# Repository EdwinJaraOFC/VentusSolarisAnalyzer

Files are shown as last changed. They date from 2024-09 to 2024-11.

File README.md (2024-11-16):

<p align="left">
  
  <h1 align="center">VentusSolaris Analyzer: A Low-Cost Portable Kit for Renewable Energy Evaluation</h1>
</p>

## Descripción General

<p align="justify"><strong>VentusSolaris Analyzer</strong> es una solución portátil de bajo costo diseñada para evaluar el potencial de energías renovables en diversas ubicaciones. Este kit combina la medición de energía solar y eólica, ofreciendo a estudiantes, investigadores y profesionales una herramienta accesible para obtener datos precisos y en tiempo real.</p>

<p align="justify">Concebido dentro de un entorno académico, este proyecto tiene como objetivo acercar la tecnología de análisis de energías renovables a aquellos interesados en el impacto y la viabilidad de estas soluciones en diferentes regiones.</p>

### ODS 7: Energía Asequible y no Contaminante

<p align="justify">Tiene como objetivo garantizar el acceso a una energía asequible, fiable, sostenible y moderna para todos. Este objetivo busca aumentar la proporción de energía renovable en el consumo global, mejorar la eficiencia energética y proporcionar acceso a servicios energéticos básicos, especialmente en regiones rurales y en desarrollo. Además, fomenta la inversión en infraestructura y tecnologías de energía sostenible, contribuyendo así a la lucha contra el cambio climático y a la promoción de un desarrollo económico inclusivo.</p>

## Características Principales

- 🌞 **Energía Solar**: Medición eficiente de la radiación solar.
- 🌬️ **Energía Eólica**: Monitorización de la velocidad del viento para evaluar el potencial eólico.
- 📊 **Interfaz Intuitiva**: Presentación clara y visualización de los datos recopilados.
- 💼 **Portabilidad**: Diseño compacto y ligero, ideal para trabajos de campo.
- 💡 **Accesibilidad**: Tecnología asequible sin comprometer la precisión ni la funcionalidad.

## Estructura del Proyecto

```bash
VentusSolarisAnalyzer/
├── AcercaDeNosotros/       # Información sobre el equipo o el propósito del proyecto
├── Documentacion/          # Documentación técnica y material explicativo del proyecto
│   ├── Investigacion/      # Estudios y análisis preliminares
│   ├── Presentaciones/     # Material gráfico y de presentación
│   ├── Talleres/           # Documentación y recursos de talleres
│
├── Prototipo/              # Detalles del prototipo del proyecto
│   ├── Diseño/             # Planos, esquemas y documentación de diseño
│   ├── Hardware/           # Especificaciones y esquemas del hardware
│   ├── Software/           # Código fuente y documentación del software
│   ├── Tests/              # Resultados y documentación de pruebas del prototipo
│
├── .gitignore              # Archivos y carpetas ignorados por Git
├── LICENSE                 # Licencia del proyecto
└── README.md               # Este archivo principal con información general del proyecto
```

## Motivación y Contexto
<p align="justify">El acceso a herramientas confiables para la evaluación de energías renovables suele estar limitado por altos costos y falta de accesibilidad. VentusSolaris Analyzer nace con la intención de democratizar la evaluación energética, proporcionando una alternativa portátil y económica que puede ser implementada en áreas urbanas o rurales.</p>

<p align="justify">Este proyecto también responde a la necesidad académica de ofrecer a los estudiantes experiencias prácticas en el uso de tecnologías renovables, facilitando la comprensión de conceptos como energía solar fotovoltaica y energía eólica en escenarios reales.</p>

## Resultados Esperados
Con VentusSolaris Analyzer, se espera lograr:

- Datos precisos en la medición de energías renovables en diferentes entornos.
- Facilidad de uso en investigaciones de campo, donde la portabilidad es clave.
- Prototipos escalables, que puedan mejorarse y adaptarse a necesidades más complejas en futuras iteraciones.

<p align="justify">Estos logros contribuirán no solo al campo académico, sino también a la posibilidad de implementación en proyectos de desarrollo sostenible en comunidades con acceso limitado a recursos energéticos.</p>

## Nuestro Equipo

| Miembro | Rol | Función Principal | Correo |
| :---: | :---: | :---: | :---: |
| **Florian Párraga, Josué Abel** | Desarrollo Técnico | Prototipado y desarrollo técnico | josue.florian@upch.pe |
| **Jara Bocanegra, Edwin Junior** | Desarrollo Técnico | Prototipado y desarrollo técnico | edwin.jara@upch.pe |
| **Pérez Amado, Romina Alisson** | Investigación | Investigación sobre energías renovables | romina.perez@upch.pe |
| **Pérez Damián, Cindy Mayomi** | Investigación | Investigación sobre energías renovables | cindy.perez@upch.pe |
| **Vásquez Nuñez, America Mailyn** | Investigación | Investigación sobre energías renovables | america.vasquez@upch.pe |

## Documentación y Recursos
<p align="justify">Toda la documentación técnica y manuales de usuario pueden encontrarse en la carpeta docs/, donde se detalla el funcionamiento interno del sistema, guías de uso y especificaciones de hardware. Además, en la carpeta examples/ se incluyen ejemplos para facilitar la configuración del kit en diferentes entornos.</p>

## Identificación del TRL del Proyecto
### Motor DC para el anemómetro

<p align="justify">En este proyecto, se va a medir la velocidad del viento en (m/s) mediante un sistema basado en un anemómetro conectado a un motor. El funcionamiento del sistema se activa cuando el viento hace girar las hélices del anemómetro. Estas hélices, al girar, no solo registran el movimiento del viento, sino que también generan electricidad al cortar las líneas del campo magnético en el motor. Este proceso, a través del motor DC nos permite generar una corriente eléctrica que se relaciona directamente con la velocidad del viento, facilitando así una medición precisa a partir del voltaje generado.</p>
  
<p align="center">
  
</p>

### Sensor de radiación

<p align="justify">En este proyecto, vamos a medir uno de los parámetros qué es  la irradiancia solar, a través del sensor de 527-SUF268J00, el cual mide la irradiación en watts por metro cuadrado (W/m²). Este sensor funciona mediante la captura de luz solar que incide sobre un material semiconductor, comúnmente silicio. La energía de los fotones de la luz excita los electrones en el semiconductor, creando pares de electrones y huecos. Al separarse, estos generan una corriente eléctrica; cuanto mayor es la luz recibida, mayor es la corriente producida. Esta corriente se convierte en un voltaje que representa la cantidad de luz que está recibiendo el sensor. Para garantizar que las lecturas sean precisas. Además, cuenta con recubrimientos protectores que resguardan su funcionamiento frente a la humedad y la radiación UV, asegurando así su durabilidad y eficacia en diversas condiciones ambientales.</p>

Especificaciones técnicas: 

- Fuente de luz: Luz del sol
- Método de conexión: 2-Pin
- Configuración de salida: Fotodiodo
- Temperatura de trabajo mínima: -30 C
- Temperatura de trabajo máxima: +80 C
- Características: Tiempo de respuesta rápido

<p align="center">
  
</p>

### Sensor de Ondas de Radio

<p align="justify">El funcionamiento del sensor de ondas de radio, es fundamental para la recepción de señales que viajan a través del aire. Este sensor utiliza una antena para captar las ondas de radio, que son oscilaciones electromagnéticas. Cuando estas ondas llegan a la antena, inducen el movimiento de electrones en el material conductor de la antena, lo que genera pequeñas corrientes eléctricas. Estas corrientes son directamente proporcionales a la energía de las ondas de radio que están siendo recibidas. La corriente generada se convierte en una señal eléctrica que representa la información contenida en las ondas, como voz, música o datos digitales. Esta señal eléctrica se amplifica para mejorar su calidad y se procesa mediante circuitos electrónicos que extraen la información deseada.</p>

Especificaciones técnicas:

- Voltaje de alimentación: 1.9 ~ 3.6V DC
- Voltaje lógico SPI: 0 ~ 3.3V / 5V (Tolerante a 5V)
- Consumo corriente: 115 mA (max.)
- Chip RF: NRF24L01+
- Chip PA+LNA: RFX2401C
- Interfaz digital: SPI
- Potencia de transmisión: +20 dBm
  
<p align="center">
  
</p>

## Licencia
<p align="justify">Este proyecto está licenciado bajo la Licencia Apache-2.0, lo que permite su uso, modificación y distribución para fines académicos y comerciales, siempre y cuando se otorgue el crédito adecuado.</p>

## Contacto
<p align="justify">Si tienes alguna duda, sugerencia o interés en colaborar con el proyecto, no dudes en ponerte en contacto con nosotros a través de nuestros correos electrónicos.</p>

<a href="https://github.com/EdwinJaraOFC/VentusSolarisAnalyzer/blob/main/AcercaDeNosotros/README.md">Haz click aquí</a>
</p>

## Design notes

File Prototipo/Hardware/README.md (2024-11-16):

<p align="left">
  
  <h1 align="center">Hardware</h1>
</p>

<p align="justify">Esta carpeta incluye toda la documentación y recursos técnicos relacionados con los componentes físicos y electrónicos del proyecto VentusSolaris Analyzer. Aquí se detalla desde el diseño esquemático hasta los planos finales necesarios para la construcción del prototipo.</p>

## Contenido

- <strong>H01EsquematicoElectronico:</strong> Diagramas de circuitos electrónicos que representan las conexiones y componentes principales.

- <strong>H02ModeladoPCB:</strong> Diseño de las placas de circuito impreso (PCB) utilizadas en el prototipo.

- <strong>H03Modelado3D:</strong> Modelos tridimensionales de los componentes y estructuras físicas.

- <strong>H04Planos:</strong> Planos detallados con especificaciones técnicas para la fabricación del hardware.

## Uso

- Revisa los esquemáticos electrónicos para entender las conexiones del circuito.
- Consulta el modelado PCB para la fabricación y ensamblaje de las placas.
- Explora los modelos 3D para visualizar y evaluar la estructura física del hardware.
- Utiliza los planos como guía técnica para la construcción del prototipo.

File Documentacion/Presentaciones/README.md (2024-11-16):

<p align="left">
  
  <h1 align="center">Presentaciones</h1>
</p>

<p align="justify">Esta carpeta incluye materiales visuales diseñados para comunicar el alcance, los fundamentos y los resultados del proyecto VentusSolaris Analyzer. Estos recursos son ideales para exposiciones académicas, reuniones técnicas y presentaciones públicas.</p>

## Contenido

- <strong>Fundamentos de Diseño:</strong> Diapositivas explicativas sobre los principios y conceptos clave del diseño del proyecto.

- <strong>Proyectos de Ingeniería:</strong> Presentaciones que destacan el impacto técnico y la implementación del prototipo.

## Uso

<p align="justify">Selecciona la carpeta correspondiente según el contexto de tu presentación para acceder a los materiales preparados. Estos recursos están organizados para facilitar la adaptación a diferentes audiencias y escenarios.</p>

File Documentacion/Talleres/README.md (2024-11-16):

<p align="left">
  
  <h1 align="center">Talleres</h1>
</p>

<p align="justify">Esta carpeta contiene materiales y recursos relacionados con los talleres impartidos en los cursos Fundamentos de Diseño y Proyectos de Ingeniería 1. Estos talleres están enfocados en brindar a los estudiantes conocimientos prácticos sobre el desarrollo de proyectos tecnológicos, desde la conceptualización hasta la implementación.</p>

## Contenido

### Taller 01 al Taller 09

<p align="justify">Cada taller está diseñado para profundizar en conceptos clave relacionados con el desarrollo de proyectos tecnológicos, incluyendo:</p>

- Metodologías de diseño.
- Selección y uso de tecnologías apropiadas.
- Gestión y planificación de proyectos.
- Resolución de problemas técnicos.

## Uso

1. <strong>Selecciona el taller correspondiente al curso y tema de interés:</strong> Los talleres están organizados en secuencia para facilitar el aprendizaje progresivo.

2. <strong>Explora los materiales dentro de cada taller:</strong> Incluyen guías, ejercicios prácticos y ejemplos relevantes.

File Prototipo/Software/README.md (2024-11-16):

<p align="left">
  
  <h1 align="center">Código Fuente</h1>
</p>

Esta carpeta contiene el código fuente del proyecto **VentusSolaris Analyzer**.

## Estructura

- **`main.py`**: Archivo principal para ejecutar el sistema.
- **Módulos**:
  - `sensor_solar.py`: Control y procesamiento de datos del sensor solar.
  - `sensor_eolico.py`: Control y procesamiento de datos del sensor eólico.
  - `interface.py`: Interfaz para mostrar los datos recopilados.

## Cómo Ejecutar

1. Asegúrate de tener instaladas las dependencias necesarias:
   ```bash
   pip install -r requirements.txt

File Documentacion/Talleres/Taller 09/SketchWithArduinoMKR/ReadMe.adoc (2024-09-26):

:Author: alumno_upch
:Email:
:Date: 19/09/2024
:Revision: version#
:License: Public Domain

= Project: {Project}

Describe your project

== Step 1: Installation
Please describe the steps to install this project.

For example:

1. Open this file
2. Edit as you like
3. Release to the World!

== Step 2: Assemble the circuit

Assemble the circuit following the diagram layout.png attached to the sketch

== Step 3: Load the code

Upload the code contained in this sketch on to your board

=== Folder structure

....
 sketch123                => Arduino sketch folder
  ├── sketch123.ino       => main Arduino file
  ├── schematics.png      => (optional) an image of the required schematics
  ├── layout.png          => (optional) an image of the layout
  └── ReadMe.adoc         => this file
....

=== License
This project is released under a {License} License.

=== Contributing
To contribute to this project please contact: 

=== BOM
Add the bill of the materials you need for this project.

|===
| ID | Part name      | Part number | Quantity
| R1 | 10k Resistor   | 1234-abcd   | 10       
| L1 | Red LED        | 2345-asdf   | 5        
| A1 | Arduino Zero   | ABX00066    | 1        
|===

=== Help
This document is written in the _AsciiDoc_ format, a markup language to describe documents. 
If you need help you can search the http://www.methods.co.nz/asciidoc[AsciiDoc homepage]
or consult the http://powerman.name/doc/asciidoc[AsciiDoc cheatsheet]

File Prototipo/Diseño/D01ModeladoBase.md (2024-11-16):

<p align="left">
  
  <h1 align="center">Modelado Base</h1>
</p>

## Proyecto Ganador y Pretotipo
<p align="center">
  
  
</p>

## Dimensiones Preliminares
<p align="center">
  
  
</p>
<p align="center">
  
</p>

## Modelado 3D

- **Link de Modelado 3D en Onshape:**<br>https://cad.onshape.com/documents/6067460ba82017ad390b8bbe/w/b210f3430e2e64227f715d53/e/26216eeab57c46d8af5b41a8
- **Link de Modelado 3D en SketchFab:**<br>https://skfb.ly/oQHG9
<p align="center">
  
  
</p>

## Tabla de Componentes
<p align="center">
  
</p>

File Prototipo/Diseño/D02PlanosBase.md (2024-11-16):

<p align="left">
  
  <h1 align="center">Planos del Modelado 3D</h1>
</p>

<a href="https://github.com/Paradoxeado/prototypeProject/tree/main/Prototipado/Hardware">Carpeta de Componentes 3D y Planos</a>
</p>

## Plano: Maleta

<p align="center">
  
</p>

## Plano: Tapa para la Batería Portátil

<p align="center">
  
</p>

## Plano: Tapa de la Caja del Anemómetro

<p align="center">
  
</p>

## Plano: Anemómetro

<p align="center">
  
</p>

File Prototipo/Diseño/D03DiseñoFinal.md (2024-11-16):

<p align="left">
  
  <h1 align="center">Diseño Final del Proyecto</h1>
</p>

## Acerca de nuestro Modelado 3D

<p align="center">
  
  
</p>

## Esquemático Electrónico

<p align="center">
  
</p>
<p align="center">
  
</p>
<a href="https://github.com/Paradoxeado/prototypeProject/blob/main/Prototipado/Hardware/EsquematicoElectronico.pdf">Enlace al Esquemático Electrónico en formato PDF</a>
</p>
<p align="center">
  
</p>

## Diagrama de Flujo

<a href="https://github.com/Paradoxeado/prototypeProject/blob/main/Prototipado/Software/DiagramaDeFlujo.pdf">Enlace al Diagrama de Flujo en formato PDF</a>
</p>

<p align="center">
  
</p>

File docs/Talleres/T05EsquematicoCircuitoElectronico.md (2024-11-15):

<p align="center" style="margin-top: 50px; margin-bottom: 50px; font-family: Arial, sans-serif;">
  <p align="center">
    Facultad de Ciencias e ingeniería logo
  </p>  
  <h1 align="center" style="margin-top: 30px; margin-bottom: 0px;">Facultad de Ciencias e ingeniería “Alberto Cazorla Talleri”</h1>
</p>

<h2 align="center" style="font-family: Arial, sans-serif;">Taller 05: Esquemático del Circuito Electrónico</h2>

<strong> Docentes:</strong>
- Mg Umbert Lewis De La Cruz
- Mg. Paulo Camilo Vela Antón 
- Mg. Moises Stevend Meza Rodriguez 
- Dr. Harry Anderson Rivera Tito 
- Ing. Juan Manuel Zuñiga Mamani  
- Ing. Renzo José Chan Ríos

<strong>Elaborado por:</strong>
- Amparo Marleny Vidaurre Juárez
- Edwin Junior Jara Bocanegra
- Antony Iván Mendoza Villar
- Josue Jhordan Poma Arrieta
- Aracely Nicoll Dueñas Condori
</p>

<hr style="border: 1px solid #ccc; margin-top: 50px; margin-bottom: 50px;">

## 1. Introducción
<p align="justify">
Un esquemático de un circuito electrónico es un dibujo que representa los componentes del circuito y cómo están conectados entre sí. Es una herramienta visual que facilita la comprensión y el diseño de circuitos electrónicos. En un esquemático, los componentes como resistencias, capacitores, transistores, etc., se representan con símbolos estandarizados.
</p>

## 2. Descripción del sistema de circuito electrónico
### Características y componentes del el sistema de circuito electrónico
<p align="justify">
  
- **Componentes electrónicos:** Incluyen resistencias, capacitores, inductores, diodos, transistores, circuitos integrados, entre otros.
- **Fuente de alimentación:** Proporciona la energía necesaria para que el circuito funcione correctamente.
- **Conectores y terminales:** Permiten la conexión física del circuito con otros dispositivos o sistemas.
- **Circuitos integrados:** Chips que contienen múltiples componentes electrónicos en un solo paquete.
- **Placas de circuito impreso (PCB):** Proporcionan la estructura física para montar y conectar los componentes electrónicos de forma ordenada.
- **Conexiones eléctricas:** Representan cómo se conectan los componentes entre sí para que el circuito funcione según el diseño.
</p>

### Importancia del sistema de circuito electrónico

<p align="justify">
Los sistemas de circuitos electrónicos son fundamentales para el desarrollo y funcionamiento de la tecnología moderna, desempeñando un papel crucial en nuestra vida cotidiana y en el progreso de la sociedad en su conjunto.
</p>

## 3. Ejercicios
### Ejercicio 1: Crear un sistema que pueda encender un LED
<p align="justify">
Con la ayuda del docente, pudimos crear un sistema el cual puede encender un led con los siguientes  implementos, resistencia genérica, led y un terminal de tornillo de 2 posiciones.
</p>

<div align="center"; style="display: flex; justify-content: space-between;">
  
  
  
</div>

<p align="justify">
Posteriormente, modificamos el valor de la resistencia a 330 ohmios para optimizar el circuito.
</p>

<div align="center"; style="display: flex; justify-content: space-between;">
  
</div>

<p align="justify">

A continuación, procedimos a unir los componentes siguiendo los siguientes pasos:
- Conectar una de las cables del LED al terminal de tornillo.
- Conectar la resistencia de 330 ohmios a la otra pata del LED.
- Conectar el extremo libre de la resistencia al otro terminal del tornillo.
- Finalmente, asegurar que todas las conexiones estén firmes y seguras.
</p>

<div align="center"; style="display: flex; justify-content: space-between;">
  
</div>

<p align="justify">
  
**Vista Previa en 2D**
</p>

<div align="center"; style="display: flex; justify-content: space-between;">
  
</div>

<p align="justify">

**Vista Previa en 3D**
</p>

<div align="center"; style="display: flex; justify-content: space-between;">
  
  
  
</div>

### Ejercicio 2: Crear un circuito que guarde relación con nuestro proyecto
<p align="justify">
El circuito desarrollado para este ejercicio ha sido diseñado para complementar y potenciar los objetivos de nuestro proyecto principal. Su función principal es activar un LED mediante un botón o pulsador, desempeñando un papel esencial en el logro de nuestros objetivos. Se ha asegurado una integración perfecta con la arquitectura general del proyecto, garantizando una sinergia fluida entre todos los componentes. Además, se ha prestado especial atención a la modularidad, lo que facilita su expansión o adaptación futura según sea necesario.
</p>

<p align="justify">
Para la construcción de este circuito, hemos seleccionado cuidadosamente los siguientes componentes, cada uno desempeñando un papel crucial en el funcionamiento del sistema:

- 3 Resistencias de 330 ohmios
- 2 Botones/pulsadores
- 1 ESP32
- 1 LED

Al ensamblar estos componentes en el circuito, hemos prestado especial atención a la calidad de las conexiones eléctricas, evitando cualquier posibilidad de falsos contactos que puedan afectar el rendimiento del sistema. Quedando el circuito de la siguiente manera:
</p>

**Vista Previa en 2D**
<div align="center"; style="display: flex; justify-content: space-between;">
  
  
</div>

**Vista Previa en 3D**
<div align="center"; style="display: flex; justify-content: space-between;">
  
  
</div>
<div align="center"; style="display: flex; justify-content: space-between;">
  
  
</div>

## 4. Evidencias del desarrollo de ejercicios

<div align="center"; style="display: flex; justify-content: space-between;">
  
</div>

## 5. Conclusión
<p align="justify">
Finalmente ,en nuestro taller, aprendimos a utilizar las funciones de Flux.ai para diseñar un sistema que encienda un LED y conectar un ESP32 a una pantalla LCD con las resistencias necesarias. Además, exploramos cómo añadir funcionalidades adicionales mediante la programación de circuitos. Con estos conocimientos, podemos crear proyectos electrónicos de manera más eficiente y estética.
</p>

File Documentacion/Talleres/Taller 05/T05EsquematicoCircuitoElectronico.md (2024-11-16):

<p align="left">
  
  <h1 align="center">Taller 05: Esquemático del Circuito Electrónico</h1>
</p>

## 1. Introducción
<p align="justify">
Un esquemático de un circuito electrónico es un dibujo que representa los componentes del circuito y cómo están conectados entre sí. Es una herramienta visual que facilita la comprensión y el diseño de circuitos electrónicos. En un esquemático, los componentes como resistencias, capacitores, transistores, etc., se representan con símbolos estandarizados.
</p>

## 2. Descripción del sistema de circuito electrónico
### Características y componentes del el sistema de circuito electrónico
<p align="justify">
  
- **Componentes electrónicos:** Incluyen resistencias, capacitores, inductores, diodos, transistores, circuitos integrados, entre otros.
- **Fuente de alimentación:** Proporciona la energía necesaria para que el circuito funcione correctamente.
- **Conectores y terminales:** Permiten la conexión física del circuito con otros dispositivos o sistemas.
- **Circuitos integrados:** Chips que contienen múltiples componentes electrónicos en un solo paquete.
- **Placas de circuito impreso (PCB):** Proporcionan la estructura física para montar y conectar los componentes electrónicos de forma ordenada.
- **Conexiones eléctricas:** Representan cómo se conectan los componentes entre sí para que el circuito funcione según el diseño.
</p>

### Importancia del sistema de circuito electrónico

<p align="justify">
Los sistemas de circuitos electrónicos son fundamentales para el desarrollo y funcionamiento de la tecnología moderna, desempeñando un papel crucial en nuestra vida cotidiana y en el progreso de la sociedad en su conjunto.
</p>

## 3. Ejercicios
### Ejercicio 1: Crear un sistema que pueda encender un LED
<p align="justify">
Con la ayuda del docente, pudimos crear un sistema el cual puede encender un led con los siguientes  implementos, resistencia genérica, led y un terminal de tornillo de 2 posiciones.
</p>

<div align="center"; style="display: flex; justify-content: space-between;">
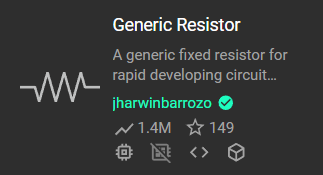
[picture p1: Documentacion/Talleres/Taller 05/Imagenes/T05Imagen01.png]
  
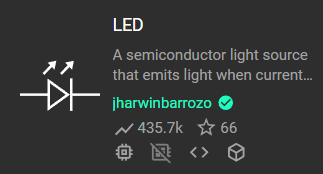
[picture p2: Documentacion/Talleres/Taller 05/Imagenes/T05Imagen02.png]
  
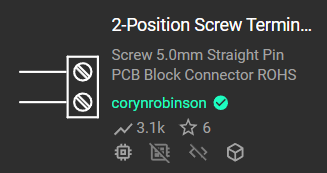
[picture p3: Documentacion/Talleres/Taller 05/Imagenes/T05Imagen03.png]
  
</div>

<p align="justify">
Posteriormente, modificamos el valor de la resistencia a 330 ohmios para optimizar el circuito.
</p>

<div align="center"; style="display: flex; justify-content: space-between;">
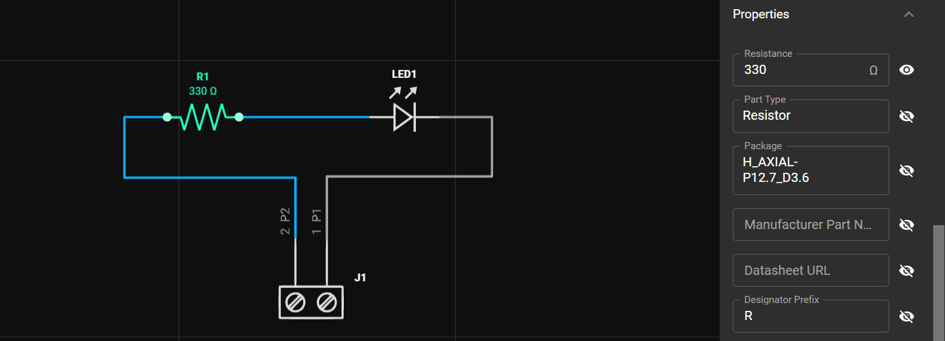
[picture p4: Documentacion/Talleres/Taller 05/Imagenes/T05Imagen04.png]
  
</div>

<p align="justify">

A continuación, procedimos a unir los componentes siguiendo los siguientes pasos:
- Conectar una de las cables del LED al terminal de tornillo.
- Conectar la resistencia de 330 ohmios a la otra pata del LED.
- Conectar el extremo libre de la resistencia al otro terminal del tornillo.
- Finalmente, asegurar que todas las conexiones estén firmes y seguras.
</p>

<div align="center"; style="display: flex; justify-content: space-between;">
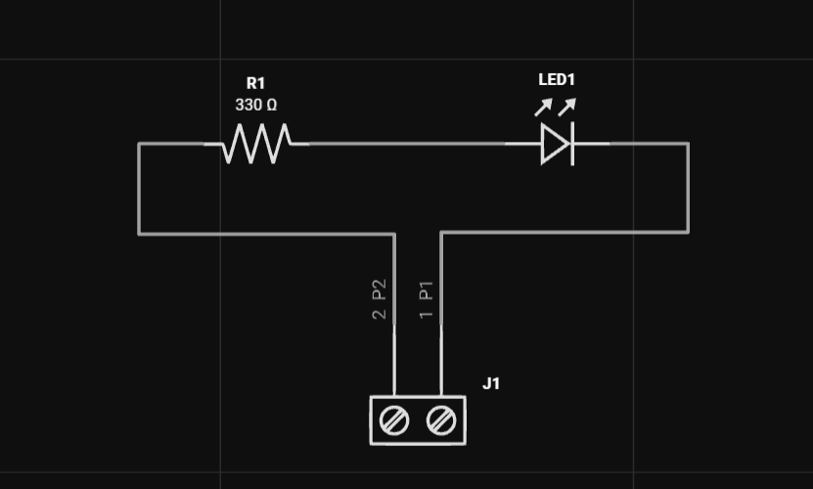
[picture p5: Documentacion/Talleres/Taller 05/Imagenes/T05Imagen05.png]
  
</div>

<p align="justify">
  
**Vista Previa en 2D**
</p>

<div align="center"; style="display: flex; justify-content: space-between;">
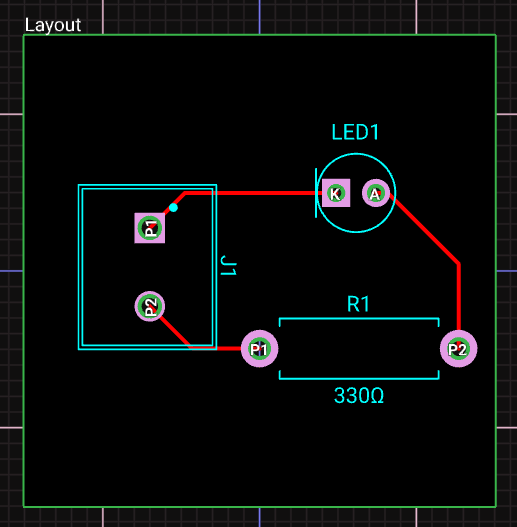
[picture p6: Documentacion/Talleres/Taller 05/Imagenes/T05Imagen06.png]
  
</div>

<p align="justify">

**Vista Previa en 3D**
</p>

<div align="center"; style="display: flex; justify-content: space-between;">
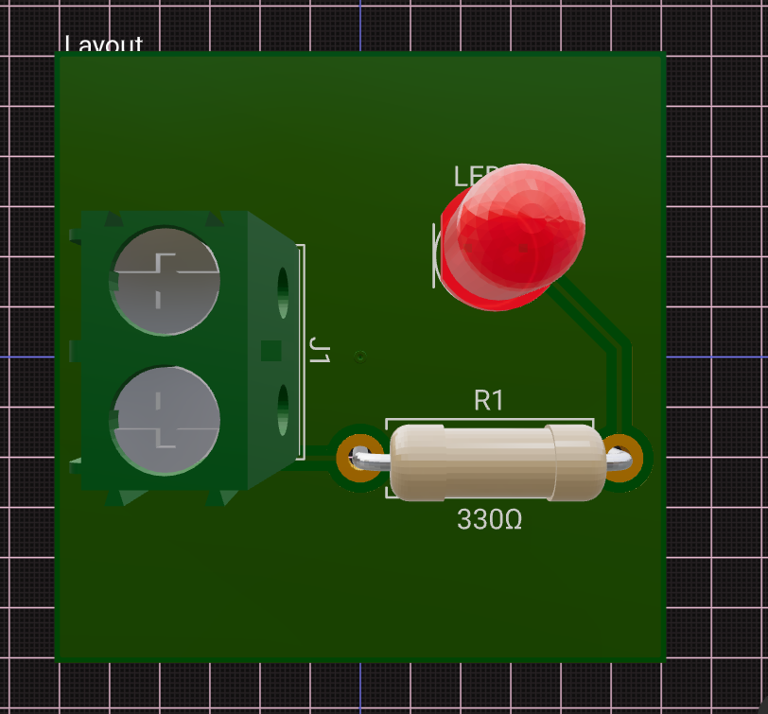
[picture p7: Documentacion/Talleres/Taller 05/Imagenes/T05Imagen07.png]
  
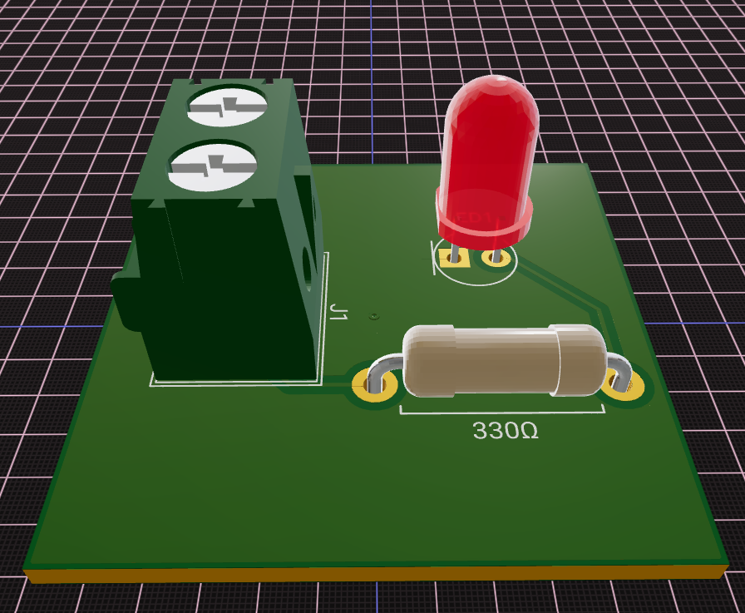
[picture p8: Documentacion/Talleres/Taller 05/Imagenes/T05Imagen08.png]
  
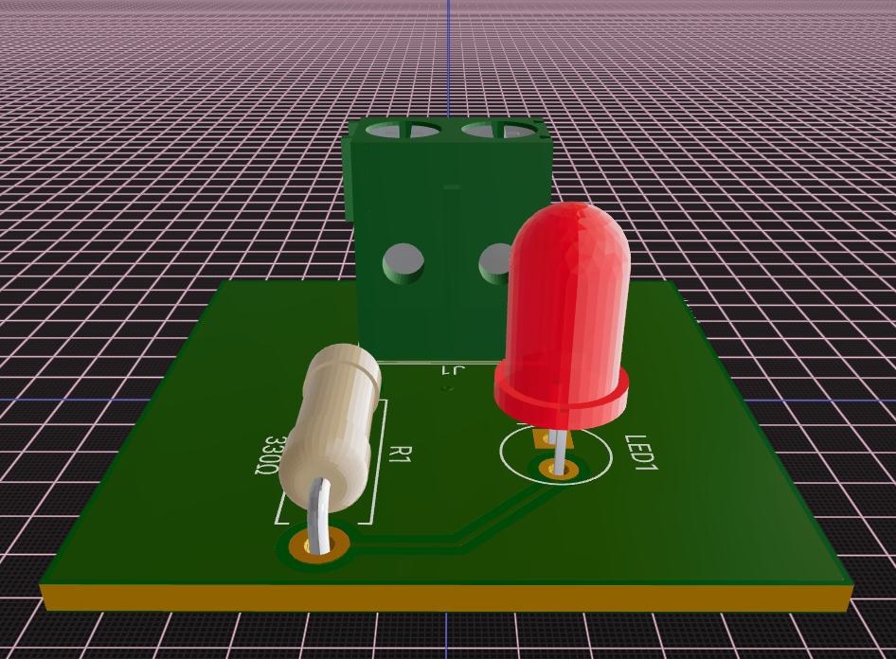
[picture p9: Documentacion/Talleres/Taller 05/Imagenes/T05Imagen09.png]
  
</div>

### Ejercicio 2: Crear un circuito que guarde relación con nuestro proyecto
<p align="justify">
El circuito desarrollado para este ejercicio ha sido diseñado para complementar y potenciar los objetivos de nuestro proyecto principal. Su función principal es activar un LED mediante un botón o pulsador, desempeñando un papel esencial en el logro de nuestros objetivos. Se ha asegurado una integración perfecta con la arquitectura general del proyecto, garantizando una sinergia fluida entre todos los componentes. Además, se ha prestado especial atención a la modularidad, lo que facilita su expansión o adaptación futura según sea necesario.
</p>

<p align="justify">
Para la construcción de este circuito, hemos seleccionado cuidadosamente los siguientes componentes, cada uno desempeñando un papel crucial en el funcionamiento del sistema:

- 3 Resistencias de 330 ohmios
- 2 Botones/pulsadores
- 1 ESP32
- 1 LED

Al ensamblar estos componentes en el circuito, hemos prestado especial atención a la calidad de las conexiones eléctricas, evitando cualquier posibilidad de falsos contactos que puedan afectar el rendimiento del sistema. Quedando el circuito de la siguiente manera:
</p>

**Vista Previa en 2D**
<div align="center"; style="display: flex; justify-content: space-between;">
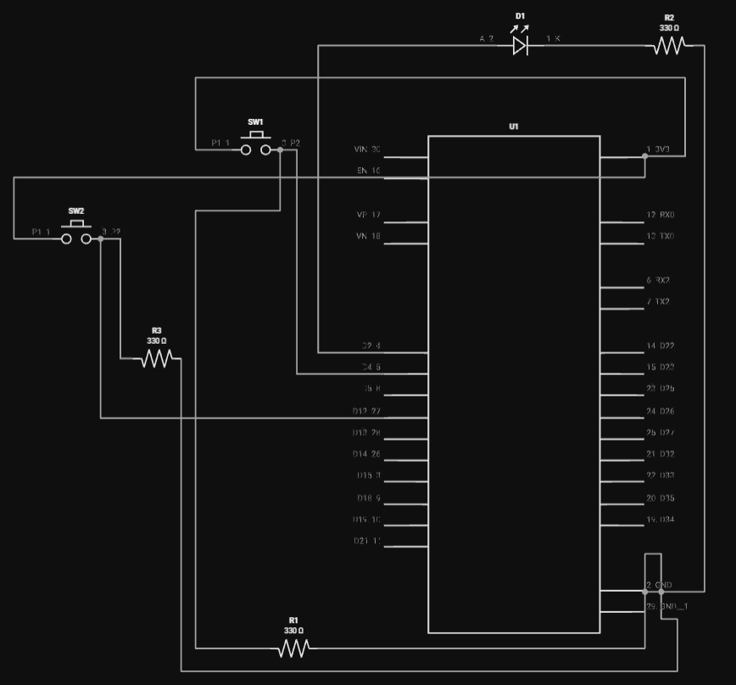
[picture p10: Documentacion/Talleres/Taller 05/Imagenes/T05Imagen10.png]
  
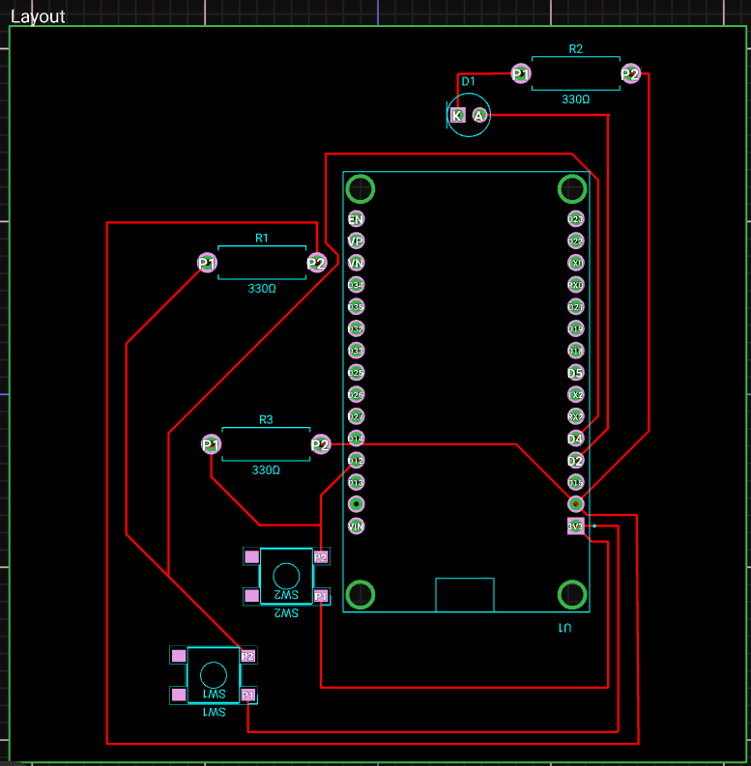
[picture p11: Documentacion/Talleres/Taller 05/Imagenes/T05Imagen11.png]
  
</div>

**Vista Previa en 3D**
<div align="center"; style="display: flex; justify-content: space-between;">
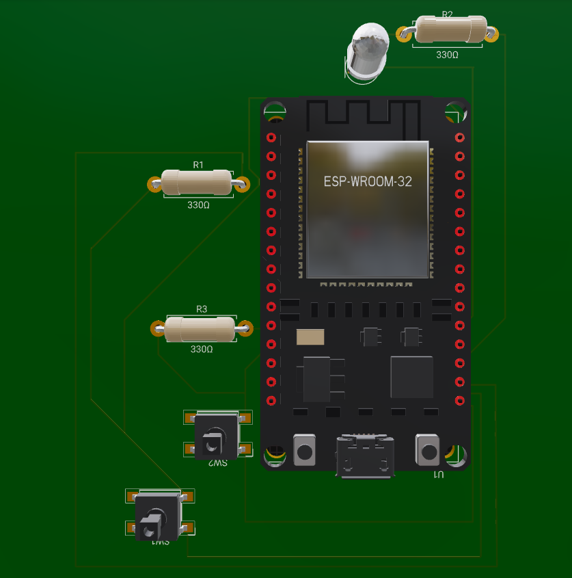
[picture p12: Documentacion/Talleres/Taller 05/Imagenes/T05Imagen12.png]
  
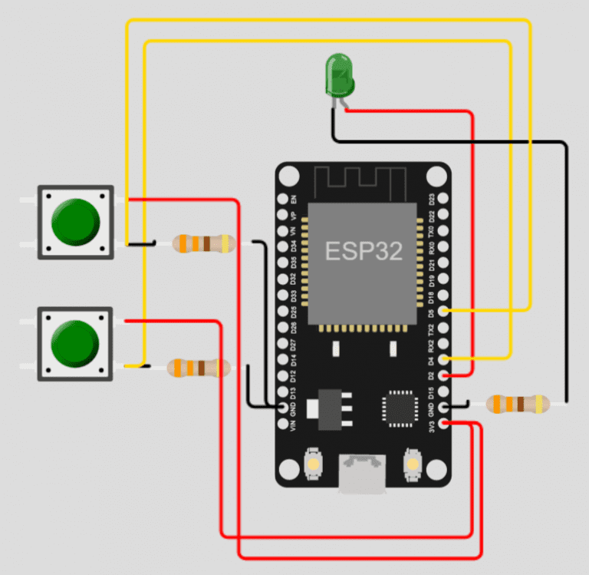
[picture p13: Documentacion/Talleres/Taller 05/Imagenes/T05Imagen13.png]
  
</div>
<div align="center"; style="display: flex; justify-content: space-between;">
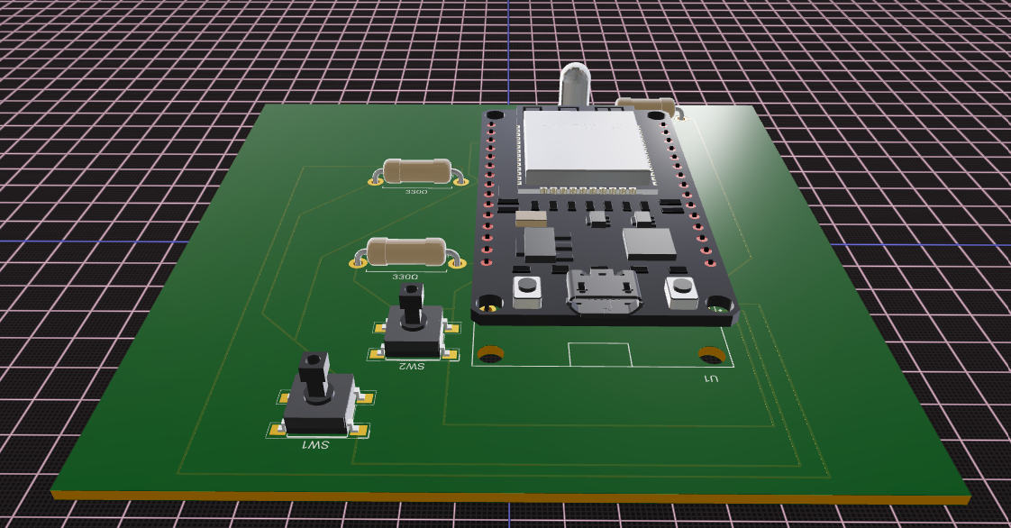
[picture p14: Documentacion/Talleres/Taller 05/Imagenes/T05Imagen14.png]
  
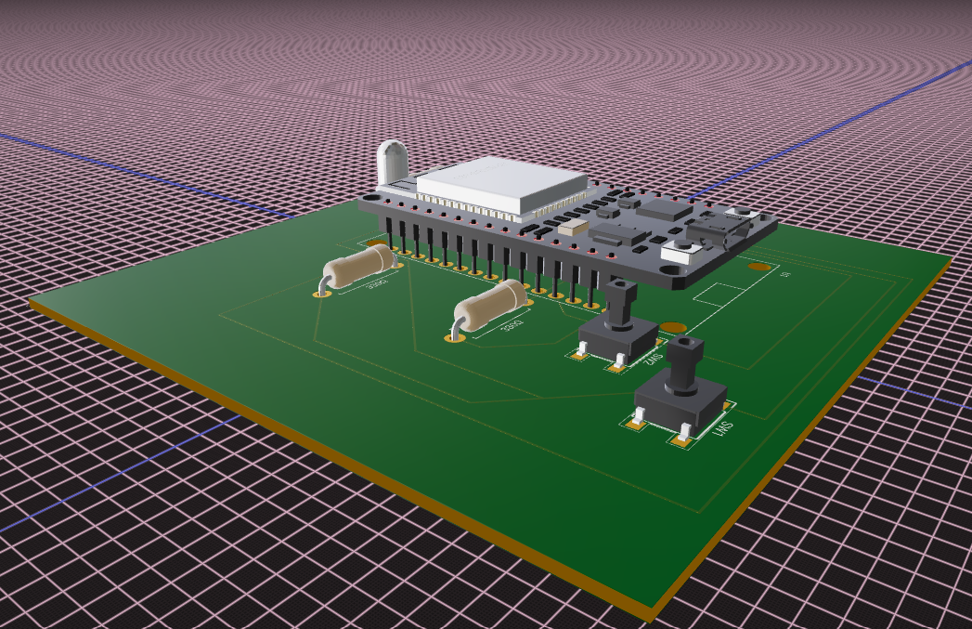
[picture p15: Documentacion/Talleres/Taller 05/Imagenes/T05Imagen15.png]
  
</div>

## 4. Evidencias del desarrollo de ejercicios

<div align="center"; style="display: flex; justify-content: space-between;">
  
</div>

## 5. Conclusión
<p align="justify">
Finalmente ,en nuestro taller, aprendimos a utilizar las funciones de Flux.ai para diseñar un sistema que encienda un LED y conectar un ESP32 a una pantalla LCD con las resistencias necesarias. Además, exploramos cómo añadir funcionalidades adicionales mediante la programación de circuitos. Con estos conocimientos, podemos crear proyectos electrónicos de manera más eficiente y estética.
</p>

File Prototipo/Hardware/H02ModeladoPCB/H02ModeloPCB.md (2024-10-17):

<p align="left">
  
  <h1 align="center">Entregable 07: Modelo PCB</h1>
</p>

## Introducción

<p align="justify">Este informe presenta el diseño y los componentes clave de un sistema portátil diseñado para medir la velocidad del viento y la radiación solar. El objetivo de este proyecto es evaluar la viabilidad de instalar aerogeneradores y paneles solares en áreas específicas, proporcionando datos precisos y en tiempo real. El sistema está basado en un microcontrolador Arduino Nano, que se conecta a un sensor SUF268J001 para medir la radiación solar y a un anemómetro casero, construido a partir de un motor RF-500TB-14415, para medir la velocidad del viento. Los datos se visualizan en una pantalla I2C, y todo el sistema es alimentado por una batería portátil, lo que lo hace ideal para ser utilizado en campo. Además, el uso de conectores Molex facilita la conexión modular de los componentes, permitiendo un mantenimiento y ajustes sencillos.</p>

## Esquemático Electrónico

<p align="center">
  
</p>
<p align="center">
  
</p>

## Modelo PCB

<p align="center">
  
  
</p>

## Componentes Utilizados

### 1. Arduino Nano (Microcontrolador Principal)
#### Pines importantes
- **5V**: Proporciona alimentación a los sensores y la pantalla I2C.
- **GND**: Conecta a tierra todos los componentes.
- **A0**: Entrada analógica conectada a la salida del **sensor de radiación solar SUF268J001**.
- **A1**: Entrada analógica conectada al **anemómetro casero (Motor RF-500TB-14415)** para medir la velocidad del viento.
- **A4**: Conecta al pin **SDA** de la **pantalla I2C** para la comunicación serial.
- **A5**: Conecta al pin **SCL** de la **pantalla I2C** para la comunicación serial.

### 2. Sensor de Radiación Solar SUF268J001
- **Función**: Medir la intensidad de la radiación solar.

#### Conexiones
- **Pin 1 (VCC)**: Conecta al **pin 5V** del Arduino Nano.
- **Pin 2 (Señal)**: Conectado a una resistencia de 1 kΩ (R1), y de ahí a la **entrada analógica A0** del Arduino Nano.
- **Resistencia R2 (100 Ω)**: Conectada en paralelo entre el nodo A0 y un capacitor de 100 nF (C1) que va a GND.
- **GND**: Conecta directamente a tierra (GND) del Arduino Nano.

### 3. Anemómetro Casero (Motor RF-500TB-14415)
- **Función**: Mide la velocidad del viento en función de las revoluciones del motor.

#### Conexiones
- **VCC**: Conecta al pin **5V** del Arduino Nano.
- **GND**: Conecta al pin **GND** del Arduino Nano.
- **Señal**: Conectado a la **entrada A1** del Arduino Nano.

### 4. Pantalla I2C
- **Función**: Muestra los valores de radiación solar y velocidad del viento en tiempo real.

#### Conexiones
- **VCC**: Conecta al pin **5V** del Arduino Nano.
- **GND**: Conecta al pin **GND** del Arduino Nano.
- **SDA**: Conectado al pin **A4** del Arduino Nano.
- **SCL**: Conectado al pin **A5** del Arduino Nano.

### 5. Conectores Molex
- **Función**: Facilitan la conexión modular de los sensores y la pantalla.

#### Conexiones
- Cada conector Molex tiene tres pines: alimentación (**VCC**), tierra (**GND**), y señal de salida. Estos se conectan entre los sensores/pantalla y los pines correspondientes del Arduino Nano:
  - **Sensor SUF268J001**: Conector Molex de 2 pines (VCC y Señal).
  - **Anemómetro (Motor)**: Conector Molex de 3 pines (VCC, GND y Señal).
  - **Pantalla I2C**: Conector Molex de 4 pines (VCC, GND, SDA, SCL).

### 6. Batería Portátil
- **Función**: Proporciona alimentación al sistema a través del pin **Vin** del Arduino Nano, regulando el voltaje a **5V** para todos los componentes.

## Proceso de Diseño del PCB

### 1. Esquemático
<p align="justify">Se diseñó el esquema eléctrico utilizando EasyEDA, asegurando que todos los componentes estuvieran conectados de manera eficiente y modular mediante conectores Molex. La disposición de los componentes en la PCB fue optimizada para reducir la longitud de las pistas y maximizar el espacio, manteniendo las conexiones limpias y bien organizadas. Durante el ruteo automático, se prestó especial atención a evitar cruces entre las pistas y asegurar que la señal de los sensores no sufriera interferencias, lo cual se logró dividiendo las conexiones entre la capa superior (rojo) y la capa inferior (azul).</p>

### 2. Conversión a PCB
<p align="justify">Se convirtió el esquema en un diseño de PCB, optimizando la disposición de los componentes y conectores para reducir la longitud de las pistas y maximizar el espacio disponible.</p>

### 3. Ruteo Automático
Se utilizó el ruteo automático en EasyEDA, con dos capas:
- **Capa superior (Rojo)**: Para las conexiones principales de datos y alimentación.
- **Capa inferior (Azul)**: Para evitar cruces de pistas y mantener el diseño compacto.

## Flujo de Comunicación entre los Componentes

### 1. Alimentación del Sistema
<p align="justify">La batería portátil suministra energía al sistema a través del pin Vin del Arduino Nano, el cual regula el voltaje a 5V. Esta alimentación es compartida con los sensores y la pantalla I2C mediante los conectores Molex.</p>

### 2. Lectura del Sensor de Radiación Solar (SUF268J001)
<p align="justify">El sensor de radiación solar se alimenta a través del pin 5V del Arduino Nano. La señal de radiación solar se transmite desde el sensor hacia el pin A0 del Arduino Nano. Esta señal analógica es convertida en un valor digital por el microcontrolador para su procesamiento.</p>

### 3. Medición de Velocidad del Viento (Anemómetro Casero)
<p align="justify">El anemómetro casero, basado en el motor RF-500TB-14415, envía pulsos analógicos al pin A1 del Arduino Nano. Estos pulsos, generados por las revoluciones del motor, son interpretados por el Arduino Nano y convertidos en datos de velocidad de viento a través de cálculos predefinidos.</p>

### 4. Visualización en Pantalla I2C
<p align="justify">La pantalla I2C recibe los valores procesados de la radiación solar y la velocidad del viento mediante la comunicación I2C, utilizando los pines A4 (SDA) y A5 (SCL) del Arduino Nano. Los datos se muestran en tiempo real en la pantalla, permitiendo una lectura continua de los parámetros monitoreados.</p>

### 5. Conexión Modular a través de Molex
<p align="justify">Todos los sensores y la pantalla están conectados mediante conectores Molex. Esto permite una desconexión rápida y sencilla de los componentes, facilitando el mantenimiento y el reemplazo sin afectar el funcionamiento del sistema.</p>

## Consideraciones de Diseño

### 1. Modularidad
<p align="justify">Se utilizaron conectores Molex para permitir una fácil conexión y desconexión de los sensores y la pantalla.</p>

### 2. Eficiencia Energética
<p align="justify">Se seleccionaron componentes de bajo consumo para maximizar la duración de la batería portátil.</p>

### 3. Diseño Compacto
<p align="justify">El diseño del PCB fue optimizado para ser compacto y portátil, asegurando que sea fácil de transportar y utilizar en campo.</p>

## Conclusión

<p align="justify">Este sistema portátil no solo es una solución práctica para la medición precisa de la velocidad del viento y la radiación solar, sino que también ofrece un enfoque eficiente y modular para evaluar la viabilidad de proyectos de energía renovable. Al ser fácil de transportar y configurar, es ideal para estudios en campo que requieran una rápida instalación y operación. Esto lo convierte en una herramienta esencial para ingenieros y profesionales que buscan optimizar la toma de decisiones sobre la instalación de aerogeneradores y paneles solares en distintas zonas

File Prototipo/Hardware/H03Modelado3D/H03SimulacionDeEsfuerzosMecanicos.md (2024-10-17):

<p align="left">
  
  <h1 align="center">Entregable 06: Simulación de Esfuerzos Mecánicos (Estáticos)</h1>
</p>

## Introducción

<p align="justify">El diseño de piezas en 3D es un área muy importante dentro de los proyectos de ingeniería, especialmente cuando se trata de la protección de componentes electrónicos, el proceso de diseño implica la incorporación de elementos claves como las nervaduras, chaflanes y redondeos, que mejoran la resistencia y reducen las tensiones concentradas en puntos críticos de las piezas. Las nervaduras son elementos extrusionados que agregan material de refuerzo en zonas específicas, aumentando la rigidez estructural sin incrementar el peso de la pieza. Por otro lado, el uso de chaflanes y redondeos ayuda a reducir el esfuerzo en las uniones y mejorar la durabilidad de las piezas impresas en 3D [1].</p>

<p align="justify">La simulación por elementos finitos mediante el software SIMSCALE es una herramienta esencial en el proceso de diseño, ya que permite predecir y analizar efectos de diversos tipos de esfuerzos, como atracción, compresión, flexión, torsión y cortante, sobre las piezas diseñadas. Esta técnica es especialmente útil para identificar posibles fallas en materiales frágiles, como fracturas por esfuerzos superiores a su resistencia máxima o fallas por fatiga debido a cargas fluctuantes [2].</p>

<p align="justify">Además, debemos considerar los factores externos, como la temperatura, estas pueden influir en la deformación y el desempeño estructural de las carcasas, existen algunas aplicaciones donde las carcasas protegen placas electrónicas cercanas a motores, es por eso qué es fundamental evaluar su resistencia térmica mediante simulaciones que modelen la deformación bajo diferentes condiciones de operación [3].</p>

<p align="justify">En el presente informe se diseñó una simulación de esfuerzos mecánicos de uno de los componentes de nuestro proyecto, se ha tenido en cuenta la correcta selección del material y la orientación de la impresión, ya que juegan un papel importante en la optimización del rendimiento de las piezas impresas en 3D.</p>

## Metodología

<p align="justify">El análisis de esfuerzos estáticos permite estudiar cómo los materiales responden a cargas que se aplican de manera lenta y continua hasta alcanzar un equilibrio. Este enfoque asume que no hay aceleraciones ni efectos dinámicos, lo que facilita el estudio de la distribución de fuerzas y deformaciones en un entorno estable y predecible. Este análisis se basa en la mecánica de sólidos, evaluando cómo las fuerzas externas generan esfuerzos internos y deformaciones. </p>

<p align="justify">El material principal utilizado es el PLA (ácido poliláctico), un polímero biodegradable obtenido a partir de recursos renovables como el almidón de maíz, la caña de azúcar o la tapioca. Este material se presenta como una alternativa sostenible a los plásticos convencionales derivados del petróleo. Gracias a su rigidez, facilidad de manejo y sostenibilidad, el PLA es adecuado para la simulación de esfuerzos estáticos. No obstante, su fragilidad lo limita en aplicaciones que requieren alta resistencia mecánica o a impactos. A pesar de ello, resulta útil para evaluar el comportamiento de los componentes bajo cargas estáticas, permitiendo comprender mejor sus límites y capacidades [4].</p>

<p align="justify">La simulación mediante la técnica FEM descompone modelos complejos en pequeñas secciones, lo cual calcula los esfuerzos y deformaciones. SimScale permite realizar estos cálculos de manera eficiente, proporcionando representaciones visuales que muestran las concentraciones de esfuerzos y deformaciones en la estructura analizada. Esto ayuda a identificar las zonas donde la estructura puede experimentar mayores tensiones bajo la carga aplicada [2].</p>

### Paso 1: Creación del proyecto en Onshape

<p align="justify">Iniciamos el proceso creando un nuevo proyecto en Onshape, una plataforma de modelado 3D basada en la nube. El objetivo del proyecto era diseñar los cases para el Arduino Nano y el sensor SUF268J001, asegurándonos de que encajaran perfectamente y cumplieran con las especificaciones físicas de los componentes.</p>

<p align="center">
  
  
</p>

### Paso 2: Importación de modelos 3D

<p align="justify">Para garantizar que los cases se ajustaran adecuadamente, comenzamos importando los modelos 3D del Arduino Nano y del sensor SUF268J001, disponibles en línea. Esto nos proporcionó las dimensiones exactas de los dispositivos, lo que nos permitió diseñar los cases con un nivel de precisión óptimo.</p>

<p align="center">
  
  
</p>

### Paso 3: Modelado de los cases

<p align="justify">Comenzamos el modelado creando perfiles en 2D usando la herramienta **Sketch**. Estos perfiles representaban la forma básica de los cases para el Arduino Nano y el sensor, basándonos en las dimensiones importadas previamente.</p>

<p align="justify">Posteriormente, utilizamos la herramienta **Extrude** para transformar estos perfiles en sólidos 3D, especificando el grosor de las paredes y el tamaño de cada elemento. En este paso, agregamos detalles como los agujeros para tornillos, ranuras para conectores y soportes internos que aseguran un ajuste preciso.</p>

<p align="justify">Para reducir el peso y la cantidad de material utilizado en la impresión 3D, aplicamos la herramienta **Shell** a los modelos, vaciando su interior y manteniendo solo las paredes con el grosor necesario para garantizar su resistencia estructural. Este paso fue fundamental para optimizar el diseño sin comprometer la funcionalidad de los cases.</p>

<p align="justify">Una vez modeladas las piezas, realizamos pruebas de ensamblaje virtual en Onshape para asegurarnos de que cada componente encajara correctamente con el Arduino Nano y el sensor. De esta forma, garantizamos que los cases pudieran alojar los dispositivos de manera precisa y segura.</p>

### Case para Arduino Nano
<p align="center">
  
  
  
  
</p>

### Case para sensor SUF268J001
<p align="center">
  
  
  
</p>

### Paso 4: Exportación del modelo

<p align="justify">Con el modelado completo, el siguiente paso fue exportar los diseños en formato **STL** desde Onshape, lo que nos permitió utilizarlos en la plataforma SimScale para llevar a cabo simulaciones de esfuerzo y deformación. Esta exportación se realizó asegurando que todos los detalles del diseño estuvieran correctamente definidos, lo cual es esencial para obtener resultados precisos en las simulaciones.</p>

<p align="center">
  
  
</p>

### Paso 5: Importación del modelo en SimScale

<p align="justify">Ingresamos a SimScale, una plataforma de simulación en línea, y creamos un nuevo proyecto. Una vez en la plataforma, importamos los modelos 3D en formato **STL** que previamente habíamos exportado desde Onshape. Este proceso nos permitió cargar los diseños y preparar las condiciones necesarias para las simulaciones de esfuerzo.</p>

<p align="center">
  
  
</p>

### Paso 6: Configuración de soportes fijos

<p align="justify">Para asegurar que algunas partes del case permanecieran inmóviles durante la simulación, añadimos restricciones usando la opción **Fixed Support**. Seleccionamos las caras donde los cases estarían anclados en su uso práctico, fijándolas para simular un entorno realista y evaluar cómo reaccionarían otras áreas del diseño ante las fuerzas aplicadas.</p>

<p align="center">
  
  
</p>

### Paso 7: Configuración de las condiciones de contorno

<p align="justify">El siguiente paso fue configurar las condiciones de contorno para las simulaciones. Definimos los parámetros de las fuerzas aplicadas sobre los modelos, asignando fuerzas en las direcciones X, Y e Z sobre las caras seleccionadas, simulando las condiciones de carga que los cases enfrentarían en el uso real.</p>

<p align="justify">Para esto, utilizamos la opción **Force** dentro de SimScale y seleccionamos las superficies correspondientes de los modelos donde se aplicarían las fuerzas. Establecimos los valores de las fuerzas para evaluar cómo se comportarían los cases bajo presión en situaciones reales.</p>

<p align="center">
  
  
</p>

### Paso 8: Lanzamiento de las simulaciones

<p align="justify">Con las fuerzas y las restricciones aplicadas, procedimos a lanzar las simulaciones. Este proceso nos permitió calcular cómo las fuerzas aplicadas afectarían las distintas áreas del case, generando mapas de tensiones y deformaciones.</p>

<p align="center">
  
  
  
</p>

## Resultados

<p align="justify">Luego del realizado del modelado en 3D de los cases para alojar el arduino nano y el sensor fotoeléctrico, asegurándonos que las dimensiones y la estructura del diseño permiten la correcta fijación gracias a los agujeros de soporte para tornillos, exportamos e integramos a SimScale los modelos gracias a la plataforma Onshape, preparados para llevar a cabo las simulaciones de esfuerzos estáticos, usando como material principal PLA, según fue establecido en este documento.</p>

<p align="center">
  
  
  
  
</p>

<p align="justify">Analizamos los mapas de tensiones y deformaciones generadas por la fuerza aplicada en una de las caras del sistema, con esto logramos identificar las zonas críticas del diseño. Los mapas de color obtenidos destacan las concentraciones de fuerzas, que evaluamos para determinar si el case era capaz de soportar las condiciones que se presenten en la ubicación que elegimos para instalar el maletín. Simulamos una carga de viento representativa con velocidades de hasta 90 km/h.</p>

<p align="center">
  
  
  
  
</p>

<p align="justify">Las deformaciones fueron menores a 0.5 mm, confirmando que el modelo actual del caso no requiere modificaciones adicionales en términos de resistencia mecánica, listo para su implementación en el proyecto, siempre que las condiciones de operación no superen las especificadas en esta simulación.</p>

## Referencias Bibliograficas

1.- Tipán-Suárez, A. M., Beltran-Chamba, C. M., Jima-Matailo, J. C., & Vinueza-Sánchez, R. D. (2020). Diseño Mecatrónico para la fabricación de una impresora 3D. Dominio de las Ciencias, 6(3), 694-714.

2.- Suárez, M. H., Coronel, C. E. I., Cueto, O. G., Bravo, E. L., & Iznaga, Á. S. (2008). Simulación mediante el Método de Elementos Finitos de la respuesta mecánica de un Oxisol. Revista Ciencias Técnicas Agropecuarias, 17(2), 55-61.

3.- Gutiérrez Quintero, W. (2014). Resistencia al desgaste abrasivo de recubrimientos producidos por proyección térmica para aplicaciones navales (Doctoral dissertation).

4.- Ferri Azor, J. M., Carbonell Verdú, A., Montañés Muñoz, N., Jorda-Vilaplana, A., & Fenollar Gimeno, O. Á. (2014). Optimización de las propiedades mecánicas del compuesto PLA/PCL para su aplicación como material biocompatible.

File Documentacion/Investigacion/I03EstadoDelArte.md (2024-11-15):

<p align="left">
  
  <h1 align="center">Estado Del Arte</h1>
</p>

## Contexto científico
### Artículo 1
### Desarrollo de un sistema de adquisición de datos de campo para variables ambientales y de un sensor de viento, ambos de bajo costo y de arquitectura abierta

| <center>Descripción del artículo</center> | <center>Ilustración</center> |
| --- | --- |
| <p align="justify">Este proyecto se enfoca en el comienzo de la aplicación de una estructura abierta dirigida a la recopilación de datos ambientales. También establece las bases para investigar el uso potencial de sensores piezoeléctricos para medir la velocidad del viento en al menos una dirección. La investigación se divide en dos bloques principales, destacando la importancia de la interoperabilidad. Se evidencia que la implementación completa de este sistema puede lograrse a un costo considerablemente inferior en comparación con los sistemas convencionales empleados para medir la velocidad del viento, abriendo así nuevas perspectivas de investigación. El diseño propuesto es económico, presenta una capacidad de memoria destacada y capitaliza los avances en tecnología de memorias con conexión USB.<br><br>Se realizaron pruebas para evaluar la velocidad del viento mediante un mecanismo específico. Se ajustaron las velocidades del viento utilizando una secadora de pelo de 2 velocidades, ubicada a diversas distancias del sensor (50 cm, 75 cm, 110 cm y 150 cm). Se desactivó la función de calentamiento de la secadora para asegurar un flujo uniforme, a diferencia de los abanicos de computadora. Para obtener mediciones estándar de velocidad del viento, se empleó un anemómetro de cazoletas Thies Clima como punto de referencia. La digitalización de los datos se realizó mediante el datalogger CEC webDAQ/100. La información recopilada del medidor de velocidad del viento con cazoletas fue analizada mediante C#, el cual transformó la frecuencia a velocidades en m/s y km/h. (Quesada-Kimsey et al., 2009).</p>|  |

### Artículo 2
### Smart Grid y la energía solar fotovoltaica para la generación distribuida

| <center>Descripción del artículo</center> | <center>Ilustración</center> |
| --- | --- |
| <p align="justify">La Red Inteligente (Smart Grid) se perfila como la siguiente fase crucial en la evolución de la red eléctrica tradicional, focalizándose en la integración de fuentes de energía renovable, especialmente a través de tecnologías fotovoltaicas. Con la creciente demanda global de energía, se busca el desarrollo de técnicas para aprovechar energías renovables de manera accesible, condicionado por políticas estatales y reducciones en costos tecnológicos. Mejorar la eficiencia de la energía solar mediante estudios técnicos de conversores de paneles solares y sistemas automatizados para gestionar la carga y descarga de baterías se presenta como un enfoque clave.<br><br>En el panorama actual, donde más del 80 % de la energía proviene de combustibles fósiles, contribuyendo a la contaminación y al calentamiento global, las fuentes de energía renovable representan el 15-20 % de la demanda. Estas se posicionan como soluciones efectivas para abordar el cambio climático. Tecnologías fotovoltaicas a pequeña escala se consideran costo-efectivas, evidenciado en casos como Australia, donde ofrecen electricidad en áreas remotas. La transición hacia una red eléctrica moderna, impulsada por fuentes renovables, se vislumbra como esencial para afrontar la crisis energética y ambiental a nivel mundial (Berrío & Zuluaga, 2014).</p>|  |

### Artículo 3
### A Neural Network Based Intelligent Predictive Sensor for Cloudiness, Solar Radiation and Air Temperature (Un sensor predictivo inteligente basado en una red neuronal para la nubosidad, la radiación solar y la temperatura del aire)

| <center>Descripción del artículo</center> | <center>Ilustración</center> |
| --- | --- |
| <p align="justify">Este artículo presenta un sensor predictivo inteligente que utiliza redes neuronales avanzadas para medir y prever nubosidad, radiación solar y temperatura del aire, representando un hito en la monitorización climática. Empleando redes neuronales de última generación, el sensor analiza datos históricos y adapta su aprendizaje en tiempo real, permitiendo predicciones precisas en entornos dinámicos. Su capacidad para realizar predicciones multivariables, anticipando cambios simultáneos en varias variables climáticas, mejora significativamente la precisión global en comparación con sensores convencionales. La asombrosa optimización de la eficiencia operativa en entornos solares se logra anticipando cambios en la radiación solar, permitiendo ajustes precisos en la generación y almacenamiento de energía para maximizar el rendimiento.<br><br>La adaptabilidad a condiciones locales, respaldada por el entrenamiento con datos específicos de ubicación, garantiza pronósticos más precisos y relevantes para cada entorno. La interfaz de usuario intuitiva no solo simplifica la configuración y visualización de datos, sino que también democratiza el acceso al sensor, haciendo que profesionales de diversas disciplinas aprovechen sus beneficios, más allá de los expertos en inteligencia artificial. Además, la integración eficiente en sistemas de Internet de las Cosas (IoT) amplía su utilidad, facilitando la monitorización remota y la transmisión de datos en tiempo real, esencial para aplicaciones a gran escala y entornos distribuidos. La validación empírica respalda la eficacia del sensor, demostrando su precisión y fiabilidad mediante rigurosas pruebas en diversas condiciones climáticas (Ferreira et al., 2012).</p>|  |

## Contexto Comercial
## Productos

| <center>Producto 1: Medidor de radiación solar Fluke IRR1-SOL</center> |
| ------------ |
| <p align="justify">**Creador:** Fluke corporation</p><p align="justify">El Fluke IRR1-SOL es un medidor de radiación, ha sido desarrollado con el propósito de simplificar el proceso de instalación, puesta en marcha y mantenimiento de sistemas fotovoltaicos a través de un único dispositivo fácil de manejar. Este instrumento portátil posibilita la medición de radiación solar, temperatura, inclinación y dirección de los paneles, cumpliendo con los estándares de la normativa IEC 62446-1. Gracias a su diseño compacto y robusto, acompañado de una pantalla LCD de alto contraste, su utilización se facilita en diversos entornos. Equipado con funciones como brújula integrada y sensor de inclinación, el IRR1-SOL permite medir y documentar de manera eficiente la orientación del techo, la instalación, así como el ángulo e inclinación de los paneles. Asimismo, puede emplearse para el diseño, supervisión y comparación del rendimiento de sistemas fotovoltaicos, asegurando que estos generen la potencia eléctrica prevista en relación con la radiación solar recibida.<br><br>Extraído de:<br><br>https://www.fluke.com/es-pe/producto/comprobacion-electrica/herramientas-de-energia-solar/flk-irr1-sol#<br><br>https://dam-assets.fluke.com/s3fs-public/flk-220224-200400-es-naam-RR1-Soi-irradiance-meter-ds-w_0.pdf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</p>|

| <center>Producto 2: Anemómetro digital portátil con sensor de temperatura AN200 EXTECH</center> |
| ------------ |
| <p align="justify">**Creador:** EXCTECH instruments</p></p><p align="justify">El AN200 de EXTECH destaca como un minitermoanemómetro excepcional con un enfoque especial en la medición del viento. Este dispositivo versátil no solo cuenta con un termómetro infrarrojo para medir la temperatura de superficies remotas hasta 500 °F (260 °C) con puntero láser, sino que también tiene la capacidad de mostrar simultáneamente el flujo de aire o la velocidad del viento junto con la temperatura ambiente. Sus características avanzadas incluyen la memorización de dimensiones de área configurables (ft² o m²) para mayor comodidad. Con una rueda de paleta de baja fricción y una precisión de velocidad del 3%, el AN200 proporciona mediciones precisas y fiables del viento. Viene completo con una batería de 9 voltios, funda protectora de goma y estuche, siendo una herramienta integral y práctica para profesionales que buscan un medidor de viento de alto rendimiento.<br><br>Extraído de:<br><br>https://www.viaindustrial.com/manuales_pdf/anemometro-digital-portatil-con-sensor-de-temperatura-an200-extech-manual-espanol.pdf</p>|

| <center>Producto 3: Medidor de energía solar SP505</center> |
| ------------ |
| <p align="justify">**Creador:** EXCTECH instruments</p></p><p align="justify">El Extech SP505 se destaca como un dispositivo esencial para medir la potencia de la radiación solar y facilitar la determinación de la ubicación ideal para instalaciones solares. Su versatilidad abarca la evaluación de la eficacia de la película solar, la medición precisa de la radiación solar y la comprobación de ventanas con aislamiento solar. En la industria automotriz, este medidor de bolsillo también se emplea para verificar la intensidad de los faros. Su utilidad se extiende incluso a la industria de ventanas, donde los fabricantes y propietarios de viviendas en remodelación confían en él para evaluar la transmisión de radiación solar a través de diferentes espesores de vidrio y niveles de tinte. Además, el SP505 ayuda a encontrar el ángulo óptimo de incidencia para maximizar la eficiencia de paneles solares y calentadores de agua solares. El producto se entrega completamente probado y calibrado.<br><br>Extraído de:<br><br>https://www.finaltest.com.mx/v/vspfiles/assets/datasheet/SP505_UM.pdf<br><br>https://www.comerciogc.com/intranet/assets/images/archivos/43-ficha-tecnica.pdf</p>|

## Patentes de Invención
| <center>Patente 1</center> |
| ------------ |
| <p align="justify">**ES2473640T3** - Dispositivo y método de seguimiento solar para concentración fotovoltaica de alta eficacia<br>**Fecha de Publicación:** 07/07/2014<br>**Número de Publicación:** 2473640<br>**Inventor(es):** Hong Seokhoon, Kang Mun-Sig y Jang Byung-Seok<br></p></p><p align="justify">Este dispositivo innovador es esencialmente un panel solar inteligente que sigue la trayectoria del sol para maximizar la captación de energía solar. Imagina un panel solar especial con la capacidad de enfocar la luz solar en un punto específico utilizando una lente de Fresnel. Este panel cuenta con un "ojo" especial, un sensor de seguimiento solar, que detecta y sigue el punto focal de la luz concentrada. Además, para una eficiencia óptima, el sistema incorpora detectores de luz solar en diferentes lados del panel. Dos unidades de control ajustan la posición del panel: una basada en la luminosidad general medida por los detectores solares y la otra utilizando información detallada del punto focal de la luz concentrada. Para evitar pérdidas de luz solar valiosa, se emplean lentes estratégicamente colocadas. En resumen, este dispositivo asegura que los paneles solares estén constantemente orientados hacia el sol de la manera más eficiente posible, permitiendo una generación de energía solar óptima.<br><br>Extraído de:<br><br>https://patents.google.com/patent/ES2473640T3/es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</p>|

| <center>Patente 2</center> |
| ------------ |
| <p align="justify">**WO2008145796** - Sensor de Radiación Solar<br>**Fecha de Publicación:** 04/12/2008<br>**Número de Publicación:** WO/2008/145796<br>**Inventor(es):** Cruz Peragon Fernando, Casanova Pelaez Pedro, Diaz Garrido Francisco y Palomar Carnicero José</p></p><p align="justify">Esta patente posibilita la medición constante de la radiación incidente global en cada unidad diferencial de la superficie de una semiesfera. Emplea una estructura sencilla y compacta, prescindiendo de elementos electromecánicos para realizar estas mediciones. La superficie semiesférica aloja células o sensores de radiación solar, cada uno con ángulos acimutales terrestres e inclinaciones únicos. Cada célula está emparejada a un sensor de temperatura, cuya función es corregir las variaciones térmicas en las señales medidas. Las señales de ambas unidades se amplifican y se conectan a un sistema de adquisición, evaluación y gestión de datos, como un ordenador, posibilitando así el control del sistema solar vinculado al dispositivo.<br><br>Extraído de:<br><br>https://patentscope.wipo.int/search/en/detail.jsf?docId=WO2008145796&_cid=P11-LRK4L0-55712-1</p>|

| <center>Patente 3</center> |
| ------------ |
| <p align="justify">**ES2431829T3** - Sistema sensor eólico que utiliza señales de aspas<br>**Fecha de Publicación:** 28/11/2013<br>**Número de Publicación:** 2431829<br>**Inventor(es):** Fabio Bertolotti y Jens Carpintero</p></p><p align="justify">Sistema que utiliza al menos un sensor en una de las aspas de la turbina para medir una cantidad física que refleja una característica del campo de velocidad del viento. Esta información se procesa a través de una tabla que se ha construido previamente, asociando los valores de los componentes cíclicos y constantes de la señal del sensor con los valores correspondientes de la velocidad del viento bajo diversas condiciones. La tabla resultante se utiliza como referencia para determinar, mediante unos medios de búsqueda, el valor de la característica del campo de velocidad del viento en tiempo real, considerando la condición actual del viento. En resumen, el sistema aprovecha la información recopilada previamente para estimar la velocidad del viento actual y, por ende, optimizar el rendimiento de la turbina eólica.<br><br>Extraído de:<br><br>https://patents.google.com/patent/ES2431829T3/es?q=(sensor+eolico)&oq=sensor+eolico&page=4</p>|

| <center>Patente 4</center> |
| ------------ |
| <p align="justify">**ES2553980T3** - Un sensor óptico de viento de turbina eólica<br>**Fecha de Publicación:** 15/12/2015<br>**Número de Publicación:** 2553980<br>**Inventor:** Olessen y IB Svend</p></p><p align="justify">Se trata de un sensor óptico instalado en el rotor de una turbina eólica, compuesto por varias fuentes de luz colocadas angularmente en el rotor. Estas fuentes emiten haces de luz que atraviesan las palas del rotor con ángulos específicos. Dispositivos receptores de luz, también montados en el rotor, detectan destellos de luz provocados por partículas en el viento. Un controlador procesa estos destellos para calcular tiempos de tránsito de las partículas a través de los haces de luz, proporcionando así información sobre la velocidad y dirección del viento tanto en la dirección axial como en el plano de rotación del rotor. En resumen, el sensor utiliza la interacción de la luz con partículas en el viento para medir la velocidad y dirección del viento en diferentes direcciones.<br><br>Extraído de:<br><br>https://patents.google.com/patent/ES2553980T3/es?q=(sensor+eolico)&oq=sensor+eolico&page=6</p>|

## Lista de requerimientos
### Funcionales
<p align="center">
  
</p>

### No funcionales
<p align="center">
  
</p>

### Estrategia de solución
<p align="center">
  
</p>

### Información Adicional 
#### Velocidad del viento

<p align="justify">
La energía eólica aprovecha la fuerza del viento para producir electricidad, mientras que los paneles solares convierten la luz solar en electricidad. Por lo tanto, la velocidad del viento se mide en kilómetros por  hora (km/h), metros por segundo (m/s) o nudos, y se estudia con un anemómetro. Asimismo, para que un aerogenerador funcione, se necesita una velocidad mínima de viento de 3-4 m/s, pero para plantear un proyecto eólico, la velocidad media anual del viento debe ser al menos de 5 m/s, (ENERLIFE, 2020).
</p>

#### Radiación solar

<p align="justify">
En la presente era, la electricidad desempeña un papel esencial en el respaldo de los progresos alcanzados por nuestra sociedad. Por consiguiente, al integrar sistemas de energía fotovoltaica en las instituciones educativas, se obtienen múltiples beneficios derivados de la energía solar. Esta fuente renovable, al ser respetuosa con el medio ambiente, proporciona un suministro constante y adaptable a diversas demandas de energía eléctrica (Solpro, 2021).
</p>

<p align="justify">
Por lo general, la instalación de paneles solares en las escuelas requiere una instalación fotovoltaica de menos de 1000 W/m², según el Real Decreto RD 244/2019. Además,  la medición se realiza con ayuda de un sensor de radiación o piranómetro ubicado hacia el sur y en un área sin sombras. La unidad de medida es vatios por metro cuadrado (W/m²), (Real decreto, 2019).
</p>

### Tiempo de estudio
#### Análisis prolongado del tiempo de estudio para determinar la eficiencia de energía renovable con el dispositivo
<p align="justify">
La realización de un estudio relámpago sobre las características de la energía renovable en el Colegio San José se enfrenta a un desafío temporal crítico, con un margen de desarrollo del proyecto limitado a tres días. Con el objetivo de realizar una evaluación instantánea, proponemos la implementación de un dispositivo de monitoreo de vanguardia, como un sistema de sensores IoT con capacidad de recopilación de datos en tiempo real. Este enfoque permitirá adquirir información detallada sobre la radiación solar, la velocidad del viento y otros parámetros pertinentes en un lapso tan breve.
</p>

<p align="justify">
Dada la urgencia del estudio, la determinación de la fuente de energía renovable más eficiente se centrará en métricas clave de rendimiento, como la densidad de potencia y la capacidad de generación inmediata. Además, se sugiere incluir en el análisis el artículo "Sistema De Monitoreo de Variables Medioambientales Usando Una Red de Sensores Inalámbricos y Plataformas De Internet De Las Cosas", (Quiñones-Cuenca et al., 2017). Este artículo presenta una perspectiva sobre la aplicación de sistemas de monitoreo inalámbricos e IoT para evaluar variables medioambientales, lo cual podría complementar y enriquecer el análisis del estudio en el Colegio San José.
</p>

---
## Bibliografía
Berrío, L. H., & Zuluaga, C.  (2014). Smart Grid y la energía solar fotovoltaica para la generación distribuida: unarevisión en el contexto energético mundial. Ingeniería y Desarrollo, 32(2), 369-396.<br>https://www.redalyc.org/articulo.oa?id=85232596010

Bertolotti, F., et al (2013). ES2431829T3 - Sistema sensor eólico que utiliza señales de aspas - Google Patents.<br>https://patents.google.com/patent/ES2431829T3/es?q=(sensor+eolico)&oq=sensor+eolico&page=4

BOE-A-2019-5089 Real Decreto 244/2019, de 5 de abril, por el que se regulan las condiciones administrativas, técnicas y económicas del autoconsumo de energía eléctrica. (n.d.).<br>https://www.boe.es/buscar/doc.php?id=BOE-A-2019-5089

ENERLIFE, (2020). Velocidad del viento mínima para una instalación eólica en 3 pasos.<br>https://enerlife.cl/velocidad-del-viento-minima-para-una-instalacion-eolica-en-3-pasos/

Ferreira, P. M., Gomes, J. M., Martins, I. A. C., & Ruano, A. E. (2012). A neural network based intelligent predictive sensor for cloudiness, solar radiation and air temperature. Sensors (Switzerland), 12(11), 15750-15777. Scopus.<br>https://www.scopus.com/record/display.uri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

Hong, S. et al., (2014) . ES2473640T3 - Dispositivo y método de seguimiento solar para concentración fotovoltaica de alta eficacia - Google Patents.<br>https://patents.google.com/patent/ES2473640T3/es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

Olesen, I. S. (2015). ES2553980T3 - Un sensor óptico de viento de turbina eólica - Google Patents.<br>https://patents.google.com/patent/ES2553980T3/es?q=(sensor+eolico)&oq=sensor+eolico&page=6

Quesada-Kimsey, J. et al  (2009). Desarrollo de un sistema de adquisición de datos de campo para variables ambientales y de un sensor de viento, ambos de bajo costo y de arquitectura abierta.<br>https://repositoriotec.tec.ac.cr/handle/2238/5776

Solpro. (2021). ¿Qué ventajas tiene instalar placas solares en los colegios? SOLPRO ENERGIA SOLAR.<br>https://solproenergiasolar.com/ventajas-de-instalar-placas-solares-en-los-colegios/

Stavrou, P., et al (2012). ES2389794B2 - Sistema y método de seguimiento de la radiación solar. - Google Patents.<br>https://patents.google.com/patent/ES2389794B2/es?q=(sensor+de+radiacion+solar)&oq=sensor+de+radiacion+solar

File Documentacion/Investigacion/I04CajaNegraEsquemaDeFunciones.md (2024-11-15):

<p align="left">
  
  <h1 align="center">Caja Negra y Esquema de Funciones</h1>
</p>

## Caja Negra

<p align="center">
  
</p>

## Definición de Entradas y Salidas

<p align="center">
  
</p>

## Esquema de Funciones

<p align="center">
  
</p>

## Definición de Funciones

<p align="center">
  
</p>

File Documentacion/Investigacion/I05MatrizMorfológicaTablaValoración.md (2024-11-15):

<p align="left">
  
  <h1 align="center">Matriz Morfológica y Evaluación de Conceptos de Solución</h1>
</p>

## Matriz Morfológica

<p align="center">
  
</p>

## Evaluación de Conceptos de Solución
## Tabla de Valoración

<p align="center">
  
</p>

## Conclusión

<p align="justify">
La matriz morfológica y la tabla de valoración nos han permitido identificar tres conjuntos de soluciones potenciales para nuestro desafío. Tras un exhaustivo análisis, el CS1 se destacó como la opción más idónea debido a su alta accesibilidad, rentabilidad y viabilidad para la realización exitosa de nuestro prototipo. Esta elección estratégica nos garantiza una sólida base para avanzar con confianza en nuestro proyecto, asegurando que estamos tomando decisiones fundamentadas y efectivas. 
</p>

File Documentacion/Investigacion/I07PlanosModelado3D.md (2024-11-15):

<p align="left">
  
  <h1 align="center">Planos del Modelado 3D</h1>
</p>

<a href="https://github.com/Paradoxeado/prototypeProject/tree/main/Prototipado/Hardware" style="background: linear-gradient(45deg, #FFD700, #FF69B4, #1E90FF); color: black; padding: 10px 20px; text-align: center; text-decoration: none; display: inline-block; font-size: 14px; margin: 10px; cursor: pointer; border-radius: 50px; border: none; box-shadow: 0 6px 12px rgba(0, 0, 0, 0.1); transition: transform 0.2s, box-shadow 0.2s;" onmouseover="this.style.transform='scale(1.1)'" onmouseout="this.style.transform='scale(1)'">Carpeta de Componentes 3D y Planos</a>
</p>

## Plano: Maleta

<p align="center">
  
</p>

## Plano: Tapa para la Batería Portátil

<p align="center">
  
</p>

## Plano: Tapa de la Caja del Anemómetro

<p align="center">
  
</p>

## Plano: Anemómetro

<p align="center">
  
</p>

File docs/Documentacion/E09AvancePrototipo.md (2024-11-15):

<p align="left">
  
  <h1 align="center">Avance del Prototipo: Diagrama de Flujo, Circuito Esquemático y Elaboración de Código</h1>
</p>

## Acerca de nuestro Prototipo - Modelado 3D

<p align="center">
  
  
</p>



## Esquemático Electrónico

<p align="center">
  
</p>
<p align="center">
  
</p>
<a href="https://github.com/Paradoxeado/prototypeProject/blob/main/Prototipado/Hardware/EsquematicoElectronico.pdf" style="background: linear-gradient(45deg, #FFD700, #FF69B4, #1E90FF); color: black; padding: 10px 20px; text-align: center; text-decoration: none; display: inline-block; font-size: 14px; margin: 10px; cursor: pointer; border-radius: 50px; border: none; box-shadow: 0 6px 12px rgba(0, 0, 0, 0.1); transition: transform 0.2s, box-shadow 0.2s;" onmouseover="this.style.transform='scale(1.1)'" onmouseout="this.style.transform='scale(1)'">Enlace al Esquemático Electrónico en formato PDF</a>
</p>
<p align="center">
  
</p>





## Diagrama de Flujo

<a href="https://github.com/Paradoxeado/prototypeProject/blob/main/Prototipado/Software/DiagramaDeFlujo.pdf" style="background: linear-gradient(45deg, #FFD700, #FF69B4, #1E90FF); color: black; padding: 10px 20px; text-align: center; text-decoration: none; display: inline-block; font-size: 14px; margin: 10px; cursor: pointer; border-radius: 50px; border: none; box-shadow: 0 6px 12px rgba(0, 0, 0, 0.1); transition: transform 0.2s, box-shadow 0.2s;" onmouseover="this.style.transform='scale(1.1)'" onmouseout="this.style.transform='scale(1)'">Enlace al Diagrama de Flujo en formato PDF</a>
</p>

<p align="center">
  
</p>

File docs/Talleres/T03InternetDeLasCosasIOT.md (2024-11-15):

<p align="center" style="margin-top: 50px; margin-bottom: 50px; font-family: Arial, sans-serif;">
  <p align="center">
    Facultad de Ciencias e ingeniería logo
  </p>  
  <h1 align="center" style="margin-top: 30px; margin-bottom: 0px;">Facultad de Ciencias e ingeniería “Alberto Cazorla Talleri”</h1>
</p>

<h2 align="center" style="font-family: Arial, sans-serif;">Taller 03: Internet de las Cosas (IoT)</h2>

<strong> Docentes:</strong>
- Mg Umbert Lewis De La Cruz
- Mg. Paulo Camilo Vela Antón 
- Mg. Moises Stevend Meza Rodriguez 
- Dr. Harry Anderson Rivera Tito 
- Ing. Juan Manuel Zuñiga Mamani  
- Ing. Renzo José Chan Ríos

<strong>Elaborado por:</strong>
- Amparo Marleny Vidaurre Juárez
- Edwin Junior Jara Bocanegra
- Antony Iván Mendoza Villar
- Josue Jhordan Poma Arrieta
- Aracely Nicoll Dueñas Condori
</p>

<hr style="border: 1px solid #ccc; margin-top: 50px; margin-bottom: 50px;">

## 1. Introducción
<p align="justify">
El IoT se refiere  a la interconexión de dispositivos físicos a través de internet, permitiéndoles recopilar y compartir datos. Esta red de dispositivos abarca desde electrodomésticos y vehículos hasta dispositivos médicos y equipos industriales. La IoT tiene el potencial de revolucionar la forma en que interactuamos con el mundo que nos rodea, al proporcionar una mayor eficiencia, comodidad y control. Estos datos pueden ser utilizados para automatizar procesos, tomar decisiones informadas, monitorear el rendimiento de los dispositivos y mejorar la eficiencia operativa en una amplia gama de aplicaciones.
</p>

## 2. Descripción de Internet de las cosas (IoT)

### Características y componentes del  Internet de las cosas  (IoT)
- **Dispositivos Conectados:** Estos son los componentes físicos que forman parte del IoT, como sensores, actuadores, cámaras, medidores, etc.
- **Conectividad:** Los dispositivos IoT se conectan a través de redes inalámbricas, como Wi-Fi, Bluetooth, etc.
- **Plataformas de Gestión de Datos:** Estas plataformas permiten la recopilación, almacenamiento y análisis de grandes volúmenes.
- **Seguridad:** Dado que los dispositivos IoT recopilan y transmiten datos sensibles, la seguridad es fundamental para proteger la integridad y la privacidad de la información.
- **Protocolos de Comunicación:** Estos son los estándares que permiten la comunicación entre los dispositivos IoT y los sistemas de gestión.

### Importancia del  IoT  como herramienta para recopilar y transmitir información.
<p align="justify">
El Internet de las Cosas (IoT) es crucial para recopilar y transmitir información de manera automatizada, permitiendo la toma de decisiones informadas, el monitoreo remoto, la optimización de procesos y la innovación de productos y servicios.
</p>

## 3. Materiales
- Arduino MKR WiFi 1010
- MKR ioT Carrier
- Cable Micro USB
- Pug-and-play cables 
- Batería

<p align="center">
  
</p>

## 4. Ensamblado de componentes
<p align="justify">
Este proyecto prescinde de sensores externos. La operación se logra al montar la placa Arduino MKR WIFI 1010 sobre la MKR IoT Carrier y conectarla a la computadora.
</p>

<div align="center"; style="display: flex; justify-content: space-between;">
  
  
  
</div>

## 5. Ejercicios
### Ejercicio 1: Ejecutar el código de la sección "CONOCE EL KIT"
<p align="justify">
Luego de copiar el código al editor online nos encontramos con el error técnico de conectarlo con nuestra placa. Para lo cual, se decidió usar la app arduino IDE para ejecutar el siguiente código:
</p>

```cpp
#include <Arduino_MKRIoTCarrier.h>
MKRIoTCarrier carrier;
 
float temperature = 0;
float humidity = 0;
 
void setup() {
  Serial.begin(9600);
  //Wait to open the Serial monitor to start the program and see details on errors

  //Set if it has the Enclosure mounted
  CARRIER_CASE = false;
  //Initialize the IoTSK carrier and output any errors in the serial monitor
  carrier.begin();
}
 
void loop() {
  // read the sensor values
  temperature = carrier.Env.readTemperature();
  humidity = carrier.Env.readHumidity();
 
  //Update touch buttons
  carrier.Buttons.update();
 
  // print each of the sensor values
  Serial.print("Temperature = ");
  Serial.print(temperature);
  Serial.println(" Â°C");
 
  Serial.print("Humidity = ");
  Serial.print(humidity);
  Serial.println(" %");
 
  //function to print out values
  if (carrier.Buttons.onTouchDown(TOUCH0)) {
    printTemperature();
  }
 
  if (carrier.Buttons.onTouchDown(TOUCH1)) {
    printHumidity();
  }
}

void printTemperature() {
  //configuring display, setting background color, text size and text color
  carrier.display.fillScreen(ST77XX_RED); //red background
  carrier.display.setTextColor(ST77XX_WHITE); //white text
  carrier.display.setTextSize(6); //large sized text
 
  carrier.display.setCursor(30, 50); //sets position for printing (x and y)
  carrier.display.print("Temp: ");
  carrier.display.setTextSize(4); //decreasing text size
  carrier.display.setCursor(40, 120); //sets new position for printing (x and y)
  carrier.display.print(temperature);
  carrier.display.print(" C");
}
 
void printHumidity() {
  //configuring display, setting background color, text size and text color
  carrier.display.fillScreen(ST77XX_BLUE); //red background
  carrier.display.setTextColor(ST77XX_WHITE); //white text
  carrier.display.setTextSize(2); //medium sized text
 
  carrier.display.setCursor(20, 110); //sets position for printing (x and y)
  carrier.display.print("Humi: ");
  carrier.display.print(humidity);
  carrier.display.println(" %");
}
```

**Explicación de código**
<p align="justify">
- Se ha hecho uso de la librería Arduino MADRId Carrier:
<code> #incluir <Arduino_MKRIoTCarrier.h> </code><br>
- La variable <code>CARRIER_CASE</code> debe estar como <code> TRUE</code>, porque estamos usando la caja de plástico.
<code> CARRIER_CASE = true; </code><br>
- Los botones táctiles <code>printTemperature(); y printHumidity(); </code> nos permite hacer el cambio de pantalla para mostrar los valores de la temperatura y humedad respectivamente.
</p>

```cpp
  if (carrier.Buttons.onTouchDown(TOUCH0)) {
    printTemperature();
  }
 
  if (carrier.Buttons.onTouchDown(TOUCH1)) {
    printHumidity();
  }
```

<p align="justify">
- Para el funcionamiento correcto del anterior segmento de código se hizo lo siguiente dentro de cada función, donde podemos cambiar el color de la pantalla, el tamaño de letra, la ubicación del cursor para el texto y el color de letra:
</p>

```cpp
void printTemperature() {
  //configuring display, setting background color, text size and text color
  carrier.display.fillScreen(ST77XX_RED); //red background
  carrier.display.setTextColor(ST77XX_WHITE); //white text
  carrier.display.setTextSize(6); //large sized text
 
  carrier.display.setCursor(30, 50); //sets position for printing (x and y)
  carrier.display.print("Temp: ");
  carrier.display.setTextSize(4); //decreasing text size
  carrier.display.setCursor(40, 120); //sets new position for printing (x and y)
  carrier.display.print(temperature);
  carrier.display.print(" C");
}
 
void printHumidity() {
  //configuring display, setting background color, text size and text color
  carrier.display.fillScreen(ST77XX_BLUE); //red background
  carrier.display.setTextColor(ST77XX_WHITE); //white text
  carrier.display.setTextSize(2); //medium sized text
 
  carrier.display.setCursor(20, 110); //sets position for printing (x and y)
  carrier.display.print("Humi: ");
  carrier.display.print(humidity);
  carrier.display.println(" %");
}
```

<p align="justify">
El código fue ejecutado con éxito y a continuación se evidencia el correcto funcionamiento de está actividad, donde muestra valores reales de la temperatura y la humedad del laboratorio de prototipado.
</p>

<div align="center"; style="display: flex; justify-content: space-between;">
  
  
  
</div>

### Ejercicio 2: Implementar código para cambiar datos de la temperatura en las escalas convencionales
<p align="justify">
Para lograr este desafío nos ayudamos de las fórmulas físicas revisadas en google, obteniendo lo siguiente:
</p>

```cpp
#include <Arduino_MKRIoTCarrier.h>
MKRIoTCarrier carrier;
 
float temperature = 0;
float humidity = 0;
 
void setup() {
  Serial.begin(9600);
  //Wait to open the Serial monitor to start the program and see details on errors

  //Set if it has the Enclosure mounted
  CARRIER_CASE = true;
  //Initialize the IoTSK carrier and output any errors in the serial monitor
  carrier.begin();
}
 
void loop() {
  // read the sensor values
  temperature = carrier.Env.readTemperature();
  humidity = carrier.Env.readHumidity();
 
  //Update touch buttons
  carrier.Buttons.update();
 
  // print each of the sensor values
  Serial.print("Temperature = ");
  Serial.print(temperature);
  Serial.println(" Â°C");
 
  Serial.print("Humidity = ");
  Serial.print(humidity);
  Serial.println(" %");
 
  //function to print out values
  if (carrier.Buttons.onTouchDown(TOUCH0)) {
    printHumidity();
  }
 
  if (carrier.Buttons.onTouchDown(TOUCH1)) {
    printTemperature();
  }

  if (carrier.Buttons.onTouchDown(TOUCH2)) {
    printTemperatureF();
  }

  if (carrier.Buttons.onTouchDown(TOUCH3)) {
    printTemperatureK();
  }
}

void printTemperature() {
  //configuring display, setting background color, text size and text color
  carrier.display.fillScreen(ST77XX_RED); //red background
  carrier.display.setTextColor(ST77XX_WHITE); //white text
  carrier.display.setTextSize(6); //large sized text
 
  carrier.display.setCursor(30, 50); //sets position for printing (x and y)
  carrier.display.print("Temp: ");
  carrier.display.setTextSize(4); //decreasing text size
  carrier.display.setCursor(40, 120); //sets new position for printing (x and y)
  carrier.display.print(temperature);
  carrier.display.print(" C");
}

void printTemperatureF() {
  //configuring display, setting background color, text size and text color
  float temperatureF = (temperature * 9/5) + 32; // Convertir a Fahrenheit
  carrier.display.fillScreen(ST77XX_RED); //red background
  carrier.display.setTextColor(ST77XX_WHITE); //white text
  carrier.display.setTextSize(6); //large sized text
 
  carrier.display.setCursor(30, 50); //sets position for printing (x and y)
  carrier.display.print("Temp: ");
  carrier.display.setTextSize(4); //decreasing text size
  carrier.display.setCursor(40, 120); //sets new position for printing (x and y)
  carrier.display.print(temperatureF);
  carrier.display.print(" F");
}

void printTemperatureK() {
  //configuring display, setting background color, text size and text color
  float temperatureK = temperature + 273.15; // Convertir a Kelvin
  carrier.display.fillScreen(ST77XX_RED); //red background
  carrier.display.setTextColor(ST77XX_WHITE); //white text
  carrier.display.setTextSize(6); //large sized text
 
  carrier.display.setCursor(30, 50); //sets position for printing (x and y)
  carrier.display.print("Temp: ");
  carrier.display.setTextSize(4); //decreasing text size
  carrier.display.setCursor(40, 120); //sets new position for printing (x and y)
  carrier.display.print(temperatureK);
  carrier.display.print(" K");
}

void printHumidity() {
  //configuring display, setting background color, text size and text color
  carrier.display.fillScreen(ST77XX_BLUE); //red background
  carrier.display.setTextColor(ST77XX_WHITE); //white text
  carrier.display.setTextSize(6); //medium sized text
 
  carrier.display.setCursor(30, 50); //sets position for printing (x and y)
  carrier.display.print("Humi: ");
  carrier.display.setTextSize(4);
  carrier.display.setCursor(40, 120);
  carrier.display.print(humidity);
  carrier.display.println(" %");
}
```

**Explicación de las partes añadidas en el código:**
<p align="justify">
Dentro del <code> void loop() </code>  se llamaron a las funciones creadas para mostrar las diferentes escalas de temperatura. Esto con el fin de realizar la misma secuencia usada anteriormente para actualizar la lectura y ver los diferentes tipos de datos con los botones táctiles del MKR IoT carrier, es decir, se hizo uso de los <code> TOUCH1 TOUCH2  TOUCH3 </code>.
</p>

```cpp
void loop() {
  // read the sensor values
  temperature = carrier.Env.readTemperature();
  humidity = carrier.Env.readHumidity();
 
  //Update touch buttons
  carrier.Buttons.update();
 
  // print each of the sensor values
  Serial.print("Temperature = ");
  Serial.print(temperature);
  Serial.println(" Â°C");
 
  Serial.print("Humidity = ");
  Serial.print(humidity);
  Serial.println(" %");
 
  //function to print out values
  if (carrier.Buttons.onTouchDown(TOUCH0)) {
    printHumidity();
  }
 
  if (carrier.Buttons.onTouchDown(TOUCH1)) {
    printTemperature();
  }

  if (carrier.Buttons.onTouchDown(TOUCH2)) {
    printTemperatureF();
  }

  if (carrier.Buttons.onTouchDown(TOUCH3)) {
    printTemperatureK();
  }
}
```

<p align="justify">
Los códigos usados en las funciones <code> printTemperatureF() y printTemperatureK() </code> se ha reutilizado de la función <code> printTemperature() </code> . Pero con el único cambio en que se imprime la nueva variable asignada a su respectiva conversión de escala.
</p>

```cpp
void printTemperature() {
  //configuring display, setting background color, text size and text color
  carrier.display.fillScreen(ST77XX_RED); //red background
  carrier.display.setTextColor(ST77XX_WHITE); //white text
  carrier.display.setTextSize(6); //large sized text
 
  carrier.display.setCursor(30, 50); //sets position for printing (x and y)
  carrier.display.print("Temp: ");
  carrier.display.setTextSize(4); //decreasing text size
  carrier.display.setCursor(40, 120); //sets new position for printing (x and y)
  carrier.display.print(temperature);
  carrier.display.print(" C");
}

void printTemperatureF() {
  //configuring display, setting background color, text size and text color
  float temperatureF = (temperature * 9/5) + 32; // Convertir a Fahrenheit
  carrier.display.fillScreen(ST77XX_RED); //red background
  carrier.display.setTextColor(ST77XX_WHITE); //white text
  carrier.display.setTextSize(6); //large sized text
 
  carrier.display.setCursor(30, 50); //sets position for printing (x and y)
  carrier.display.print("Temp: ");
  carrier.display.setTextSize(4); //decreasing text size
  carrier.display.setCursor(40, 120); //sets new position for printing (x and y)
  carrier.display.print(temperatureF);
  carrier.display.print(" F");
}

void printTemperatureK() {
  //configuring display, setting background color, text size and text color
  float temperatureK = temperature + 273.15; // Convertir a Kelvin
  carrier.display.fillScreen(ST77XX_RED); //red background
  carrier.display.setTextColor(ST77XX_WHITE); //white text
  carrier.display.setTextSize(6); //large sized text
 
  carrier.display.setCursor(30, 50); //sets position for printing (x and y)
  carrier.display.print("Temp: ");
  carrier.display.setTextSize(4); //decreasing text size
  carrier.display.setCursor(40, 120); //sets new position for printing (x and y)
  carrier.display.print(temperatureK);
  carrier.display.print(" K");
}
```

<div align="center"; style="display: flex; justify-content: space-between;">
  
  
  
</div>

**Ejercicio 3: Implementar código para centrar y aumentar el tamaño de las letras de la Humedad**
<p align="justify">
Para esta parte tan solo modificamos los valores del tamaño del texto en la pantalla y donde debería de estar el curso al mostrar cada texto en su respectiva lectura.
</p>

```cpp
void printHumidity() {
  //configuring display, setting background color, text size and text color
  carrier.display.fillScreen(ST77XX_BLUE); //red background
  carrier.display.setTextColor(ST77XX_WHITE); //white text
  carrier.display.setTextSize(6); //medium sized text
 
  carrier.display.setCursor(30, 50); //sets position for printing (x and y)
  carrier.display.print("Humi: ");
  carrier.display.setTextSize(4);
  carrier.display.setCursor(40, 120);
  carrier.display.print(humidity);
  carrier.display.println(" %");
}
```

<div align="center"; style="display: flex; justify-content: space-between;">
  
  
</div>

### Ejercicio 4: Cambio en el nivel de temperatura (Temperatura del laboratorio = Rojo, Temperatura del aire acondicionado = Azul)
Para lograr este ejercicio implementamos el siguiente código:

```cpp
#include <Arduino_MKRIoTCarrier.h>
MKRIoTCarrier carrier;
 
float temperature = 0;
float humidity = 0;
 
void setup() {
  Serial.begin(9600);
  //Wait to open the Serial monitor to start the program and see details on errors

  //Set if it has the Enclosure mounted
  CARRIER_CASE = true;
  //Initialize the IoTSK carrier and output any errors in the serial monitor
  carrier.begin();
}
 
void loop() {
  // read the sensor values
  temperature = carrier.Env.readTemperature();
  humidity = carrier.Env.readHumidity();
 
  //Update touch buttons
  carrier.Buttons.update();
 
  // print each of the sensor values
  Serial.print("Temperature = ");
  Serial.print(temperature);
  Serial.println(" Â°C");
 
  Serial.print("Humidity = ");
  Serial.print(humidity);
  Serial.println(" %");
 
  //function to print out values
  if (carrier.Buttons.onTouchDown(TOUCH0)) {
    printHumidity();
  }
 
  if (carrier.Buttons.onTouchDown(TOUCH1)) {
    printTemperature();
  }

  if (carrier.Buttons.onTouchDown(TOUCH2)) {
    printTemperatureF();
  }

  if (carrier.Buttons.onTouchDown(TOUCH3)) {
    printTemperatureK();
  }
}

void printTemperature() {
  // Configurar la pantalla, establecer el color de fondo, el tamaño del texto y el color del texto
  if (temperature < 29.45) {
    carrier.display.fillScreen(ST77XX_BLUE); // Fondo azul si la temperatura es menor a 30°C
  } else {
    carrier.display.fillScreen(ST77XX_RED); // Fondo rojo si la temperatura es mayor o igual a 30°C
  }

  carrier.display.setTextColor(ST77XX_WHITE); // Texto blanco
  carrier.display.setTextSize(6); // Texto de tamaño grande

  carrier.display.setCursor(30, 50); // Establecer la posición para imprimir (x y y)
  carrier.display.print("Temp: ");
  carrier.display.setTextSize(4); // Disminuir el tamaño del texto
  carrier.display.setCursor(40, 120); // Establecer nueva posición para imprimir (x y y)
  carrier.display.print(temperature);
  carrier.display.print(" C");
}

void printTemperatureF() {
  //configuring display, setting background color, text size and text color
  float temperatureF = (temperature * 9/5) + 32; // Convertir a Fahrenheit
  carrier.display.fillScreen(ST77XX_RED); //red background
  carrier.display.setTextColor(ST77XX_WHITE); //white text
  carrier.display.setTextSize(6); //large sized text
 
  carrier.display.setCursor(30, 50); //sets position for printing (x and y)
  carrier.display.print("Temp: ");
  carrier.display.setTextSize(4); //decreasing text size
  carrier.display.setCursor(40, 120); //sets new position for printing (x and y)
  carrier.display.print(temperatureF);
  carrier.display.print(" F");
}

void printTemperatureK() {
  //configuring display, setting background color, text size and text color
  float temperatureK = temperature + 273.15; // Convertir a Kelvin
  carrier.display.fillScreen(ST77XX_RED); //red background
  carrier.display.setTextColor(ST77XX_WHITE); //white text
  carrier.display.setTextSize(6); //large sized text
 
  carrier.display.setCursor(30, 50); //sets position for printing (x and y)
  carrier.display.print("Temp: ");
  carrier.display.setTextSize(4); //decreasing text size
  carrier.display.setCursor(40, 120); //sets new position for printing (x and y)
  carrier.display.print(temperatureK);
  carrier.display.print(" K");
}

void printHumidity() {
  //configuring display, setting background color, text size and text color
  carrier.display.fillScreen(ST77XX_BLUE); //red background
  carrier.display.setTextColor(ST77XX_WHITE); //white text
  carrier.display.setTextSize(6); //medium sized text
 
  carrier.display.setCursor(30, 50); //sets position for printing (x and y)
  carrier.display.print("Humi: ");
  carrier.display.setTextSize(4);
  carrier.display.setCursor(40, 120);
  carrier.display.print(humidity);
  carrier.display.println(" %");
}
```

Para hacer ese código lo primero que se nos ocurrió fue hacer 2 mediciones:<br>
- Medición de la temperatura del laboratorio (29.5 °C aprox.)<br>
- Medición de la temperatura del aire acondicionado (hasta 27.5 °C aprox)<br>

<p align="justify">
Luego hicimos algunas modificaciones en el código para que se ponga de color azul cuando estemos midiendo la temperatura del aire acondicionado y rojo cuando estemos midiendo la temperatura del laboratorio (específicamente en nuestra área de trabajo), tal como se muestra a continuación:

```cpp
  if (temperature < 29) {
    carrier.display.fillScreen(ST77XX_BLUE); // Fondo azul si la temperatura es menor a 29°C
  } else {
    carrier.display.fillScreen(ST77XX_RED); // Fondo rojo si la temperatura es mayor o igual a 29°C
  }
```

<div align="center"; style="display: flex; justify-content: space-between;">
  
  
</div>

<p align="justify">
Luego, desde nuestras casas, quisimos implementar las luces led para que enciendan del mismo color de la pantalla y una alerta con el buzzer que tenía incorporado el dispositivo, por lo que decidimos añadir esa parte del código:
</p>

```cpp
void printTemperature() {
  // Configurar la pantalla, establecer el color de fondo, el tamaño del texto y el color del texto
  if (temperature < 29) {
    carrier.display.fillScreen(ST77XX_BLUE); // Fondo azul si la temperatura es menor a 29°C
  	// Iluminar los leds de color azul
  	carrier.leds.setPixelColor(0, 0, 0, 255); 
    carrier.leds.setPixelColor(1, 0, 0, 255);
    carrier.leds.setPixelColor(2, 0, 0, 255);
    carrier.leds.setPixelColor(3, 0, 0, 255);
    carrier.leds.setPixelColor(4, 0, 0, 255); 
	  carrier.leds.show();
  } else {
    carrier.display.fillScreen(ST77XX_RED); // Fondo rojo si la temperatura es mayor o igual a 29°C
	  // Iluminar los leds de color rojo
	  carrier.leds.setPixelColor(0, 255, 0, 0);
    carrier.leds.setPixelColor(1, 255, 0, 0);
    carrier.leds.setPixelColor(2, 255, 0, 0);
    carrier.leds.setPixelColor(3, 255, 0, 0);
    carrier.leds.setPixelColor(4, 255, 0, 0);
	  carrier.leds.show();
  }

  carrier.Buzzer.sound(500); // Se activa la alerta del buzzer
  delay(1000);
  carrier.Buzzer.noSound(); // Se desactiva la alerta del buzzer

  carrier.display.setTextColor(ST77XX_WHITE); // Texto blanco
  carrier.display.setTextSize(6); // Texto de tamaño grande

  carrier.display.setCursor(30, 50); // Establecer la posición para imprimir (x y y)
  carrier.display.print("Temp: ");
  carrier.display.setTextSize(4); // Disminuir el tamaño del texto
  carrier.display.setCursor(40, 120); // Establecer nueva posición para imprimir (x y y)
  carrier.display.print(temperature);
  carrier.display.print(" C");
}
```

Logrando así lo que necesitabamos en este ejercicio.

## 6. Observaciones
<p align="justify">
En cuanto al uso de pilas en los dispositivos IoT, es cierto que muchos de ellos utilizan pilas como fuente de energía. Esto se debe principalmente a que los dispositivos IoT suelen ser pequeños y diseñados para ser autónomos, lo que significa que no siempre tienen acceso a una fuente de alimentación externa, como una toma de corriente. Por lo tanto, las pilas son 
una opción conveniente y práctica para alimentar estos dispositivos. En todos los ejercicios realizados anteriormente se confirmó ello, ya que al colocar una pila al dispositivo ioT, lo hizo más práctico al momento de utilizarlo.
</p>

<div align="center"; style="display: flex; justify-content: space-between;">
  
  
  
</div>

## 7. Evidencias del desarrollo de ejercicios

<div align="center"; style="display: flex; justify-content: space-between;">
  
  
</div>

## 8. Conclusión

<p align="justify">
El Internet de las Cosas (IoT) ofrece un potencial significativo para la interconexión y el control de dispositivos físicos a través de Internet. Además, la capacidad de convertir temperaturas entre diferentes escalas a medida que se adapta y ajustar el formato de la humedad. Asimismo, se vio la capacidad de reconocer la temperatura y cambiar el color de la pantalla, indicando la temperatura ambiente de color rojo y la temperatura en el aire acondicionado de color azul. Esta interconexión brinda la posibilidad de controlar y monitorear dispositivos de manera remota, lo que conduce a beneficios significativos en términos de automatización, eficiencia y comodidad.
</p>

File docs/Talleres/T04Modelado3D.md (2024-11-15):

<p align="center" style="margin-top: 50px; margin-bottom: 50px; font-family: Arial, sans-serif;">
  <p align="center">
    Facultad de Ciencias e ingeniería logo
  </p>  
  <h1 align="center" style="margin-top: 30px; margin-bottom: 0px;">Facultad de Ciencias e ingeniería “Alberto Cazorla Talleri”</h1>
</p>

<h2 align="center" style="font-family: Arial, sans-serif;">Taller 04: Modelado 3D</h2>

<strong> Docentes:</strong>
- Mg Umbert Lewis De La Cruz
- Mg. Paulo Camilo Vela Antón 
- Mg. Moises Stevend Meza Rodriguez 
- Dr. Harry Anderson Rivera Tito 
- Ing. Juan Manuel Zuñiga Mamani  
- Ing. Renzo José Chan Ríos

<strong>Elaborado por:</strong>
- Amparo Marleny Vidaurre Juárez
- Edwin Junior Jara Bocanegra
- Antony Iván Mendoza Villar
- Josue Jhordan Poma Arrieta
- Aracely Nicoll Dueñas Condori
</p>

<hr style="border: 1px solid #ccc; margin-top: 50px; margin-bottom: 50px;">

## 1. Descripción del Modelado 3D (Onshape)

### Características y componentes de Onshape

<p align="justify">
  
- **Modelado paramétrico:** Permite realizar cambios en el diseño de forma rápida y eficiente.<br>
- **Colaboración en tiempo real:** Los usuarios pueden trabajar en un mismo diseño de forma simultánea.<br>
- **Acceso basado en la nube:** Al estar basado en la nube, Onshape permite a los usuarios acceder a sus diseños desde cualquier dispositivo con conexión a internet.<br>
- **Versionado automático:** Onshape guarda automáticamente el historial de versiones de los diseños
</p>

### Importancia del Onshape como herramienta para la creación del modelado 3D

<p align="justify">
Onshape es una herramienta importante para el modelado 3D debido a su accesibilidad, capacidad de colaboración, modelado paramétrico y herramientas integradas para simulaciones y pruebas de rendimiento. Estas características hacen de Onshape una plataforma integral y poderosa para el diseño y la ingeniería colaborativa en 3D.
</p>

## 2. Materiales
- Laptop e implementos
- Software CAD (Onshape)
- Impresora 3D

## 3. Desarrollo de ejercicios
### Ejercicio 1: Representación de un vaso a partir de un círculo

<p align="justify">
Para realizar la representación de un vaso 3D, nos ubicamos en la vista “Top” para añadir un círculo con dimensiones de 60mm, luego nos encargamos de que el círculo se encuentre centrado con la opción “Concentric”.
</p>

<div align="center"; style="display: flex; justify-content: space-between;">
  
</div>

<p align="justify">
Luego realizamos las accion “Extrude” para pasar de un modelo 2D a un modelo 3D con ciertas medidas.
</p>

<div align="center"; style="display: flex; justify-content: space-between;">
  
</div>

<p align="justify">
Después pasamos a quitarle la parte superior del vaso para que se parezca cada vez más un vaso, con la opción de “Shell”.
</p>

<div align="center"; style="display: flex; justify-content: space-between;">
  
</div>

<p align="justify">
Le dimos bordes con la opción “Fillet”, quedando nuestro vaso de la siguiente manera:
</p>

<div align="center"; style="display: flex; justify-content: space-between;">
  
</div>

<p align="justify">
Después escogimos que color queríamos para el vaso y lo seleccionamos.
</p>

<div align="center"; style="display: flex; justify-content: space-between;">
  
</div>

<p align="justify">
Finalmente quedando nuestro diseño del vaso de la siguiente manera:
</p>

<div align="center"; style="display: flex; justify-content: space-between;">
  
</div>

### Ejercicio 2: Representación de un vaso a partir de líneas

Para realizar la representación de un vaso 3D a partir de líneas, comenzamos en la vista "front" y creamos un sketch donde agregamos líneas para esbozar la mitad del vaso en 2D. Utilizando funciones aprendidas en el ejercicio 1, transformamos este diseño bidimensional en uno tridimensional. Las herramientas empleadas permitieron extruir y dar forma al vaso 2D, generando así la representación final en 3D, como se muestra en la segunda imagen.

<div align="center"; style="display: flex; justify-content: space-between;">
  
  
</div>

### Ejercicio 3: Representación de una taza a partir del ejercicio 1

<p align="justify">
Para modelar la taza tuvimos que usar el molde ya hecho de un vaso en el ejercicio 1, partimos ese molde y lo transformamos en una taza funcional y estéticamente diferente al añadirle una asa. Comenzamos dibujando la asa con la herramienta "3 point arc" en un nuevo sketch, ajustándola cuidadosamente para que se integrara bien con la forma existente del vaso. Luego, utilizando las herramientas de modelado en 3D, dimos volumen y forma ergonómica a la asa, haciendo ajustes hasta lograr un diseño atractivo. Finalmente, refinamos la transición entre la asa y el cuerpo del vaso para obtener una apariencia suave y cohesiva.
</p>

<div align="center"; style="display: flex; justify-content: space-between;">
  
</div>

### Ejercicio 4: Representación de un case para Arduino UNO

<p align="justify">
Para realizar la representación del case Arduino UNO, empezamos insertando una imagen en un sketch en “top” y redimensionando un poco para posteriormente empezar a hacer el case.
</p>

<div align="center"; style="display: flex; justify-content: space-between;">
  
</div>

<p align="justify">
Luego de insertar la imagen procedemos a crear un sketch en “top” e insertar líneas tomando la forma del case, luego procedemos a insertar las dimensiones correspondientes.
</p>

<div align="center"; style="display: flex; justify-content: space-between;">
  
</div>

<p align="justify">
Luego usamos la función “extrude” con las líneas hechas anteriormente para darle la forma 3D a nuestro trabajo.
</p>

<div align="center"; style="display: flex; justify-content: space-between;">
  
</div>

<p align="justify">
Luego decidimos quitarle la tapa para que se asemeje al case del Arduino UNO, junto con asignarle un grosor que fue de 1mm.
</p>

<div align="center"; style="display: flex; justify-content: space-between;">
  
</div>

<p align="justify">
Paso extra: Tuvimos que recortar las partes que hacían que el case no entre correctamente luego de darnos cuenta en la impresión 3D, lo hicimos creando un sketch nuevo y dando la forma del rectángulo.
</p>

<div align="center"; style="display: flex; justify-content: space-between;">
  
</div>

<p align="justify">
Paso extra: Usamos la función "extrude" pero con la diferencia de que esta vez la usamos parar borrar la parte que no necesitabamos del case, usando anteriormente los rectángulos, luego ajustamos y damos en enter para completar la eliminación de ese espacio.
</p>

<div align="center"; style="display: flex; justify-content: space-between;">
  
</div>

<p align="justify">
Y al final de todos estos pasos el modelado del case Arduino UNO nos quedó de la siguiente manera:
</p>

<div align="center"; style="display: flex; justify-content: space-between;">
  
</div>

<br>
<p align="justify">
Al momento de imprimir nuestro modelado 3D no tomamos en cuenta que el case debía tener un grosor mínimo de 5mm, nosotros lo hicimos con un grosor de 1mm, por lo que nuestro case salió delgado, y tuvimos otro pequeño error de no considerar los espacios de las entradas del Arduino. Anotamos estos errores para no volverlos a cometer en un futuro.
</p>

<div align="center"; style="display: flex; justify-content: space-between;">
  
  
</div>

## 4. Evidencias del desarrollo de ejercicios

<div align="center"; style="display: flex; justify-content: space-between;">
  
  
  
</div> 
</div>
<div align="center"; style="display: flex; justify-content: space-between;">
  
</div>

## 5. Conclusión

<p align="justify">
Durante la sesión de clase en la que modelamos una vaso ,  taza en la aplicación de Onshape y posteriormente creamos un estuche para un Arduino, adquirimos conocimientos prácticos sobre el modelado en 3D y la aplicación de Onshape. Esta experiencia nos permitió aplicar las habilidades aprendidas en un entorno práctico y nos preparó para el proceso de impresión 3D. En resumen, esta actividad fue fundamental para el desarrollo de nuestras habilidades en el campo del diseño y la fabricación digital.
</p>

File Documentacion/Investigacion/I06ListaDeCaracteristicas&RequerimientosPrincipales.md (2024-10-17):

<p align="left">
  
  <h1 align="center">Entregable 04: Lista de Características y Requerimientos Principales</h1>
</p>

## Objetivo
<p align="justify">Proporcionar una herramienta portátil y precisa para evaluar la viabilidad de instalar aerogeneradores o paneles solares en una ubicación específica.</p>

## Tabla "Función"
| Característica Principal | Característica Secundaria | Estudio del Caso Industrial |
| :---: | :---: | :---: |
| **Material**  |  **Propiedades de entrada y salida** | <p align="justify">Los cables y conectores deben ser duraderos y resistentes a las condiciones ambientales.</p>  |
| | **Materiales prescritos**  | <p align="justify"><strong>Componentes Electrónicos:</strong> Hechos de silicio y plásticos especializados para placas de circuito, garantizando precisión y durabilidad. <strong>Carcasas:</strong> Fabricadas con PLA, conocido por su facilidad de impresión y buen rendimiento mecánico. <strong>Maletín:</strong> Construido con madera o plásticos resistentes, diseñados para soportar condiciones climáticas moderadas. Opcionalmente, se pueden considerar plásticos de ingeniería para mayor durabilidad en condiciones extremas.</p>  |
| **Energía**  | **Energía de conexión**  | <p align="justify">3.3V o 5V</p>  |
| | **Almacenamiento**  | <p align="justify">Batería solar recargable o uso de baterías recargables</p>  |
| **Señal**  | **Medidas de entrada y salida**  | <p align="justify">El anemómetro y piranómetro envían datos de entrada que son procesados y luego tienen salidas específicas para visualización y almacenamiento</p>  |
| | **Estilo de visualización**  | <p align="justify">Pantalla LED</p>  |
| | **Componentes**  | <p align="justify">Incluye microcontrolador, sensores, módulos de comunicación, pantalla LED y LEDs</p>  |
| | **Equipo de monitoreo**  | <p align="justify">Monitoreo en tiempo real a través de la interfaz web del sistema o con la base de datos para seguimiento y análisis</p>  |
| | **Señal (Analógica, Digital)**  | <p align="justify">Tanto analógicas (de sensores) como digitales (de módulos de procesamiento y comunicación)</p>  |
| | **Tiempo, Calidad**  | <p align="justify">Señales con alta precisión y en tiempo real para asegurar la calidad de las mediciones</p>  |
| | **Intercambio de Datos**  | <p align="justify">Datos transmitidos entre el dispositivo y la base de datos hacia la página web, con módulos de ondas de baja frecuencia para uso cuando se pierda la conexión a internet</p>  |
| **Definición de Interfaces**  |  **Mecánico** | <p align="justify">Sistema que asegura un acoplamiento estable de los componentes pequeños como el anemómetro, la veleta y el piranómetro con los microcontroladores</p>  |
| | **Interfaces de software**  | <p align="justify">La aplicación web y la base de datos están diseñadas para recibir y procesar información de los sensores, facilitando el monitoreo y análisis de datos</p>  |
| | **Eléctrico / Electrónico**  | <p align="justify">El Arduino o ESP32 se conectará a través de interfaces específicas que permiten la comunicación efectiva con los sensores y módulos de transmisión. La pantalla LED y los LEDs aseguran una visualización clara de los datos y señales. Todo el cableado y las conexiones están optimizados para minimizar interferencias</p>  |
| | **Ambiente**  | <p align="justify">Apto para para funcionar correctamente en diferentes condiciones ambientales (no extremas), asegurando la transmisión de datos efectiva y la operación correcta del dispositivo en campo</p>  |

## Tabla "Diseño / Estructura"

| Característica Principal  | Característica Secundaria  | Estudio del Caso Industrial  |
| :---: | :---: | :---: |
| **Geometría**  | **Dimensiones**  | <p align="justify">Medidas del maletín: 28 cm × 23 cm × 6 cm, el cual dentro contendrá las carcasas y tapas de medidas 19 cm x 18 cm x 1 cm</p>  |
| | **Número**  | <p align="justify">1 maletín que contiene dentro: 1 anemómetro, 1 veleta y 1 piranómetro, entre otros dispositivos secundarios como la pantalla LED</p>  |
| | **Conexión**  | <p align="justify">El sistema está integrado todo dentro del maletín</p>  |
| | **Extensión**  | <p align="justify">Opciones adicionales en carcasas y tipos de sensores</p>  |
| **Electricidad / Electrónica**  | **Voltaje nominal**  | <p align="justify">Dispositivo de monitoreo: 3.3V o 5V</p>  |
| | **Conexión**  | <p align="justify">Dentro del maletín</p>  |
| | **Disponibilidad de componentes**  | <p align="justify">Relevante: Al menos 5 años de disponibilidad</p>  |
| | **Accesibilidad**  | <p align="justify">Relevante para el mantenimiento</p>  |
| | **Intercambio**  | <p align="justify">Los sensores modulares deben ser fácilmente reemplazables por el cliente, los demás componentes pueden ser cambiados con ayuda de un técnico</p>  |
| **Software**  | **Interfaces**  | <p align="justify">Interfaces internas y externas adaptadas a los requisitos del medidor para asegurar una integración y operación eficiente</p>  |
| | **Actualizaciones**  | <p align="justify">Posible de manera manual</p>  |
| | **Hardware**  | <p align="justify">Compatibilidad con microcontroladores Arduinos o ESP32, garantizando un rendimiento eficiente y flexible para diversas aplicaciones del medidor</p>  |
| | **Capacidad de prueba**  | <p align="justify">Pruebas con diferentes casos simulados de medidas regulares e irregulares para observar el comportamiento del sistema</p>  |
| | **Modos de funcionamiento**  | <p align="justify">Con el modo automático, recibiendo información de manera contínua en la nube y el modo manual, obteniendo la información a través de una tarjeta SD</p>  |
| **Ergonomía**  | **Valor**  | <p align="justify">Relación costo-beneficio favorable, justificando la inversión en comodidad y facilidad de uso</p>  |
| | **Operación lógica**  | <p align="justify">Interfaz intuitiva que facilita el uso del medidor sin necesidad de capacitación extensa</p>  |
| | **Claridad e iluminación**  | <p align="justify">Esenciales para asegurar que el medidor sea fácil de leer y utilizar en diversas condiciones de luz, lo que contribuye a una experiencia de usuario satisfactoria</p>  |
| | **Diseño de forma**  | <p align="justify">Diseño ergonómico en forma de maletín que se adapta al uso manual, proporcionando comodidad y facilidad de manejo y transporte</p>  |

## Tabla "Realización y Producción"

| Característica Principal  | Característica Secundaria  | Estudio del Caso Industrial  |
| :---: | :---: | :---: |
| **Fabricación**  | **Dispositivo de control, monitoreo**  | <p align="justify">El material seleccionado proporcionará el soporte adecuado para alojar los módulos de comunicación y otros componentes esenciales para el funcionamiento del medidor</p>  |
| **Control**  | **Capacidad de medición y prueba**  | <p align="justify">Pruebas rigurosas de medición realizadas en diferentes etapas para verificar el rendimiento y la precisión del medidor</p>  |
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

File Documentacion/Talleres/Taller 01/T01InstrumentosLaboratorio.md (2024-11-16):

<p align="left">
  
  <h1 align="center">Taller 01: Introducción a los equipos e instrumentos del laboratorio</h1>
</p>

## Materiales y equipos utilizados

<p align="center" style="margin-top: 50px; margin-bottom: 50px; font-family: Arial, sans-serif;">

  | Modelo           | Descripción                         | Cantidad |
  | :--------------: | :---------------------------------: | :------: |
  | HY3005BC         | Fuente de Alimentación Regulable     |    1     |
  | UT139C           | Multímetro Digital                  |    1     |
  | AFG1022          | Generador de Señales                 |    1     |
  | TBS 1000C Series | Osciloscopio Digital                 |    1     |
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

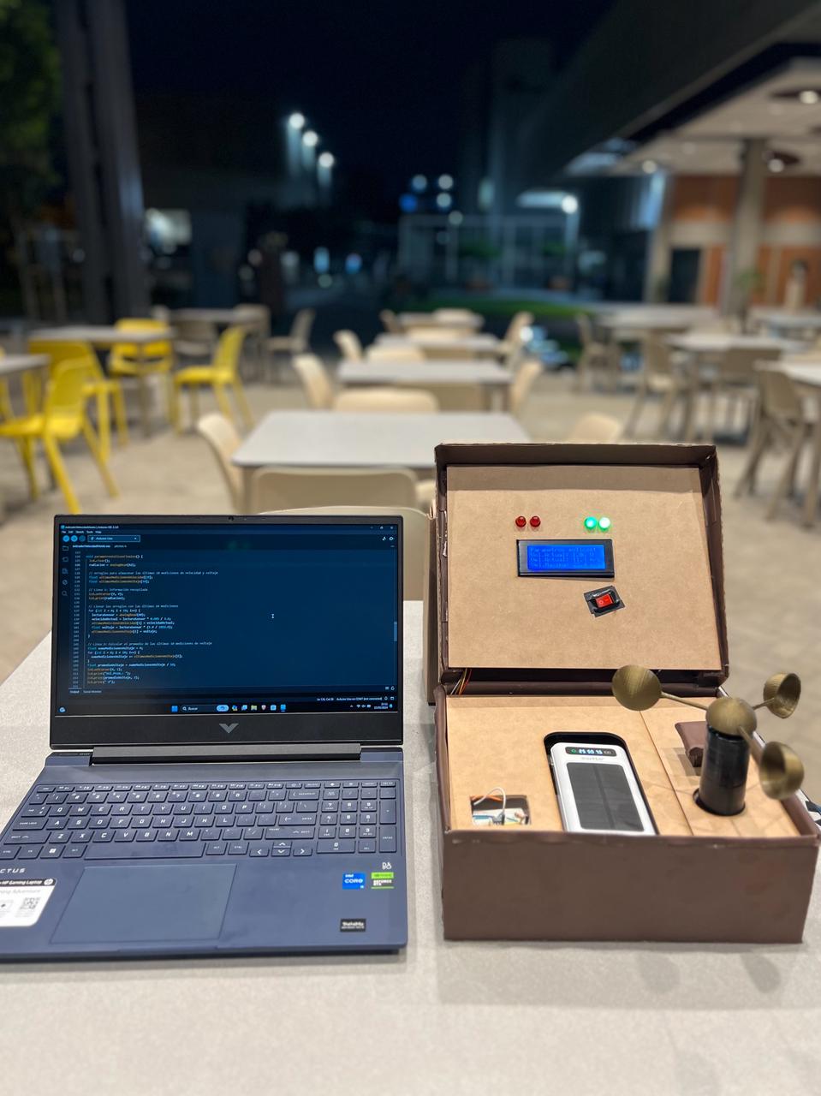
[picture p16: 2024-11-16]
Documentacion/Presentaciones/Fundamentos de Diseño/Imagenes/H02Imagen02.jpg

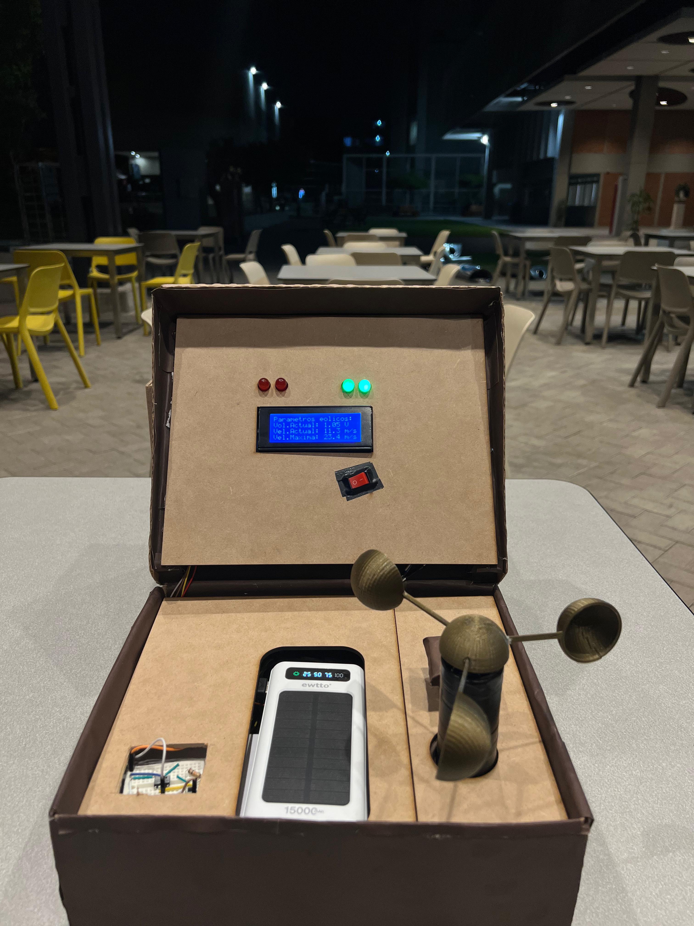
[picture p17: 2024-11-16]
Documentacion/Presentaciones/Fundamentos de Diseño/Imagenes/H02Imagen03.jpg

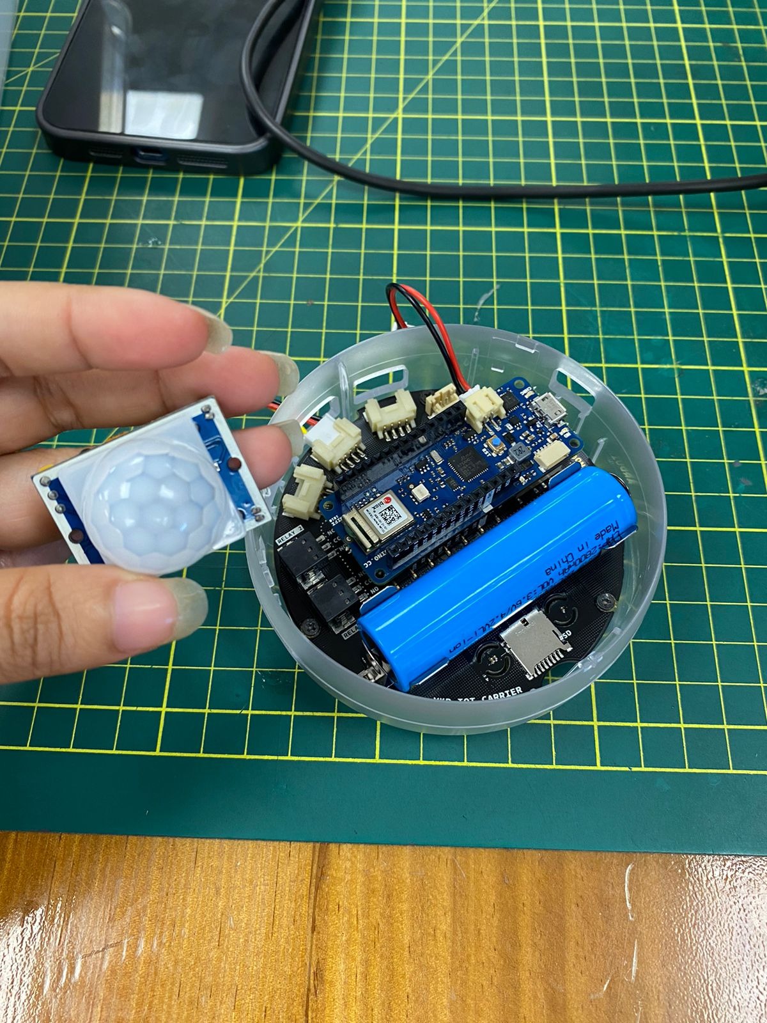
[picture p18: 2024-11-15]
Documentacion/Talleres/Taller 03/Imagenes/T03Imagen15.jpg

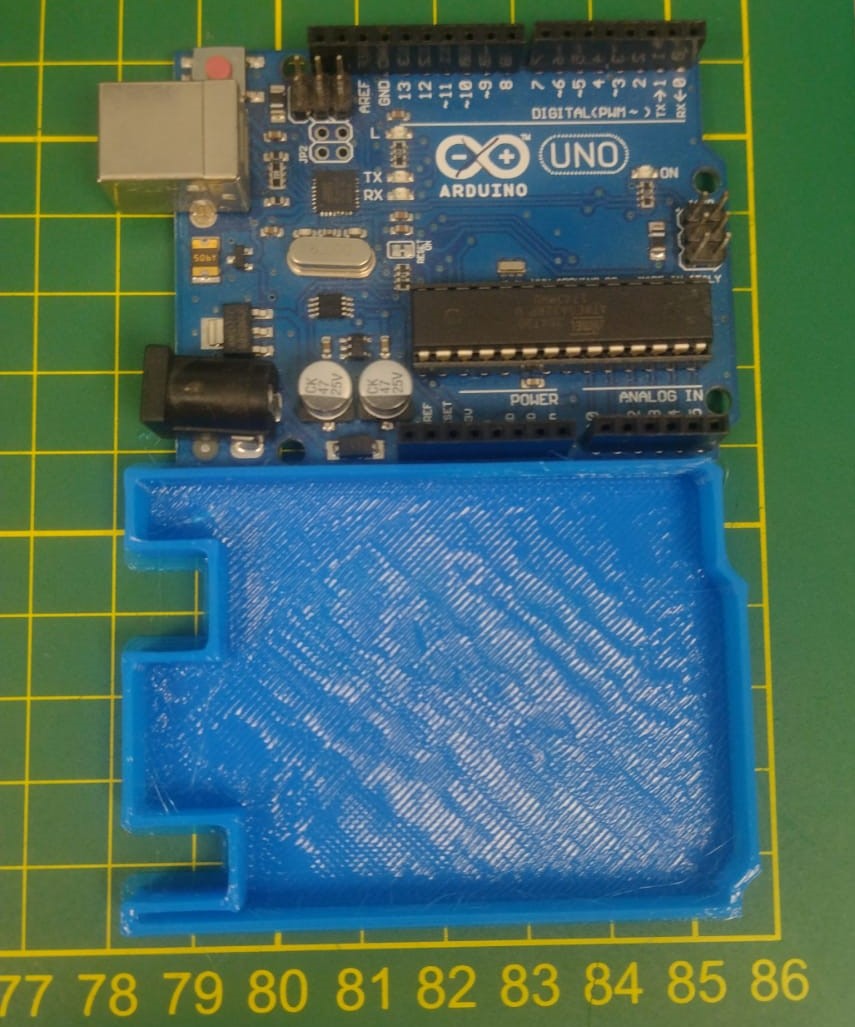
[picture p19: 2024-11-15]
Documentacion/Talleres/Taller 04/Imagenes/T04Imagen20.jpg

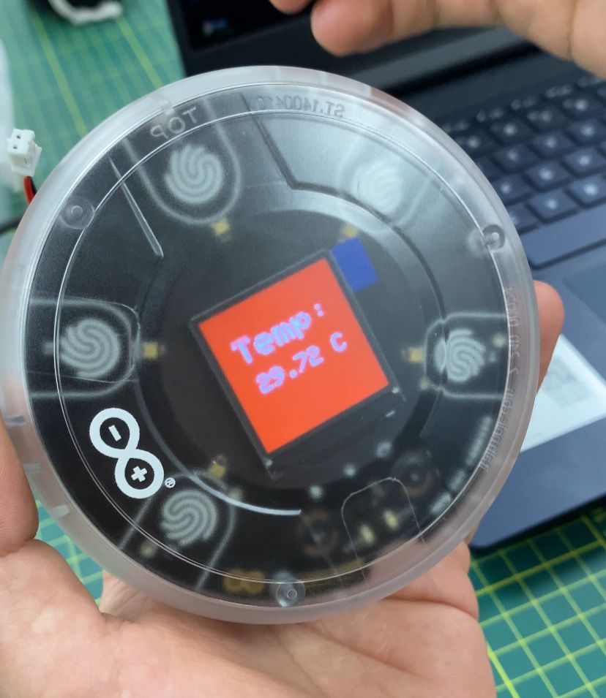
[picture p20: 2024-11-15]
Documentacion/Talleres/Taller 03/Imagenes/T03Imagen08.jpg

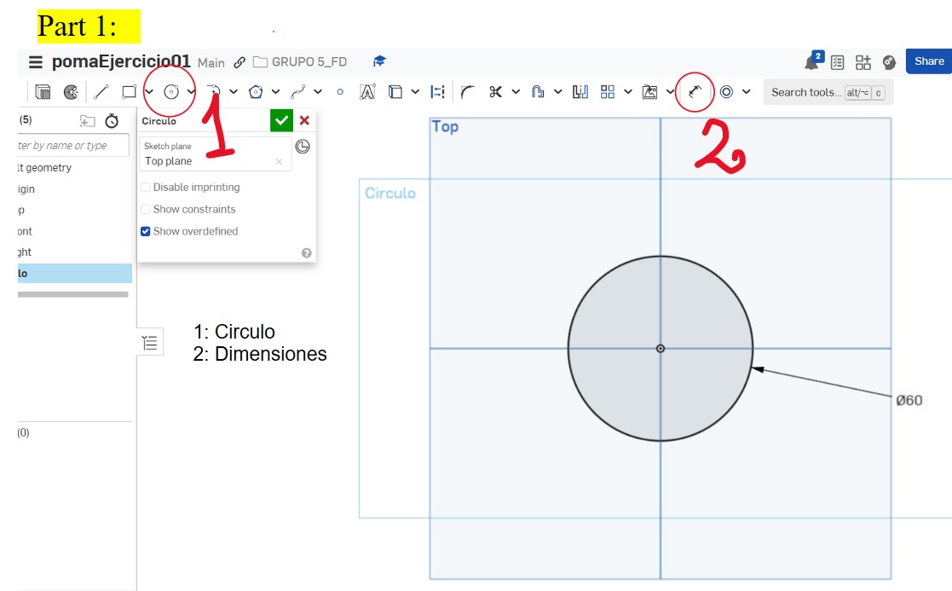
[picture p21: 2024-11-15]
Documentacion/Talleres/Taller 04/Imagenes/T04Imagen01.jpg

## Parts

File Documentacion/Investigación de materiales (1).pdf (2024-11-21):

UNIVERSIDAD PERUANA CAYETANO HEREDIA

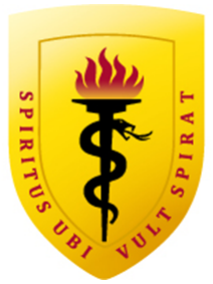
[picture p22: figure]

Facultad de Ciencias e Ingeniería “Alberto Cazorla Talleri”

PROYECTOS DE INGENIERÍA 1

INVESTIGACIÓN DE NORMAS Y MATERIALES

Docentes del curso:

Umbert Lewis de la Cruz Rodriguez

Harry Rivera Tito

Renzo Chan Rios

Moises Meza Rodriguez

GRUPO: 6

Integrantes:

Florián Párraga Josué Abel

Jara Bocanegra Edwin Junior

Pérez Amado Romina Alisson

Pérez Damián Cindy Mayomi

Vasquez Nuñez America Mailyn

Lima, Perú

2024
1.NORMA:
La Organización Meteorológica Mundial (OMM), entidad internacional encargada de la coordinación y normalización de los procedimientos relacionados con el clima y la meteorología, establece que los anemómetros oficiales deben ser instalados en torretas o mástiles ubicados a una altura de 10 metros sobre el nivel del suelo o del mar. Esta altura estándar es fundamental para garantizar la comparabilidad y precisión de las mediciones del viento, ya que permite obtener datos consistentes y representativos de las condiciones atmosféricas en una escala global.

En este contexto, es importante comprender que la velocidad del viento no es una constante, sino que varía significativamente con la altura sobre el suelo. Esta variabilidad está descrita por la Ley Exponencial de Hellmann, la cual establece que la velocidad del viento aumenta de forma exponencial con la altura. Según esta ley, la relación entre la velocidad del viento a una altura dada V(h)V(h)V(h) y la velocidad del viento a otra altura V(h0)V(h_0)V(h0) se puede expresar mediante una ecuación matemática que tiene en cuenta las características del terreno. En términos sencillos, esto significa que si se mide la velocidad del viento a una altura determinada, es posible estimar su valor a otras alturas, lo cual resulta fundamental para la evaluación precisa de los vientos en distintas capas de la atmósfera.

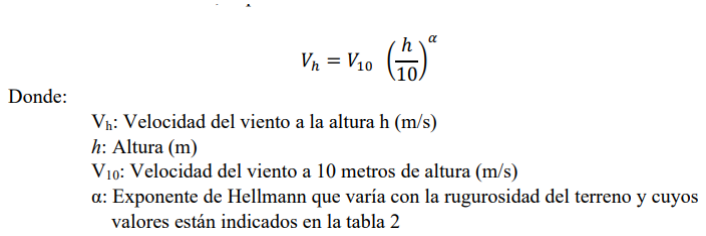
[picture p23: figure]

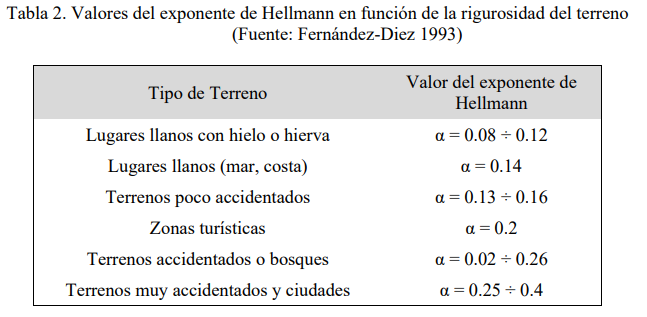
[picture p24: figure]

A partir de la Ley Exponencial de Hellmann, se puede calcular la velocidad del viento a cualquier altura h, siempre que se tenga la medición de la velocidad a una altura de referencia h0. Esta relación se puede modelar a través de la siguiente ecuación:

De esta manera, al conocer la velocidad del viento a una altura de referencia, es posible calcular la velocidad correspondiente a cualquier otra altura, lo que resulta muy útil en estudios meteorológicos y en la planificación de infraestructuras como parques eólicos, donde la variabilidad de la velocidad del viento con la altura tiene un impacto directo en el rendimiento de las turbinas.

En resumen, la Ley Exponencial de Hellmann proporciona una herramienta valiosa para ajustar y extrapolar las mediciones del viento realizadas a distintas alturas, garantizando la precisión de los datos y facilitando su uso en aplicaciones prácticas como la predicción del clima y la evaluación de los recursos eólicos.

1.1 Pruebas realizadas con la ecuación:
Un artículo científico “Valoración del viento como fuente de energía eólica en el estado de Guerrero”, este estudio tiene como objetivo evaluar el potencial de generación de energía eólica en el estado de Guerrero, México. Dado el crecimiento de la energía eólica a nivel global y el desarrollo reciente de esta tecnología en México, la investigación busca identificar las zonas dentro del estado donde el recurso eólico es más viable para el aprovechamiento energético. Para ello, se emplearon datos de velocidad y dirección del viento obtenidos mediante el modelo numérico WRF, que simula condiciones atmosféricas, y se determinaron las velocidades del viento a diferentes alturas para evaluar la factibilidad de instalar aerogeneradores en diversas localidades.

Aplicación de la ecuación de Hellmann: En los resultados, el artículo utiliza la ecuación de Hellmann para extrapolar la velocidad del viento a alturas superiores a partir de mediciones a 10 metros de altura. Esta ecuación permite ajustar la velocidad del viento a diferentes alturas considerando la rugosidad del terreno, representada por el exponente de Hellmann α\alphaα. Para el estudio, el exponente adoptado fue α=0.16\alpha = 0.16α=0.16, aplicable a terrenos poco accidentados, lo cual permitió calcular las velocidades del viento a 30 metros de altura y estimar con mayor precisión el potencial eólico aprovechable en cada punto de la malla generada

### 2. Velocidad de viento:

Según la IDAE (instituto de diversificación y ahorro de energía):
La velocidad mínima de viento necesaria para generar electricidad varía dependiendo del diseño y tipo de aerogenerador, pero en términos generales:
- Aerogeneradores modernos: La velocidad mínima del viento para que comiencen a generar energía (velocidad de arranque o "cut-in") suele estar entre 3 y 5 metros por segundo (m/s), que equivale a unos 11-18 km/h.
- Velocidad óptima: Para generar electricidad de manera eficiente, los aerogeneradores requieren velocidades de viento de 10 a 15 m/s (36-54 km/h).
- Velocidad máxima de seguridad: Por encima de los 25 m/s (90 km/h), la mayoría de los aerogeneradores modernos se detienen automáticamente para evitar daños.

En zonas con vientos más bajos, las turbinas diseñadas específicamente para baja velocidad pueden funcionar con vientos desde 2 m/s. Esto se ve frecuentemente en aplicaciones pequeñas o domésticas.

### 3. Irradiancia solar:

La irradiancia mínima requerida para generar energía eléctrica con paneles solares fotovoltaicos depende de varios factores, incluidos el tipo de tecnología del panel y el diseño del sistema, pero en general:

Valores aproximados:

- Irradiancia mínima utilizable: Los paneles solares modernos pueden generar energía a partir de irradiancias tan bajas como 100 W/m² . Sin embargo, la generación de energía a este nivel será mínima.
- Irradiancia óptima según el Ministerio de Energía y Minas: Para obtener un rendimiento significativo, los paneles suelen requerir al menos 500-1000 W/m² , que corresponden a niveles de irradiancia en un día soleado típico al mediodía.
- Condiciones de baja irradiancia : Los paneles solares con tecnología avanzada, como los de silicio monocristalino, son más eficientes en condiciones de baja irradiancia (eg, días nublados), aprovechando hasta el 10-20% de la luz incidente.

### 4. MATERIAL DEL CASE:

Evaluación del Uso de PLA en Aplicaciones Expuestas al Calor:

El ácido poliláctico (PLA) es uno de los materiales más utilizados en impresión 3D gracias a su facilidad de uso, costo accesible y carácter ecológico. Este polímero se deriva de materias primas renovables, como el almidón de maíz, las raíces de tapioca y la caña de azúcar, lo que permite que, bajo ciertas condiciones, sea biodegradable. Sin embargo, el PLA tiene limitaciones importantes relacionadas con su desempeño en entornos de alta temperatura, lo que restringe su aplicabilidad en escenarios con exposición prolongada al sol o al calor.

Comportamiento térmico del PLA:

El PLA tiene una temperatura de reblandecimiento (HDT) de aproximadamente 55-60°C, lo que significa que comienza a perder rigidez y a deformarse cuando alcanza este rango térmico. En entornos cálidos, como vehículos o exteriores durante los meses de verano, las temperaturas pueden fácilmente superar este umbral, lo que provoca deformaciones significativas en las piezas impresas. Estudios recientes han demostrado que esta vulnerabilidad limita su uso en condiciones de exposición constante al sol, donde las temperaturas superficiales pueden alcanzar hasta 70°C o más en climas cálidos.

Incluso en climas templados, la exposición prolongada puede causar deformaciones graduales, reduciendo la funcionalidad y vida útil de los objetos fabricados con PLA.

Alternativas para mejorar el rendimiento térmico

Para aplicaciones que exigen mayor resistencia al calor, se pueden considerar las siguientes alternativas al PLA convencional:

1. PLA reforzado: Los compuestos como el PLA+ incluye aditivos o mezclas que aumentan ligeramente la resistencia térmica y mecánica. Aunque sigue siendo biodegradable, estas mejoras no suelen ser suficientes para aplicaciones en exteriores con exposición intensa al calor.
2. PETG (tereftalato de polietileno glicol-modificado): Este material combina durabilidad y resistencia al calor, soportando temperaturas de hasta 70-80°C sin deformarse. Es más resistente a la intemperie y menos quebradizo que el PLA, lo que lo convierte en una opción adecuada para proyectos exteriores.
3. ABS (acrilonitrilo butadieno estireno): Reconocido por su alta tolerancia térmica, el ABS puede resistir temperaturas cercanas a 100°C, lo que lo hace ideal para aplicaciones industriales o automotrices. Sin embargo, su impresión es más compleja, ya que requiere mayores temperaturas de extrusión y cama caliente, además de emitir vapores que deben ser manejados en un entorno ventilado (Torrado Pérez & Shemelya, 2020).
4. Nylon y compuestos avanzados: Para aplicaciones de alto rendimiento, los materiales como el nylon o polímeros compuestos ofrecen propiedades superiores en resistencia térmica y mecánica, aunque a un costo mayor y con mayor dificultad de impresión.

Impacto ambiental y sostenibilidad

Aunque el PLA es un material renovable y biodegradable, su degradación efectiva sólo ocurre bajo condiciones industriales específicas, como alta humedad y temperaturas superiores a 58°C, que no se encuentran en entornos naturales comunes (Kim & Choi, 2018). Por otro lado, materiales como PETG y ABS, aunque no biodegradables, ofrecen una mayor durabilidad y, por ende, una vida útil más prolongada, lo que puede mitigar su impacto ambiental en aplicaciones críticas.

Recomendaciones para aplicaciones específicas

Para aplicaciones que requieren alta resistencia térmica o exposición prolongada al sol, se recomienda optar por materiales como PETG o ABS. Si se utiliza PLA, es fundamental garantizar que las piezas no estén expuestas a temperaturas superiores a 50°C y se empleen diseños reforzados para minimizar la deformación.

Comparaciones de ambos materiales:

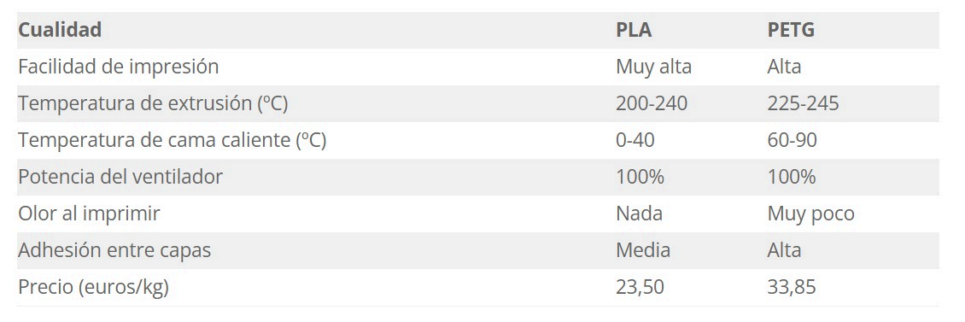
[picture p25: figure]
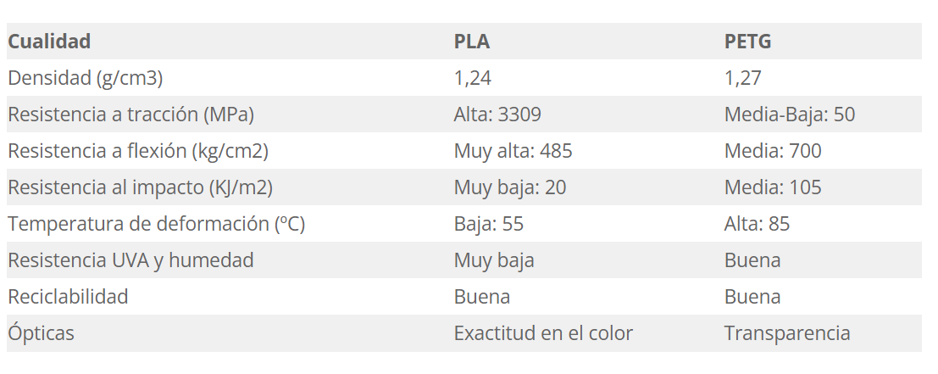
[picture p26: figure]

Referencias bibliográficas:

Álvarez, C. (2006, September). Energía eólica (IDAE, Ed.) [Review of Energía eólica]. Instituto Para La Diversificación Y Ahorro de La Energía; Instituto para la
Diversificación | y | Ahorro | de | la | Energía.
http://www.esengrupo.com/uploads/descargas/archivo/Manual%20de%20Energ%C3 %ADa%20E%C3%B3lica%20IDAE.pdf (http://www.esengrupo.com/uploads/descargas/archivo/Manual%20de%20Energ%C3%ADa%20E%C3%B3lica%20IDAE.pdf)

Collado, R. B. (s/f). INVESTIGACIÓN DE MATERIALES PARA IMPRESIÓN 3D DE TEJIDOS. Upm.es. Recuperado el 21 de noviembre de 2024, de https://oa.upm.es/71120/3/TFM_RAQUEL_BANEGIL_COLLADO.pdf

Fap Wilar, M., Molina, G., Fap, C., Cruzado, R., Senamhi, D., & Quijandría Salmón,
J. (n.d.). SERVICIO NACIONAL DE METEOROLOGÍA E HIDROLOGÍA DIRECCIÓN GENERAL DE INVESTIGACIÓN Y ASUNTOS AMBIENTALES MINISTERIO DE ENERGÍA Y MINAS DIRECCIÓN EJECUTIVA DE PROYECTOS REPÚBLICA DEL
PERÚ | ATLAS | DE | ENERGÍA | SOLAR | DEL | PERÚ.
https://www.senamhi.gob.pe/pdf/Atlas%20_de_Radiacion_Solar.pdf

Uribe, I. M. (2018). Valoración del viento como fuente de energía eólica en el estado de Guerrero. Ingeniería, 22(3), 30-46.

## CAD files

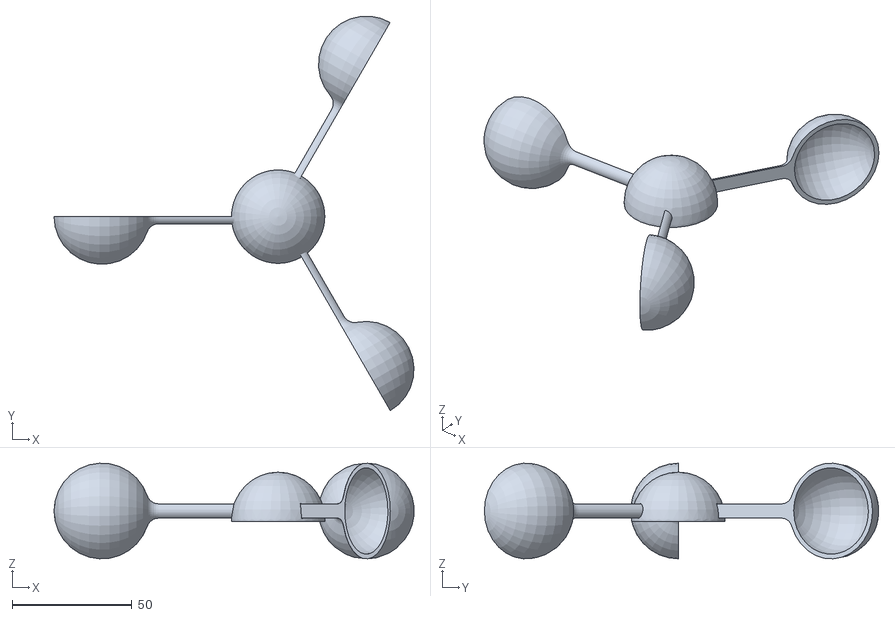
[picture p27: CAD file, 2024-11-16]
Prototipo/Hardware/H03Modelado3D/Cases/ANEM_COMPLETO.stl
150.3 x 164.7 x 39.9

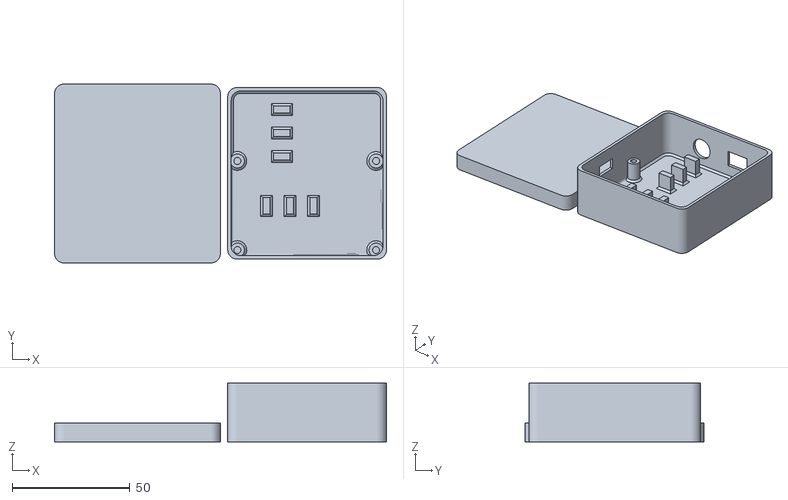
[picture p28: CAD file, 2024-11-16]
Prototipo/Hardware/H03Modelado3D/Cases/NANO_COMPLETO.stl
141.1 x 76.0 x 25.0

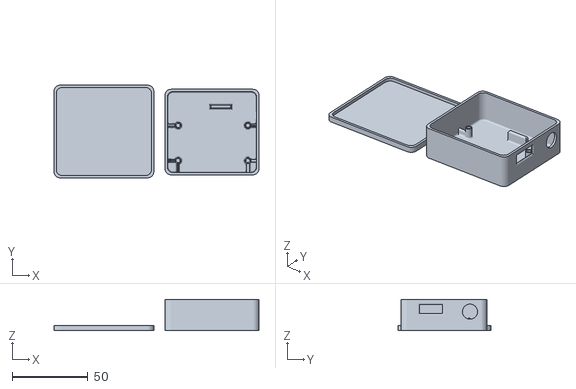
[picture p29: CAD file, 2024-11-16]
Prototipo/Hardware/H03Modelado3D/Cases/ESP32_COMPLETO.stl
135.5 x 61.3 x 20.6

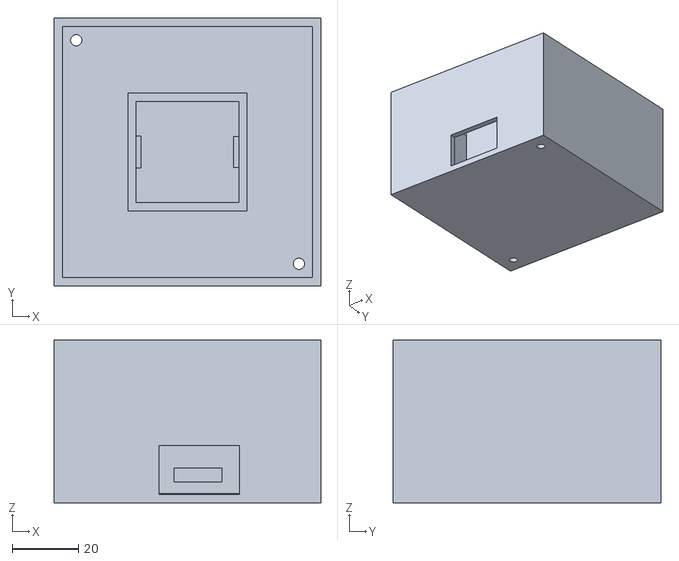
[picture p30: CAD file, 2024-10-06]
Prototipo/Hardware/H03Modelado3D/Cases/SUF268J001_SIN_SENSOR.stl
80.5 x 80.6 x 49.1

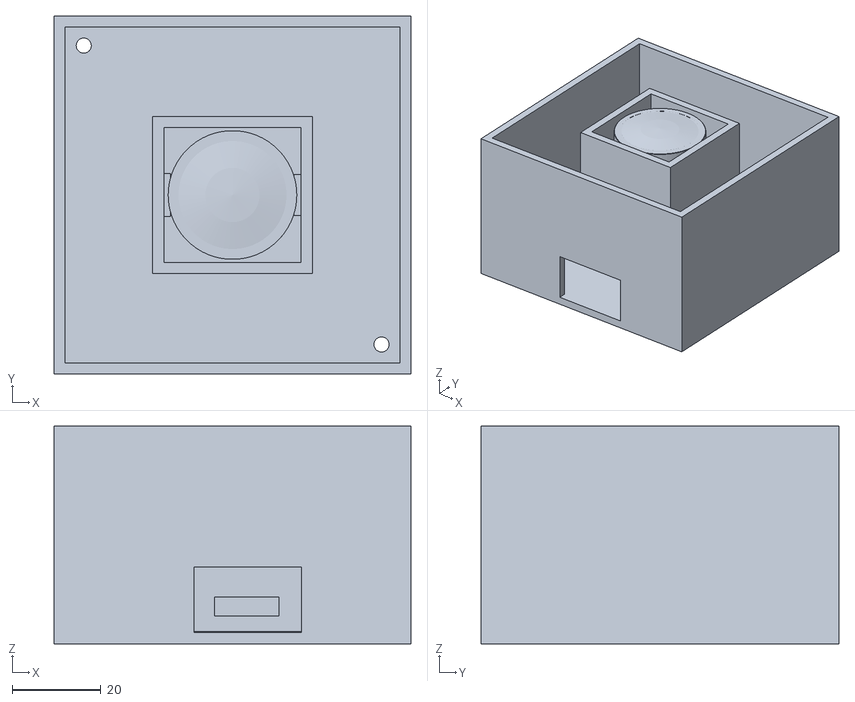
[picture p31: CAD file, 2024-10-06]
Prototipo/Hardware/H03Modelado3D/Cases/SUF268J001_CON_SENSOR.stl
80.5 x 80.6 x 49.1

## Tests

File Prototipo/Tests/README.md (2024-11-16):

<p align="left">
  
  <h1 align="center">Pruebas Técnicas</h1>
</p>

Esta carpeta contiene scripts de pruebas diseñados para validar la funcionalidad del **VentusSolaris Analyzer**.

## Contenido

- **`test_solar.py`**: Pruebas unitarias para el módulo solar.
- **`test_eolico.py`**: Pruebas unitarias para el módulo eólico.
- **`test_interface.py`**: Pruebas para la interfaz de usuario.

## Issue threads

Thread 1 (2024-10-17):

FOLLETO INFORMATIVO

EdwinJaraOFC, 2024-10-17:
- Desarrollar un folleto sencillo que explique el proyecto.
- Destacar los beneficios y la aplicación del sistema en energías renovables.
- Asegurar que el lenguaje sea accesible para todo público.

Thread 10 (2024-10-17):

INTEGRACIÓN HARDWARE - SOFTWARE

EdwinJaraOFC, 2024-10-17:
- Asegurar que el hardware se comunique correctamente con el software.
- Verificar la fluidez en la captura y procesamiento de datos.
- Solucionar problemas de latencia o errores en la comunicación entre ambos.

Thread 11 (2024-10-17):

ADQUISICIÓN DE COMPONENTES

EdwinJaraOFC, 2024-10-17:
-  [ ] Comprar los componentes electrónicos faltantes.
       - Sensores
       - Arduino nano
       - Molex
       - Maletín
-  [ ] Verificar la calidad y compatibilidad de los componentes antes de su integración.
-  [ ] Asegurarse de que todos lleguen a tiempo para las pruebas.

Closed 2024-10-28.

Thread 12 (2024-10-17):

DESARROLLO ESQUEMÁTICO ELECTRÓNICO

EdwinJaraOFC, 2024-10-17:
- [ ] Diseñar los esquemas de las interconexiones de los componentes.
- [ ] Documentar claramente cada conexión para facilitar el ensamblaje.
- [ ] Asegurar que el esquema sea comprensible para todo el equipo.

Closed 2024-10-24.

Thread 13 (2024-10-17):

DESARROLLO PCB

EdwinJaraOFC, 2024-10-17:
- [ ] Diseñar las placas de circuito impreso (PCB) para el sistema.
- [ ] Optimizar el diseño para minimizar el espacio y asegurar la eficiencia.
- [ ] Imprimir las PCB y verificar su funcionalidad antes de ensamblarlas.

Closed 2024-10-24.

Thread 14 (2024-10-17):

DISEÑO DE LOGOTIPO

EdwinJaraOFC, 2024-10-17:
- Diseño finalizado del logotipo, que será utilizado en materiales de difusión.
- Representa visualmente la identidad del proyecto VentusSolaris.
- El logotipo será empleado en la página web, folletos y póster del proyecto

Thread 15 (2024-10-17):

ORGANIZACIÓN DE REPOSITORIO

EdwinJaraOFC, 2024-10-17:
- [ ] Estructurar el repositorio de GitHub con todos los archivos del proyecto.
- [ ] Incluir código, documentación técnica y versiones del software.
- [ ] Asegurarse de que todo esté bien documentado y accesible

Closed 2024-10-28.

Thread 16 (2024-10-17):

INVESTIGACIÓN DE MATERIALES

EdwinJaraOFC, 2024-10-17:
- [ ] Investigar materiales adecuados para la impresión 3D de las carcasas.
- [ ] Considerar durabilidad, costo y facilidad de manufactura.
- [ ] Documentar los hallazgos para facilitar la toma de decisiones.

Closed 2024-10-28.

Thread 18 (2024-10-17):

PRESENTACIONES

EdwinJaraOFC, 2024-10-17:
- Desarrollar el contenido para la presentación del proyecto.
- Incluir diapositivas, imágenes, y una demostración en vivo.
- Ensayar la presentación para garantizar fluidez y claridad

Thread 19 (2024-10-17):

DESARROLLO DISEÑO 3D

EdwinJaraOFC, 2024-10-17:
- [ ] Diseñar las carcasas y soportes en software de modelado 3D.
- [ ] Asegurarse de que los diseños sean funcionales y optimicen el espacio.
- [ ] Preparar los archivos para la impresión en PLA.

Closed 2024-10-28.

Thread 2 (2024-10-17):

DESARROLLO DE PÁGINA WEB

EdwinJaraOFC, 2024-10-17:
- Crear una página web que sirva como plataforma de difusión del proyecto.
- Incluir detalles técnicos, avances del proyecto e imágenes.
- Diseñar una interfaz fácil de navegar y atractiva.

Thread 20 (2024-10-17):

DISEÑO DE LOGOTIPO

EdwinJaraOFC, 2024-10-17:
- [x]  Diseño finalizado del logotipo, que será utilizado en materiales de difusión.
- [x]  Representa visualmente la identidad del proyecto VentusSolaris.
- [x]  El logotipo será empleado en la página web, folletos y póster del proyecto.

RominaPerezAmado, 2024-10-31:
Listo

Closed 2024-10-17.

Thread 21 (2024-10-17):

DESARROLLO DEL SOFTWARE

EdwinJaraOFC, 2024-10-17:
- [ ] **Arduino Nano**: Programar en Arduino IDE para recibir y procesar datos de los sensores (radiación solar y velocidad del viento).
- [ ] **ESP32**: Configurar para recibir datos del Arduino Nano y enviarlos a la nube mediante Wi-Fi.
- [ ] **Comunicación RF24L01**: Implementar comunicación entre Arduino Nano y ESP32 utilizando módulos RF24L01.
- [ ] **Cálculo Velocidad del Viento**: Implementar una ecuación matemática para estimar la velocidad del viento a diferentes alturas, usando 10 metros como altura de referencia.
- [ ] **Integración de Sensor de Radiación Solar**: Verificar que el sensor SUF268J001 esté recibiendo y enviando datos correctamente.
- [ ] **Optimización y Depuración**: Mejorar la eficiencia del código y manejar errores de transmisión.

Closed 2024-11-15.

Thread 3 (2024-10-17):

PRESENTACIÓN FINAL

EdwinJaraOFC, 2024-10-17:
- Preparar la exposición del proyecto incluyendo una demostración en vivo.
- Crear una estructura clara para explicar los objetivos, el desarrollo y los resultados.
- Ensayar la presentación con todos los miembros del equipo.

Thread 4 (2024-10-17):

PÓSTER DE PROYECTO

EdwinJaraOFC, 2024-10-17:
- Diseñar un póster que resuma los objetivos del proyecto.
- Incluir metodología, resultados esperados y relevancia.
- Crear un diseño visualmente atractivo para la presentación final.
- Imprimir el póster

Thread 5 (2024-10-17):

ARTÍCULO / SOLICITUD DE PATENTE

EdwinJaraOFC, 2024-10-17:
- Redactar un artículo técnico que describa el proyecto VentusSolaris.
- Cumplir con los requisitos para una solicitud de patente si se elige ese camino.
- Destacar la innovación y aplicación práctica del sistema.

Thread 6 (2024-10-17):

ACONDICIONAMIENTO DE MALETÍN

EdwinJaraOFC, 2024-10-17:
- [ ] Pintar el maletín para darle un acabado profesional.
- [ ] Organizar el interior asegurando que los componentes estén distribuidos eficientemente.

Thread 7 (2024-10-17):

TEST - HARDWARE

EdwinJaraOFC, 2024-10-17:
- [ ] Probar cada componente individualmente, como sensores y microcontroladores.
- [ ] Asegurarse de que todos los componentes funcionen correctamente bajo diferentes condiciones.
- [ ] Documentar cualquier error o ajuste que se deba realizar.

Closed 2024-11-15.

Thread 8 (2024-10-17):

TEST - SOFTWARE

EdwinJaraOFC, 2024-10-17:
- [ ] Verificar que el software capture los datos correctamente desde los sensores.
- [ ] Evaluar el rendimiento del software, verificar si está propenso a errores.
- [ ] Identificar y corregir errores en la funcionalidad del sistema.

Closed 2024-10-31.

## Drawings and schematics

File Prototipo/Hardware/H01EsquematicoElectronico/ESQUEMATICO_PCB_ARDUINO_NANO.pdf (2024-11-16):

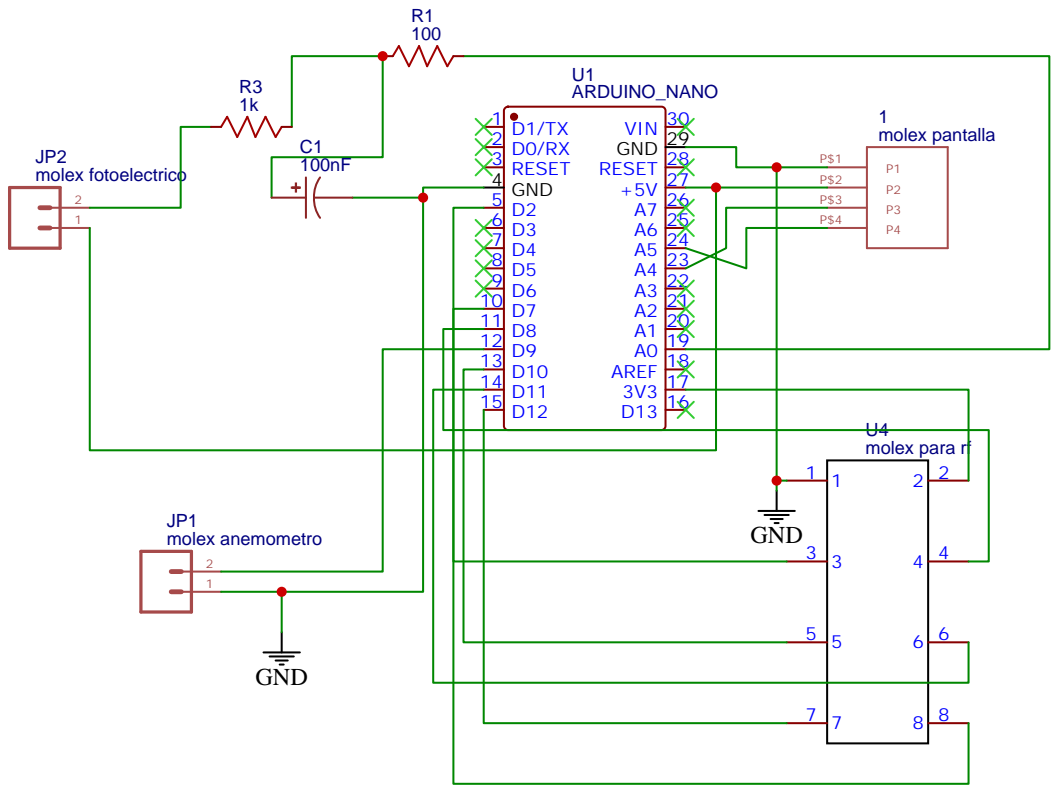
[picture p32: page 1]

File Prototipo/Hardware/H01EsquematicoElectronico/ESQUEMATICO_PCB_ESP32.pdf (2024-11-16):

A | A

1

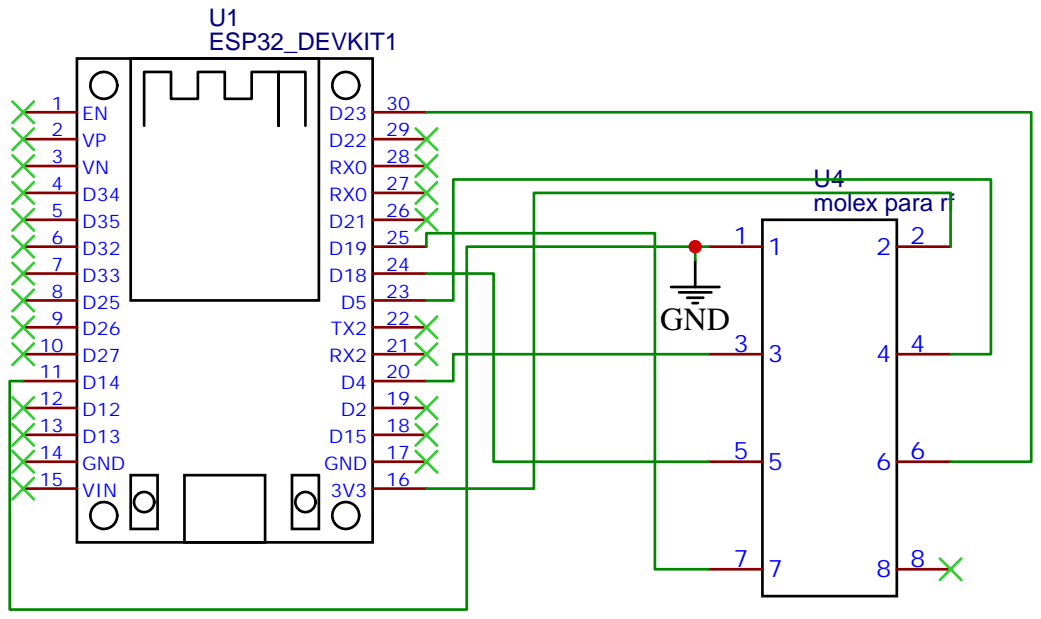
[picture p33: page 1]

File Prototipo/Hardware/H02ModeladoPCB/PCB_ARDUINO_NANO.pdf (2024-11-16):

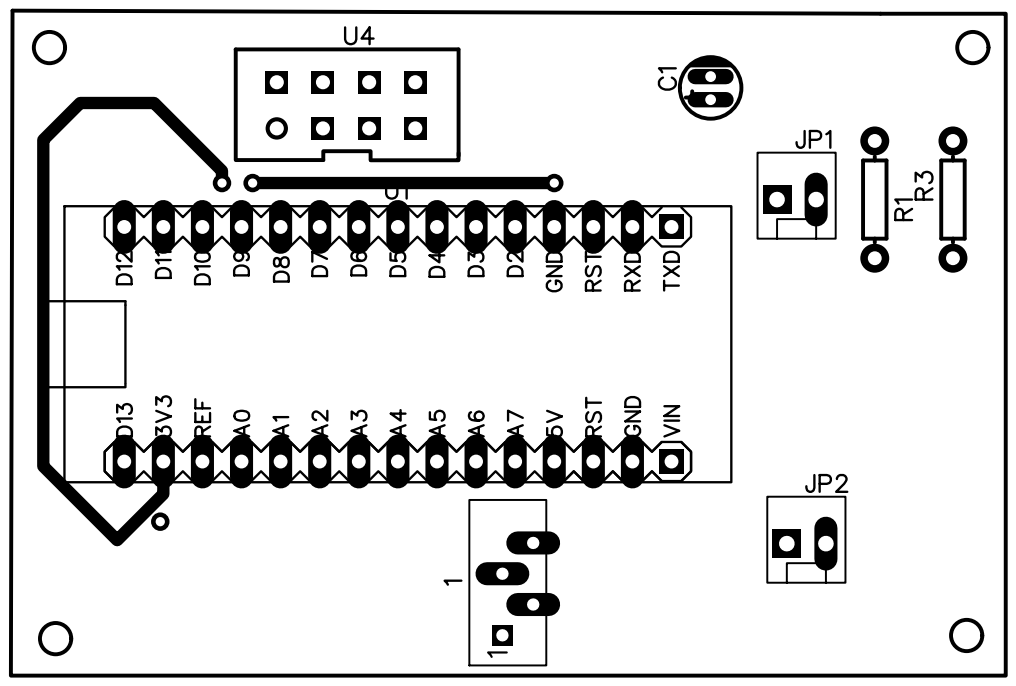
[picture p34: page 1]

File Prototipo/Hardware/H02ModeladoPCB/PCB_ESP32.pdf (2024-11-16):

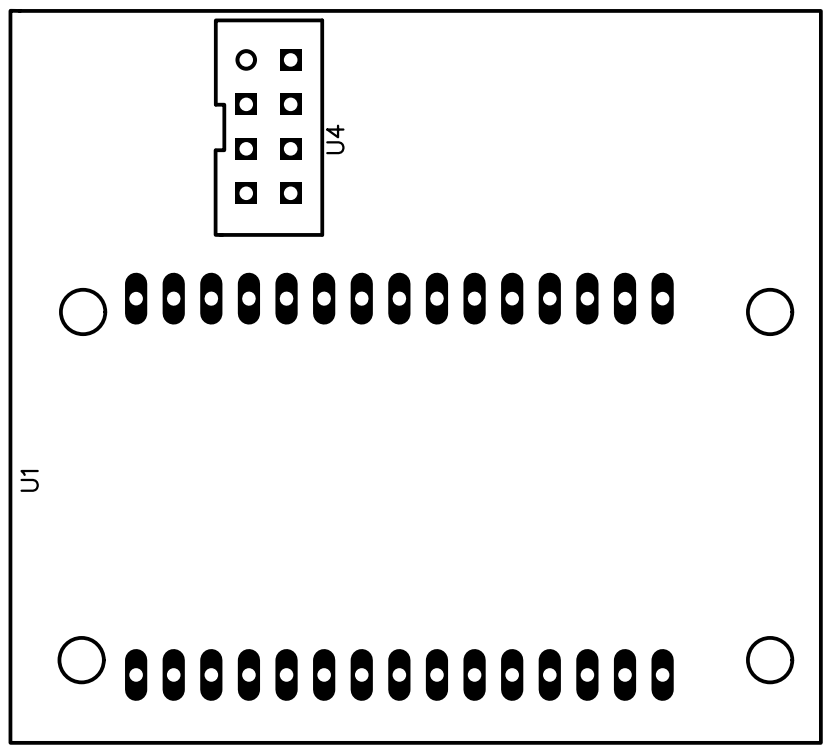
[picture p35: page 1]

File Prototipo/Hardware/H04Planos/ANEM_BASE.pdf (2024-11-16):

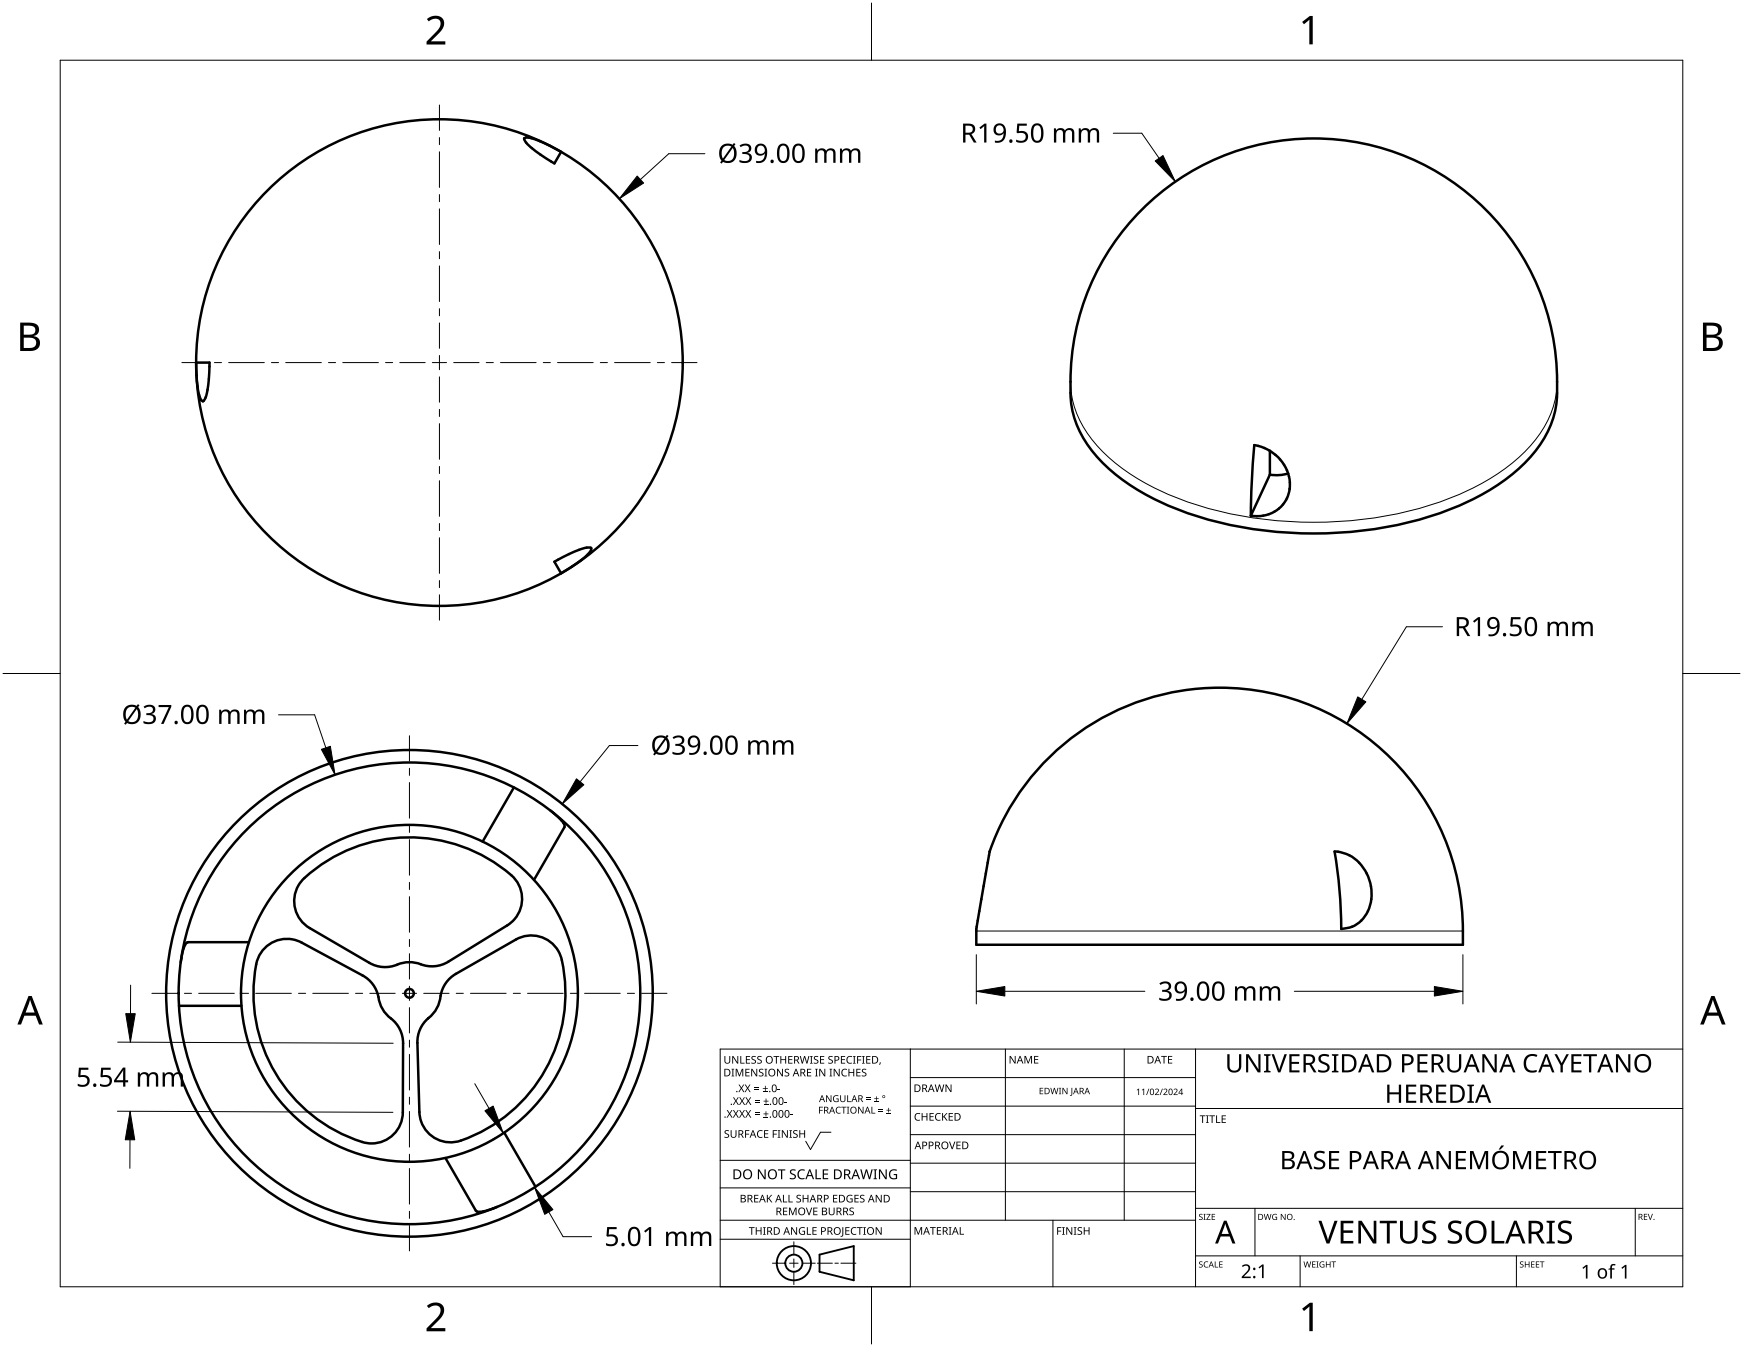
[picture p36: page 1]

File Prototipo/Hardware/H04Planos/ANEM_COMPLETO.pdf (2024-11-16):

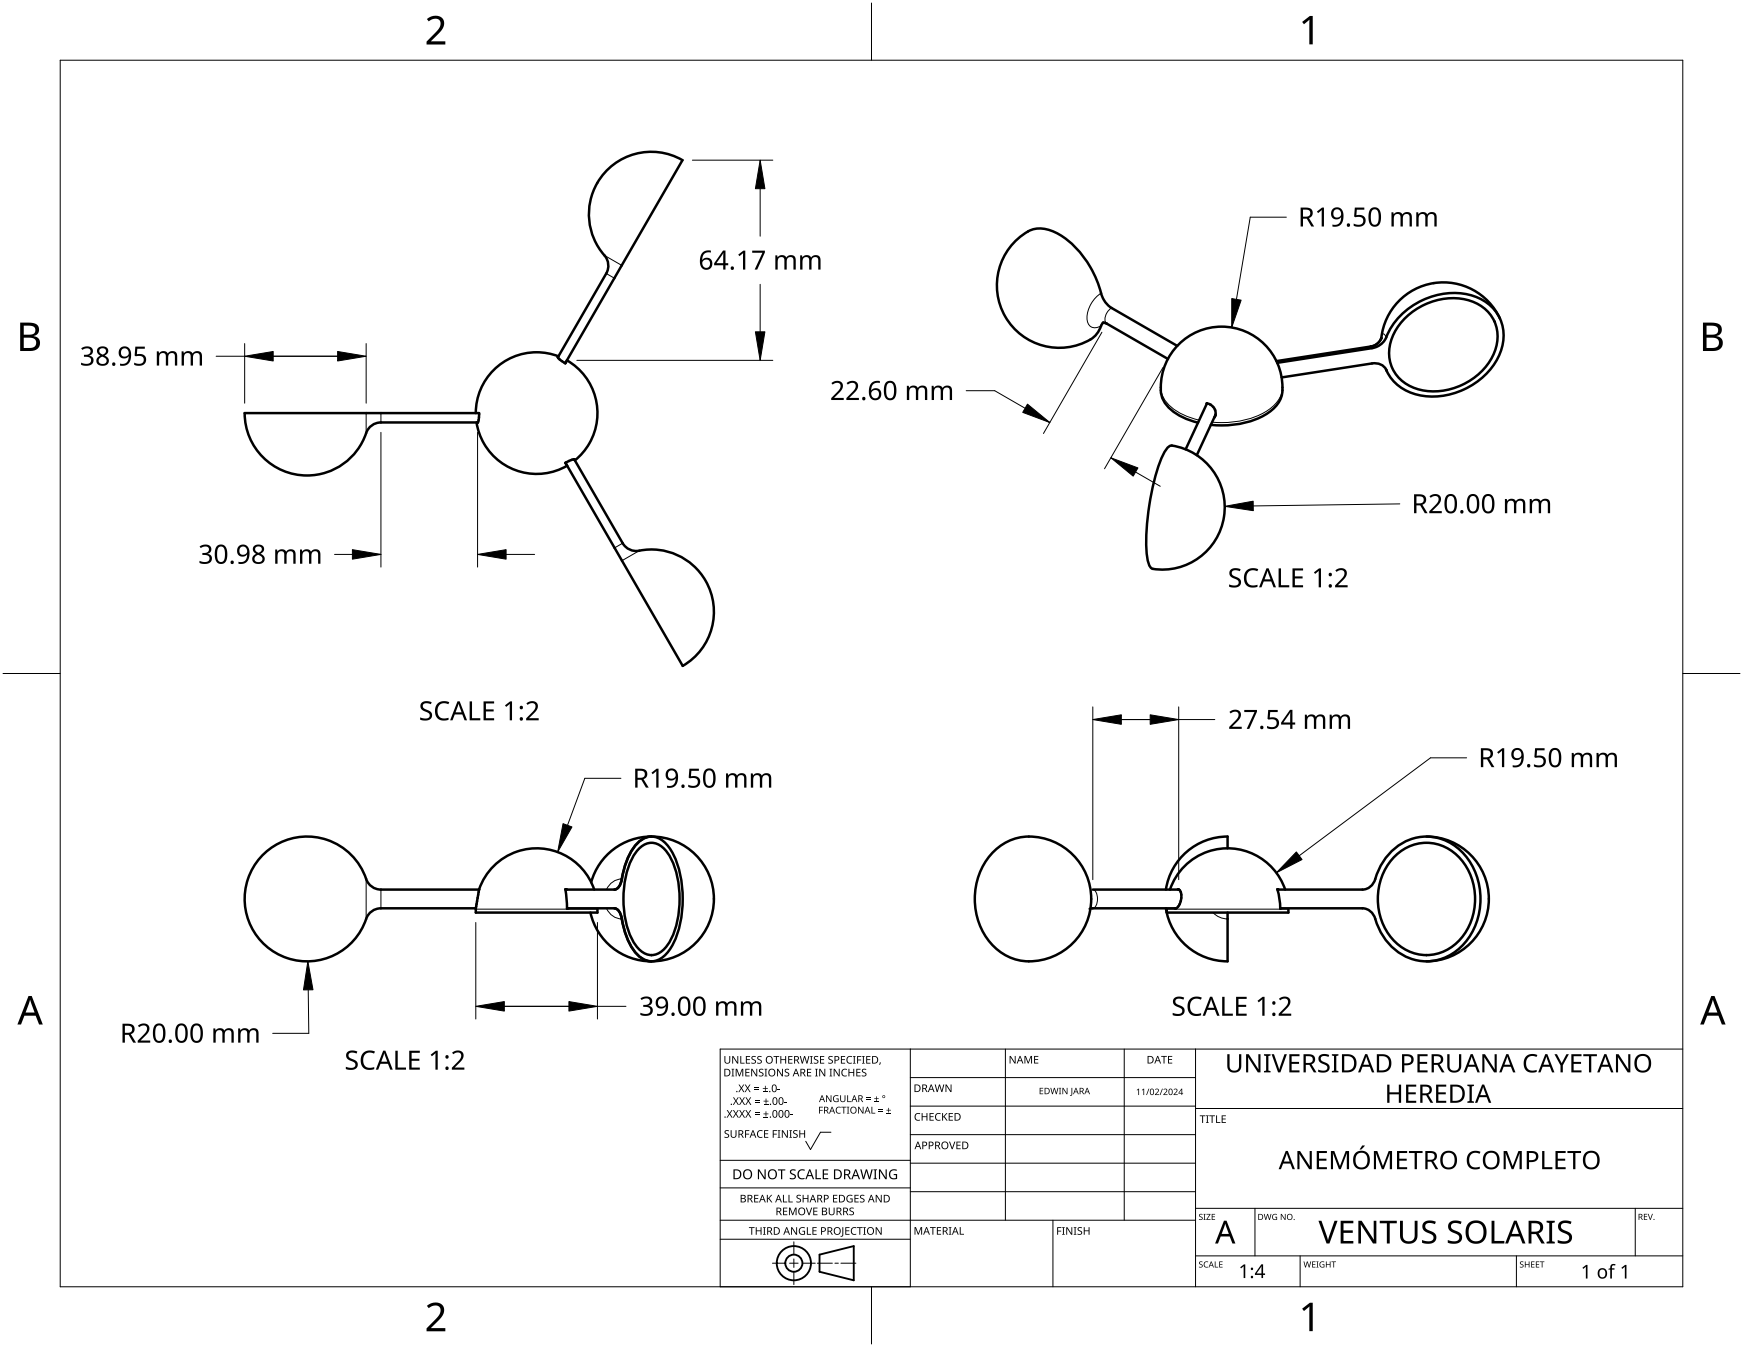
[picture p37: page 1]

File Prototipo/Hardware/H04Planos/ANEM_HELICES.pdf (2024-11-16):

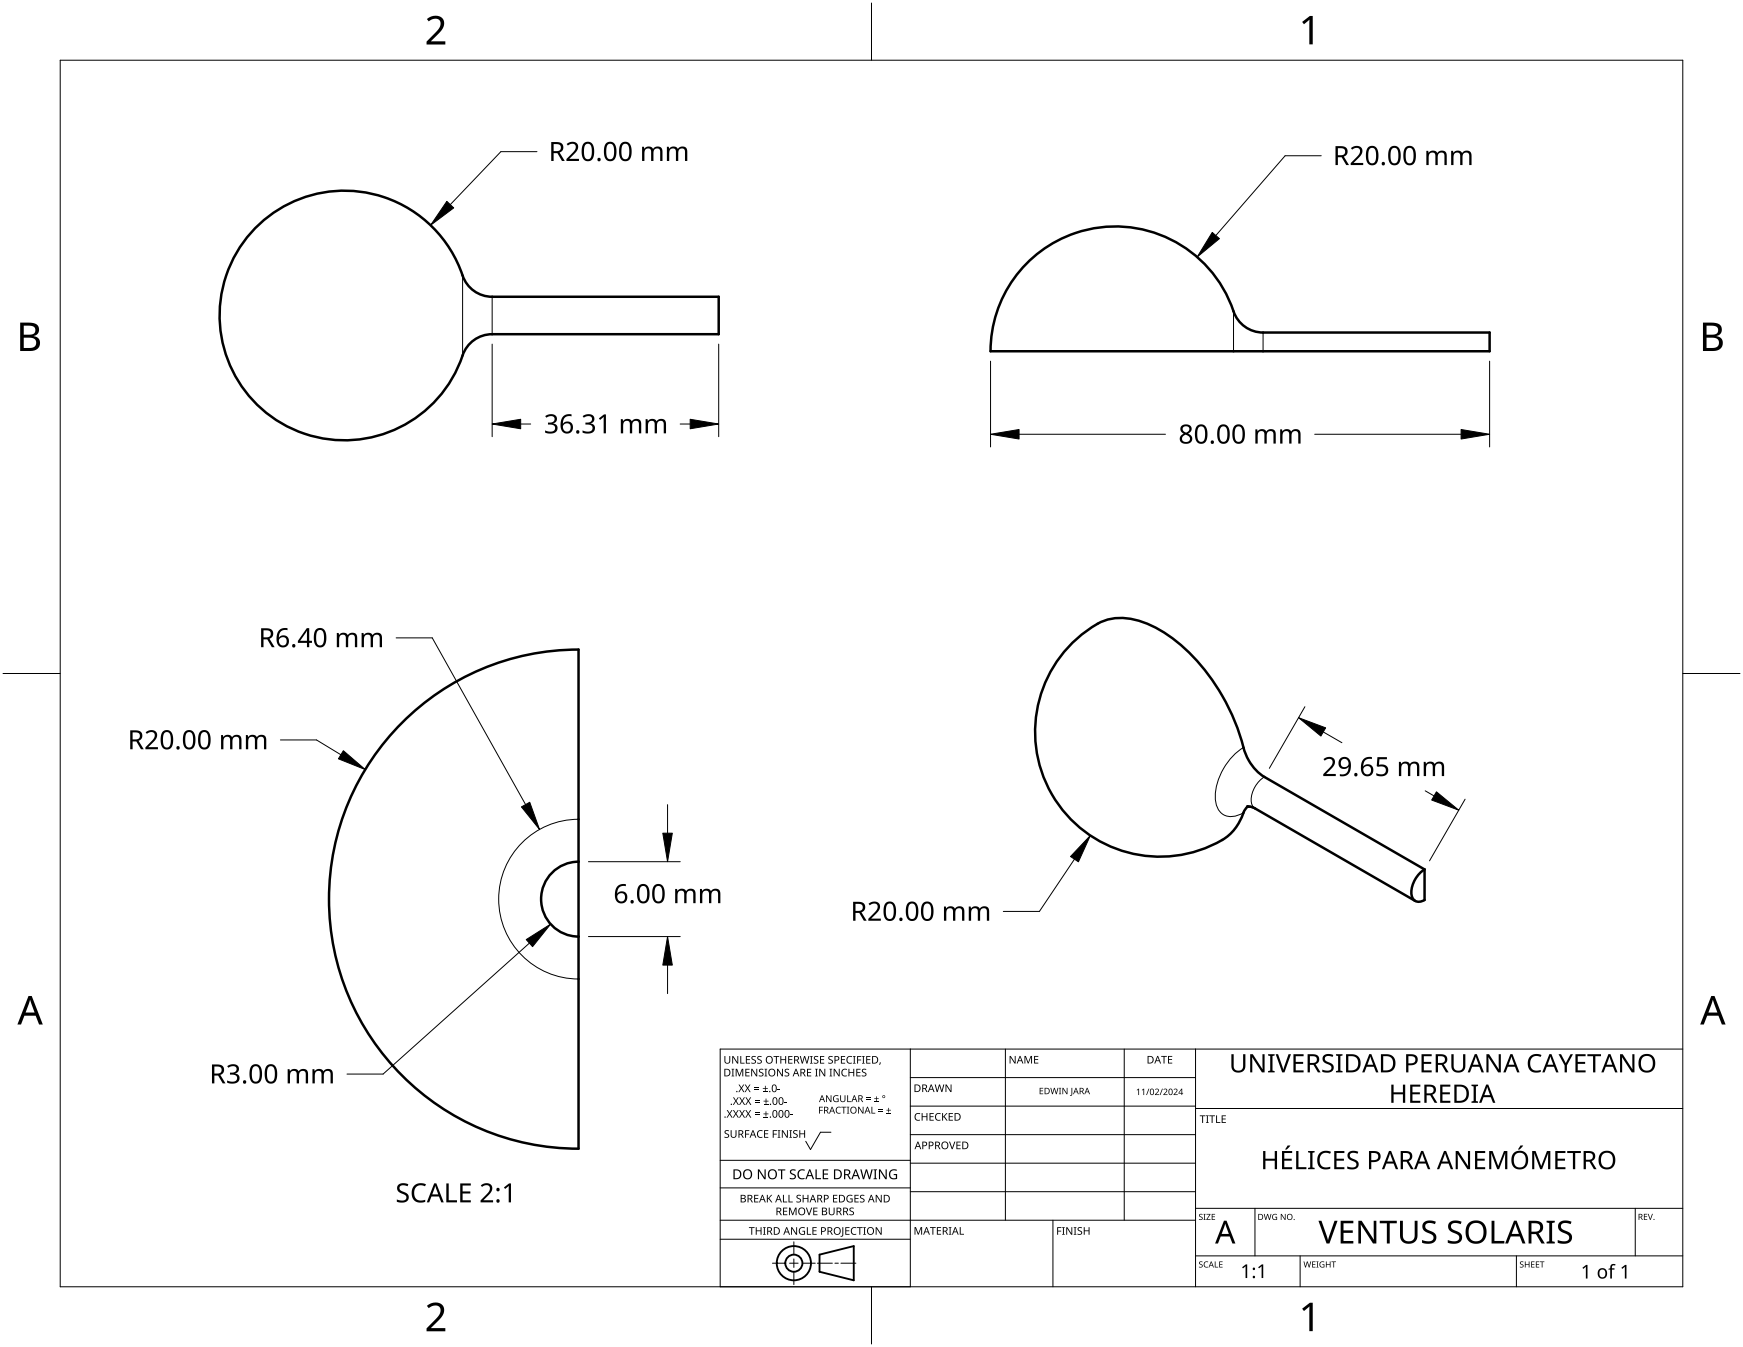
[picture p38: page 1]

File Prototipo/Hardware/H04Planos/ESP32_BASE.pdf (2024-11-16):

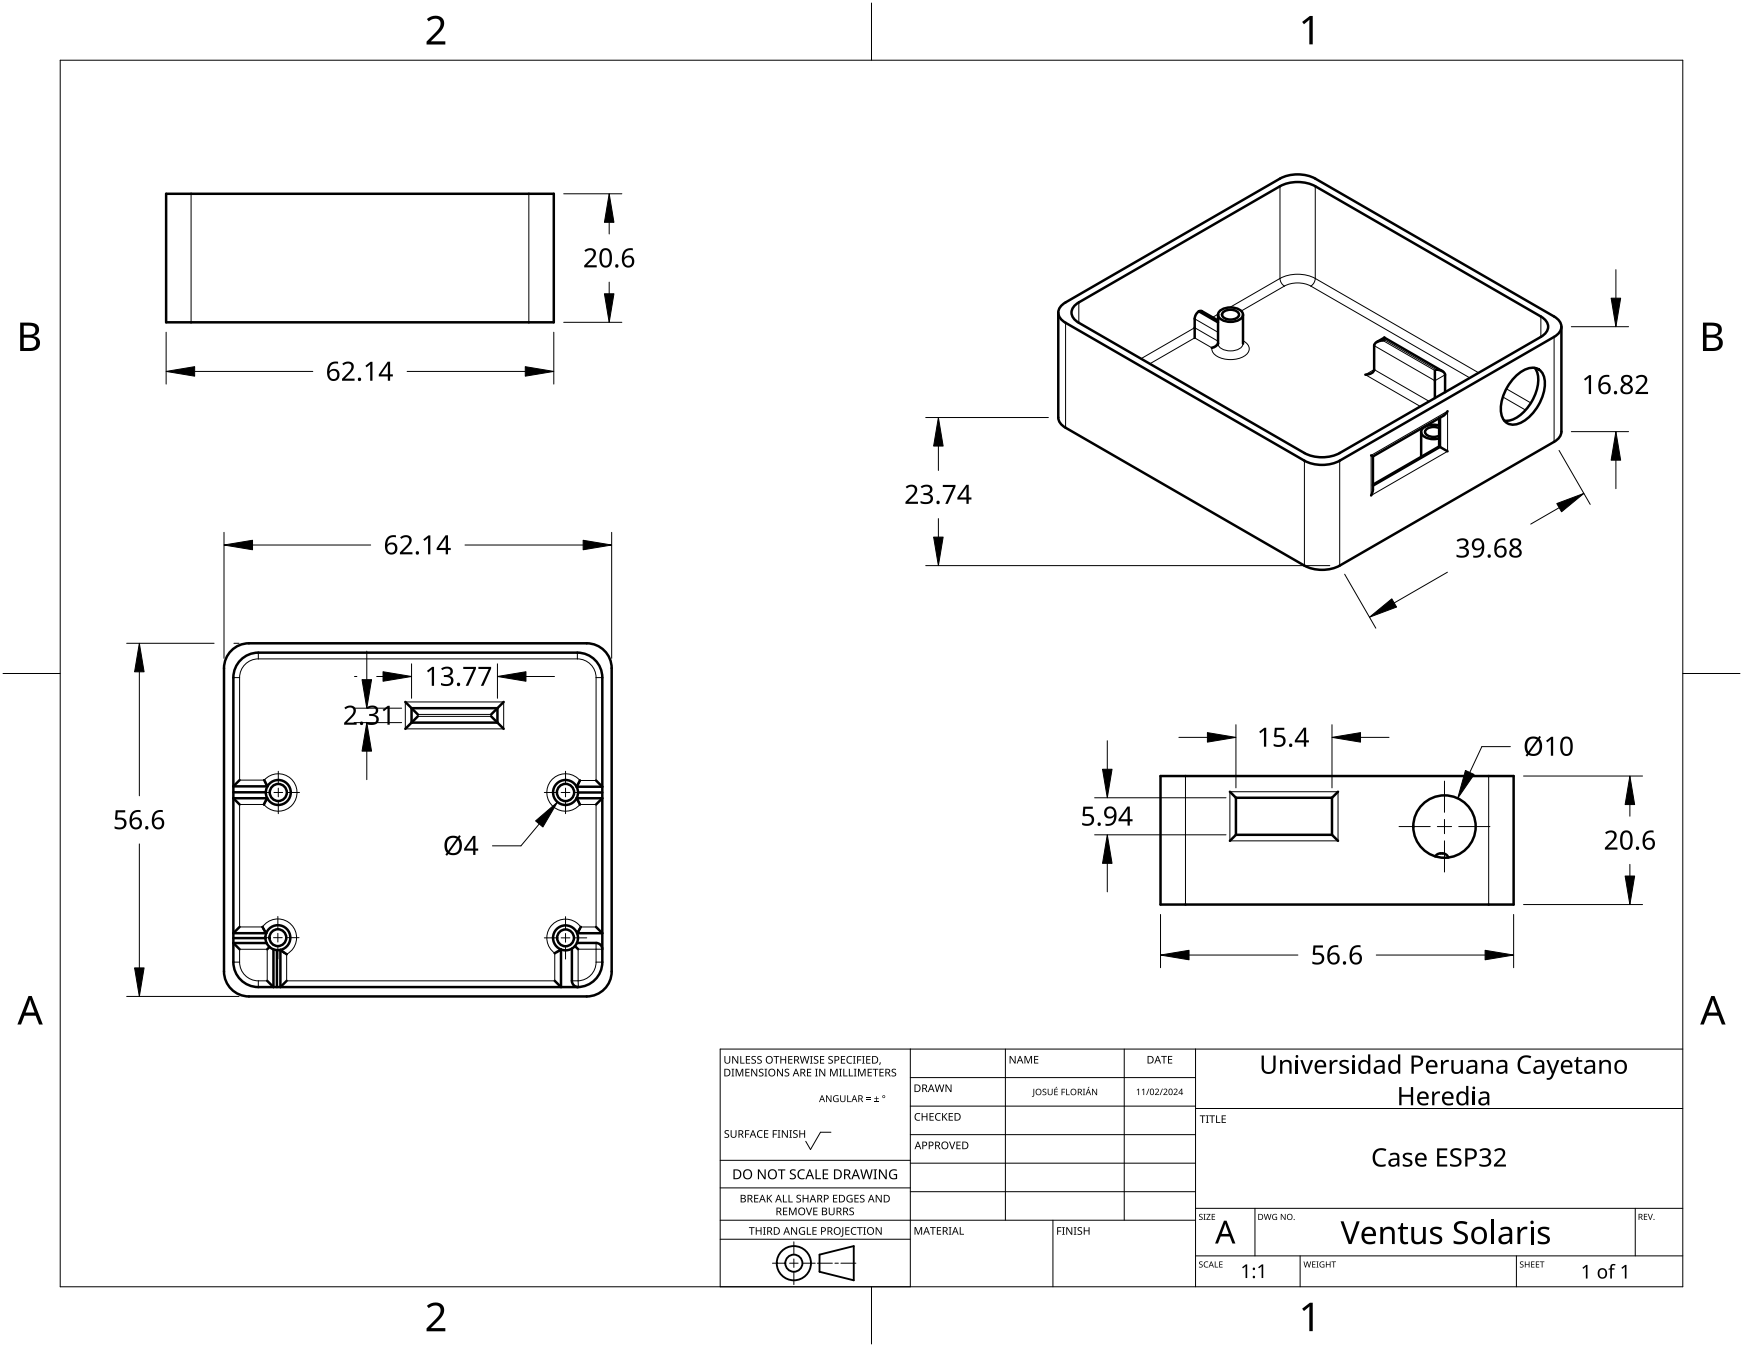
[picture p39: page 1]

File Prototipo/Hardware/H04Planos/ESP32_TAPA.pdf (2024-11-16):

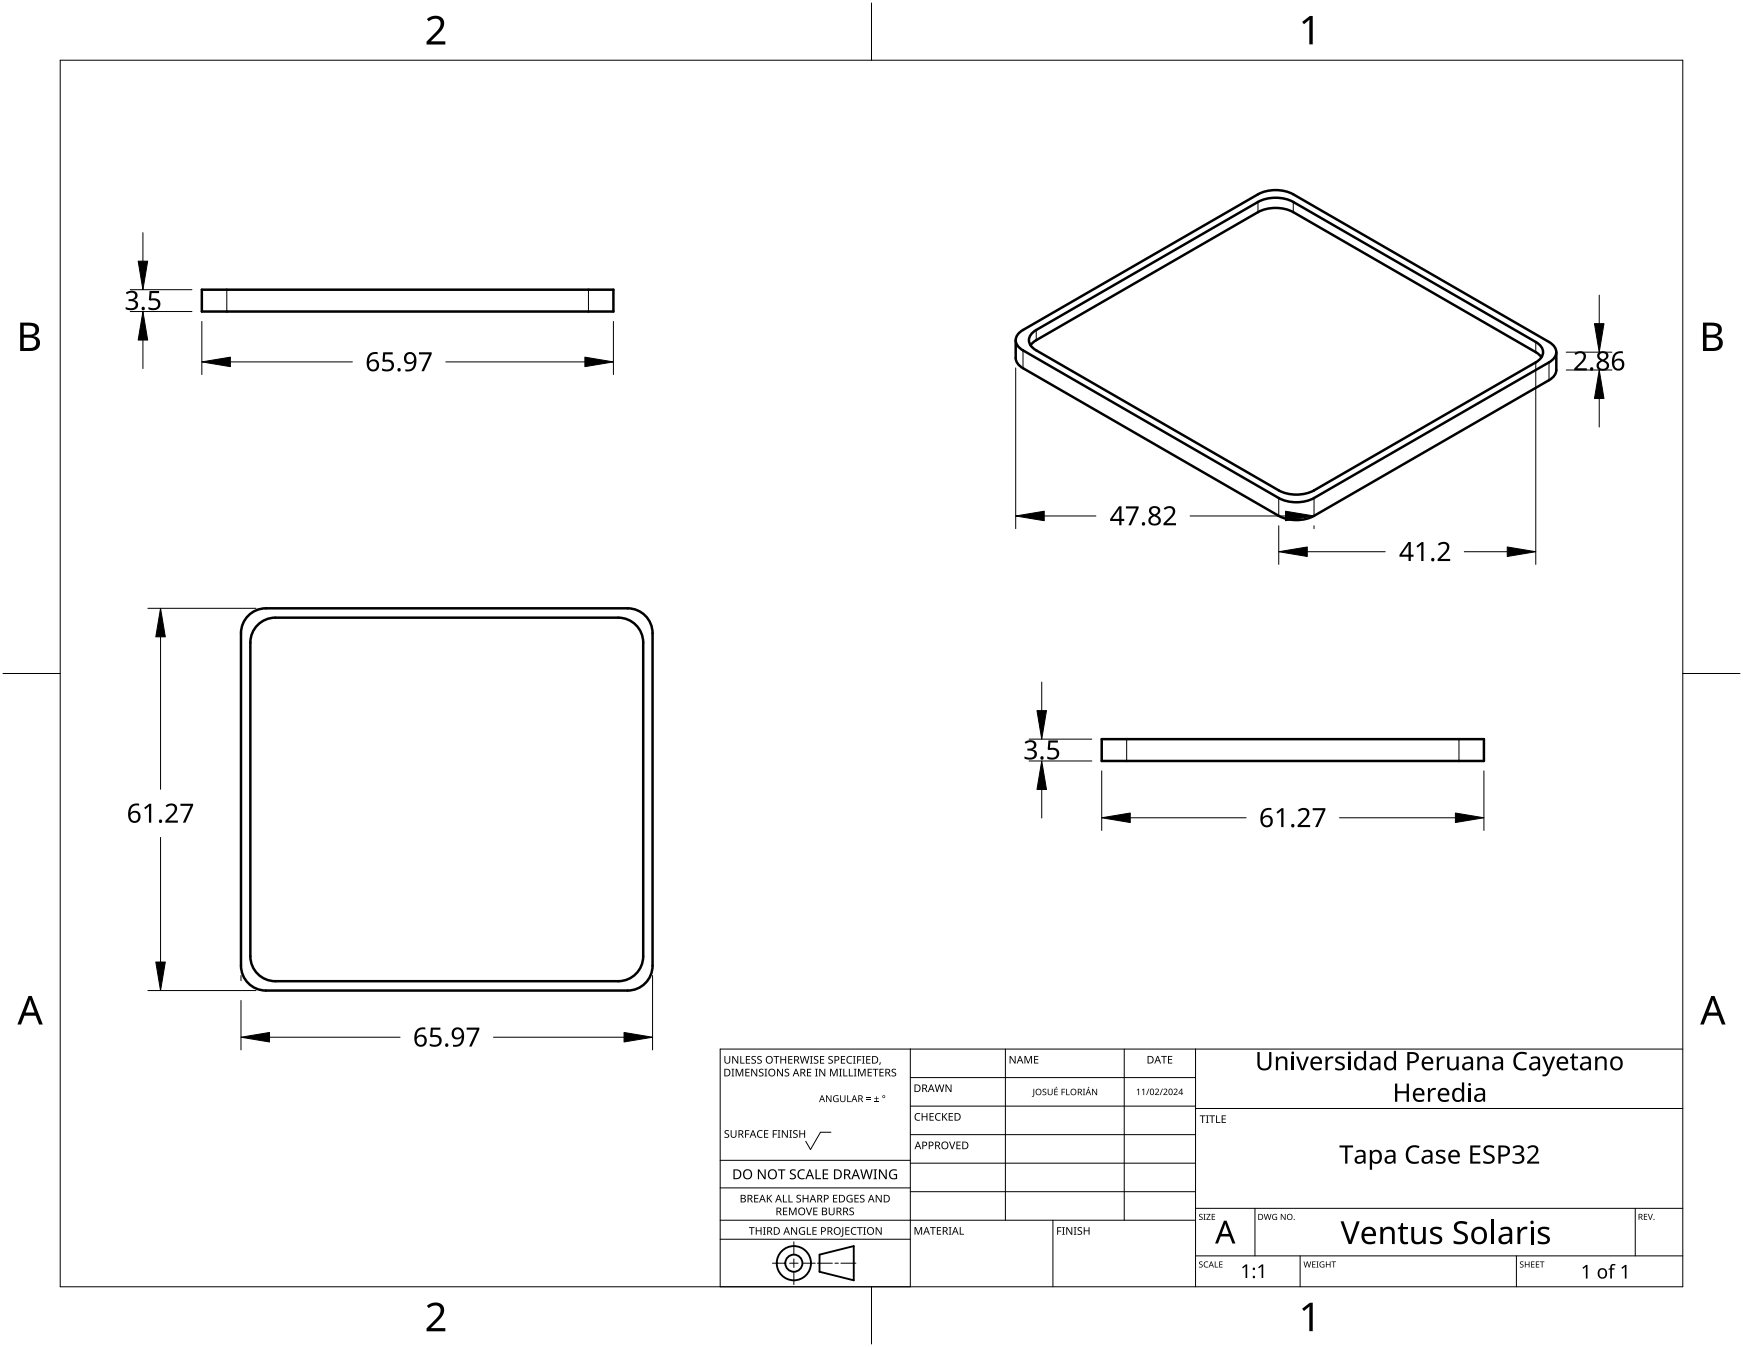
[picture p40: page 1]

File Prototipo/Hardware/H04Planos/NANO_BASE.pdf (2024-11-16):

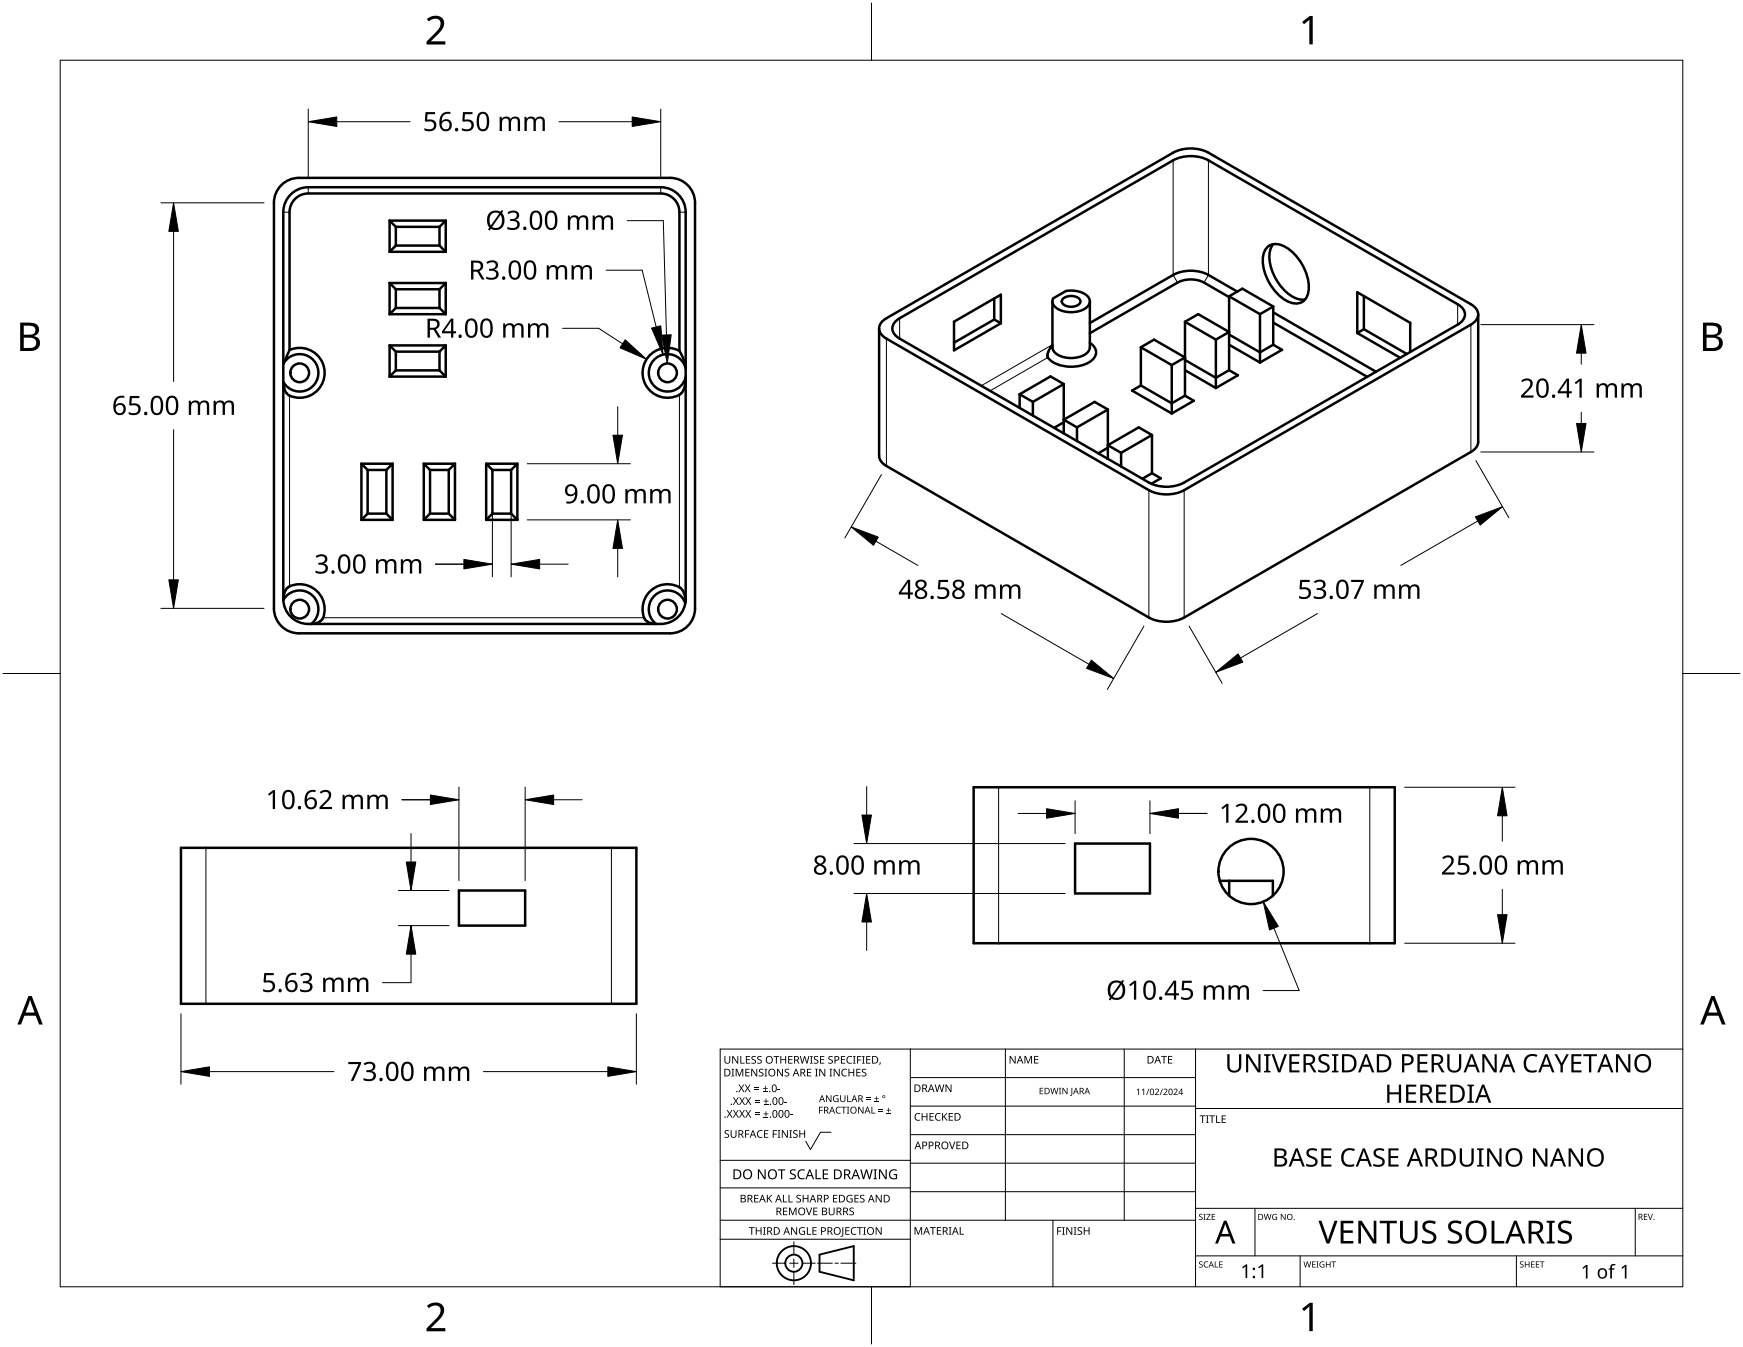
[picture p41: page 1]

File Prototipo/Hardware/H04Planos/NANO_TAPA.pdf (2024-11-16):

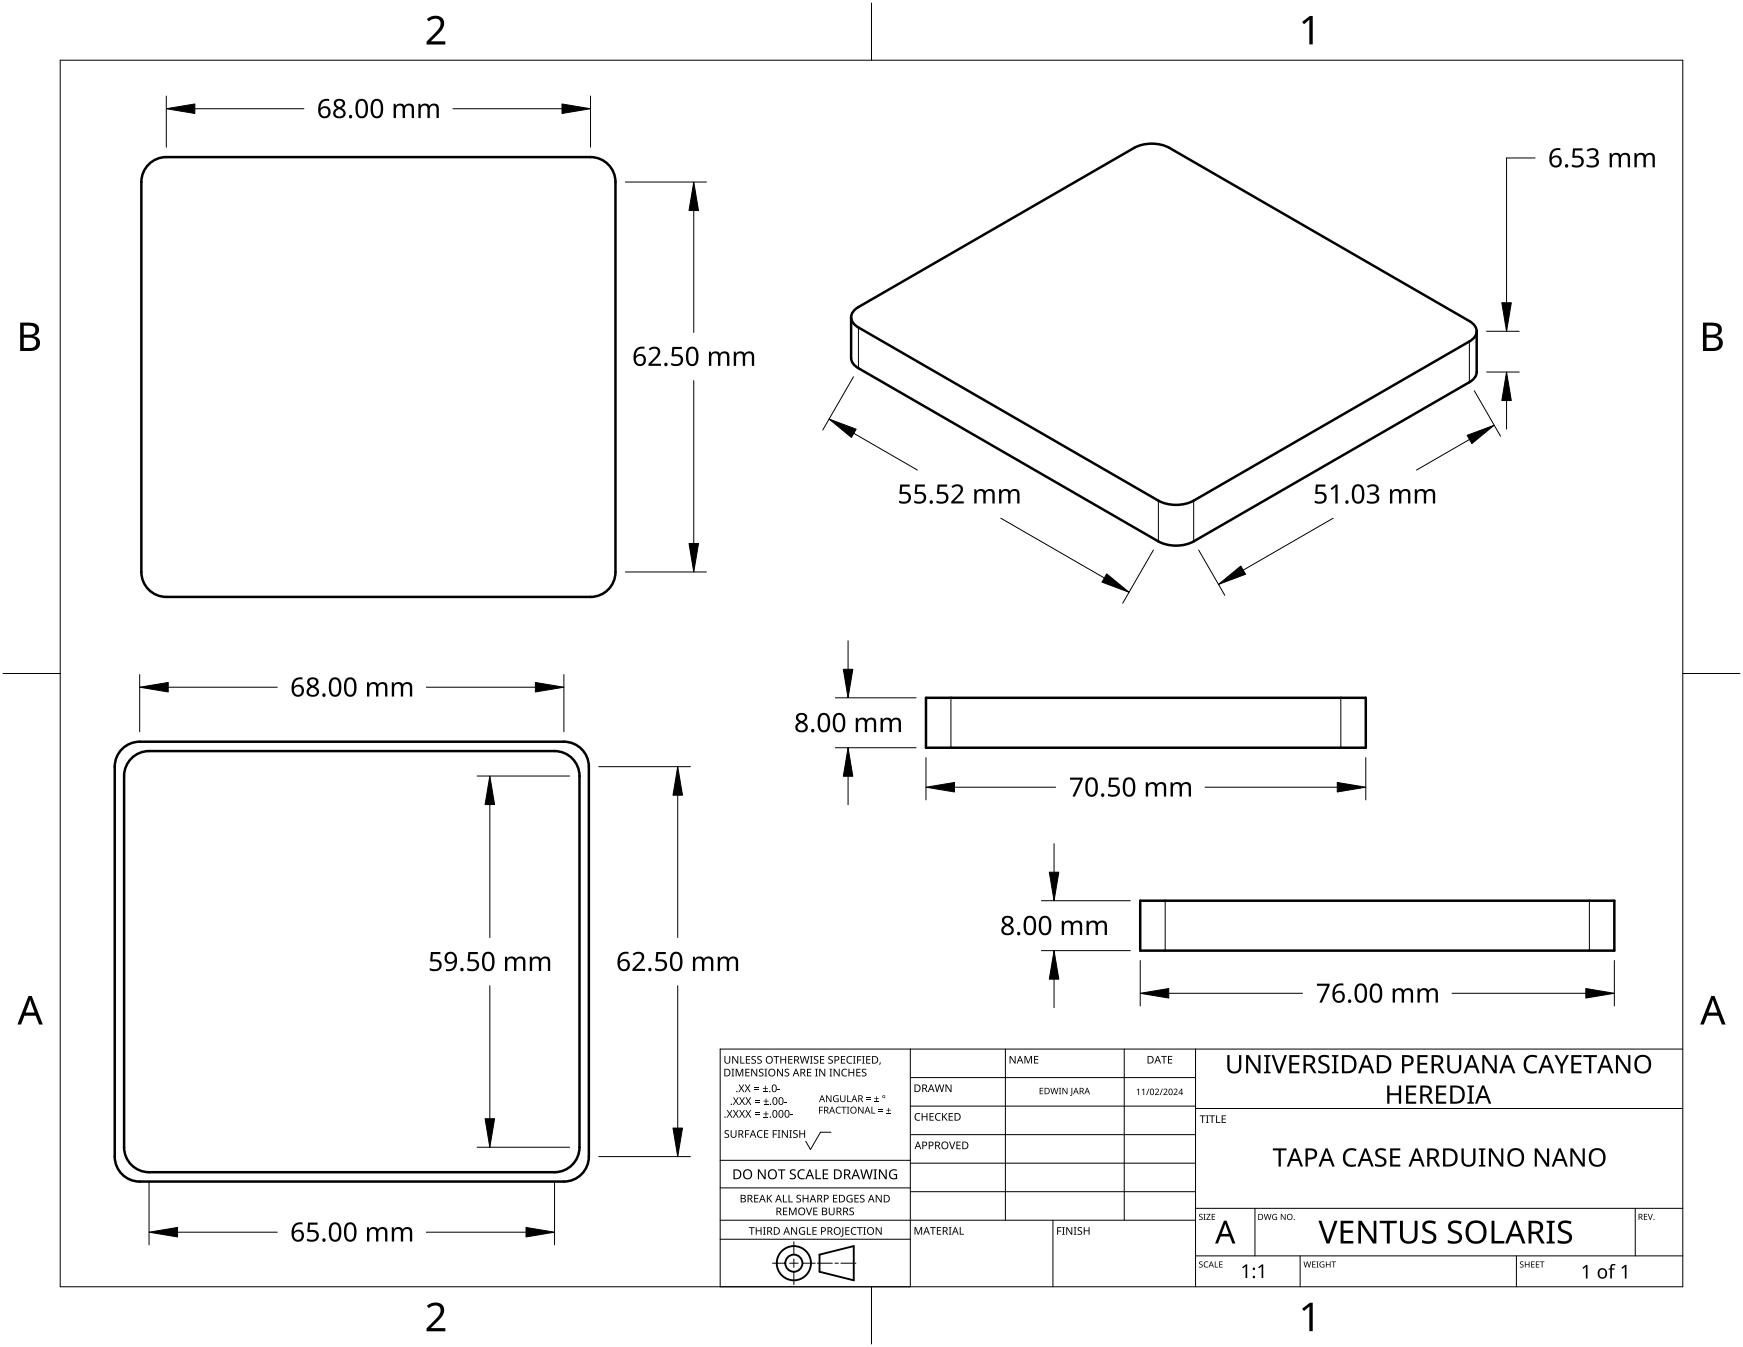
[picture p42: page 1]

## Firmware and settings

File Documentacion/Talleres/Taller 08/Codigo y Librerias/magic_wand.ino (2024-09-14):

/* Copyright 2020 The TensorFlow Authors. All Rights Reserved.
Licensed under the Apache License, Version 2.0 (the "License");
you may not use this file except in compliance with the License.
You may obtain a copy of the License at
    http://www.apache.org/licenses/LICENSE-2.0
Unless required by applicable law or agreed to in writing, software
distributed under the License is distributed on an "AS IS" BASIS,
WITHOUT WARRANTIES OR CONDITIONS OF ANY KIND, either express or implied.
See the License for the specific language governing permissions and
limitations under the License.
==============================================================================*/

#include <TensorFlowLite.h>

#include "tensorflow/lite/micro/micro_error_reporter.h"
#include "tensorflow/lite/micro/micro_interpreter.h"
#include "tensorflow/lite/micro/micro_mutable_op_resolver.h"
#include "tensorflow/lite/schema/schema_generated.h"
#include "tensorflow/lite/version.h"

#include "magic_wand_model_data.h"
#include "rasterize_stroke.h"
#include "imu_provider.h"

#define BLE_SENSE_UUID(val) ("4798e0f2-" val "-4d68-af64-8a8f5258404e")

namespace {

  const int VERSION = 0x00000000;

  // Constants for image rasterization
  constexpr int raster_width = 32;
  constexpr int raster_height = 32;
  constexpr int raster_channels = 3;
  constexpr int raster_byte_count = raster_height * raster_width * raster_channels;
  int8_t raster_buffer[raster_byte_count];

  // BLE settings
  BLEService        service                       (BLE_SENSE_UUID("0000"));
  BLECharacteristic strokeCharacteristic          (BLE_SENSE_UUID("300a"), BLERead, stroke_struct_byte_count);
  
  // String to calculate the local and device name
  String name;
  
  // Create an area of memory to use for input, output, and intermediate arrays.
  // The size of this will depend on the model you're using, and may need to be
  // determined by experimentation.
  constexpr int kTensorArenaSize = 30 * 1024;
  uint8_t tensor_arena[kTensorArenaSize];
  
  tflite::ErrorReporter* error_reporter = nullptr;
  const tflite::Model* model = nullptr;
  tflite::MicroInterpreter* interpreter = nullptr;
  
  // -------------------------------------------------------------------------------- //
  // UPDATE THESE VARIABLES TO MATCH THE NUMBER AND LIST OF GESTURES IN YOUR DATASET  //
  // -------------------------------------------------------------------------------- //
  constexpr int label_count = 3;
  const char* labels[label_count] = {"Circle", "1", "3"};

}  // namespace

void setup() {
  // Configurar los pines de los LEDs
  pinMode(LEDR, OUTPUT);
  pinMode(LEDB, OUTPUT);
  pinMode(LEDG, OUTPUT);

  // Start serial
  Serial.begin(9600);
  Serial.println("Started");

  // Start IMU
  if (!IMU.begin()) {
    Serial.println("Failed to initialized IMU!");
    while (1);
  }
  SetupIMU();

  // Start BLE
  if (!BLE.begin()) {
    Serial.println("Failed to initialized BLE!");
    while (1);
  }
  String address = BLE.address();

  // Output BLE settings over Serial
  Serial.print("address = ");
  Serial.println(address);

  address.toUpperCase();

  name = "BLESense-";
  name += address[address.length() - 5];
  name += address[address.length() - 4];
  name += address[address.length() - 2];
  name += address[address.length() - 1];

  Serial.print("name = ");
  Serial.println(name);

  BLE.setLocalName(name.c_str());
  BLE.setDeviceName(name.c_str());
  BLE.setAdvertisedService(service);

  service.addCharacteristic(strokeCharacteristic);

  BLE.addService(service);
  BLE.advertise();


  // Set up logging. Google style is to avoid globals or statics because of
  // lifetime uncertainty, but since this has a trivial destructor it's okay.
  static tflite::MicroErrorReporter micro_error_reporter;  // NOLINT
  error_reporter = &micro_error_reporter;

  // Map the model into a usable data structure. This doesn't involve any
  // copying or parsing, it's a very lightweight operation.
  model = tflite::GetModel(g_magic_wand_model_data);
  if (model->version() != TFLITE_SCHEMA_VERSION) {
    TF_LITE_REPORT_ERROR(error_reporter,
                         "Model provided is schema version %d not equal "
                         "to supported version %d.",
                         model->version(), TFLITE_SCHEMA_VERSION);
    return;
  }

  // Pull in only the operation implementations we need.
  // This relies on a complete list of all the ops needed by this graph.
  // An easier approach is to just use the AllOpsResolver, but this will
  // incur some penalty in code space for op implementations that are not
  // needed by this graph.
  static tflite::MicroMutableOpResolver<4> micro_op_resolver;  // NOLINT
  micro_op_resolver.AddConv2D();
  micro_op_resolver.AddMean();
  micro_op_resolver.AddFullyConnected();
  micro_op_resolver.AddSoftmax();

  // Build an interpreter to run the model with.
  static tflite::MicroInterpreter static_interpreter(
      model, micro_op_resolver, tensor_arena, kTensorArenaSize, error_reporter);
  interpreter = &static_interpreter;

  // Allocate memory from the tensor_arena for the model's tensors.
  interpreter->AllocateTensors();

  // Set model input settings
  TfLiteTensor* model_input = interpreter->input(0);
  if ((model_input->dims->size != 4) || (model_input->dims->data[0] != 1) ||
      (model_input->dims->data[1] != raster_height) ||
      (model_input->dims->data[2] != raster_width) ||
      (model_input->dims->data[3] != raster_channels) ||
      (model_input->type != kTfLiteInt8)) {
    TF_LITE_REPORT_ERROR(error_reporter,
                         "Bad input tensor parameters in model");
    return;
  }

  // Set model output settings
  TfLiteTensor* model_output = interpreter->output(0);
  if ((model_output->dims->size != 2) || (model_output->dims->data[0] != 1) ||
      (model_output->dims->data[1] != label_count) ||
      (model_output->type != kTfLiteInt8)) {
    TF_LITE_REPORT_ERROR(error_reporter,
                         "Bad output tensor parameters in model");
    return;
  }

}

void loop() {
  BLEDevice central = BLE.central();
  
  // if a central is connected to the peripheral:
  static bool was_connected_last = false;  
  if (central && !was_connected_last) {
    Serial.print("Connected to central: ");
    // print the central's BT address:
    Serial.println(central.address());
  }
  was_connected_last = central;

  // make sure IMU data is available then read in data
  const bool data_available = IMU.accelerationAvailable() || IMU.gyroscopeAvailable();
  if (!data_available) {
    return;
  }
  int accelerometer_samples_read;
  int gyroscope_samples_read;
  ReadAccelerometerAndGyroscope(&accelerometer_samples_read, &gyroscope_samples_read);

  // Parse and process IMU data
  bool done_just_triggered = false;
  if (gyroscope_samples_read > 0) {
    EstimateGyroscopeDrift(current_gyroscope_drift);
    UpdateOrientation(gyroscope_samples_read, current_gravity, current_gyroscope_drift);
    UpdateStroke(gyroscope_samples_read, &done_just_triggered);
    if (central && central.connected()) {
      strokeCharacteristic.writeValue(stroke_struct_buffer, stroke_struct_byte_count);
    }
  }
  if (accelerometer_samples_read > 0) {
    EstimateGravityDirection(current_gravity);
    UpdateVelocity(accelerometer_samples_read, current_gravity);
  }

  // Wait for a gesture to be done
  if (done_just_triggered) {
    // Rasterize the gesture
    RasterizeStroke(stroke_points, *stroke_transmit_length, 0.6f, 0.6f, raster_width, raster_height, raster_buffer);
    for (int y = 0; y < raster_height; ++y) {
      char line[raster_width + 1];
      for (int x = 0; x < raster_width; ++x) {
        const int8_t* pixel = &raster_buffer[(y * raster_width * raster_channels) + (x * raster_channels)];
        const int8_t red = pixel[0];
        const int8_t green = pixel[1];
        const int8_t blue = pixel[2];
        char output;
        if ((red > -128) || (green > -128) || (blue > -128)) {
          output = '#';
        } else {
          output = '.';
        }
        line[x] = output;
      }
      line[raster_width] = 0;
      Serial.println(line);
    }

    // Pass to the model and run the interpreter
    TfLiteTensor* model_input = interpreter->input(0);
    for (int i = 0; i < raster_byte_count; ++i) {
      model_input->data.int8[i] = raster_buffer[i];
    }
    TfLiteStatus invoke_status = interpreter->Invoke();
    if (invoke_status != kTfLiteOk) {
      TF_LITE_REPORT_ERROR(error_reporter, "Invoke failed");
      return;
    }
    TfLiteTensor* output = interpreter->output(0);

    // Parse the model output
    int8_t max_score;
    int max_index;
    for (int i = 0; i < label_count; ++i) {
      const int8_t score = output->data.int8[i];
      if ((i == 0) || (score > max_score)) {
        max_score = score;
        max_index = i;
      }
    }

    // Apagar todos los LEDs
    digitalWrite(LEDR, HIGH);
    digitalWrite(LEDB, HIGH);
    digitalWrite(LEDG, HIGH);

    // Encender el LED correspondiente
    if (strcmp(labels[max_index], "Circle") == 0) {
      digitalWrite(LEDR, LOW);   // Gesto círculo -> LED rojo
    } else if (strcmp(labels[max_index], "1") == 0) {
      digitalWrite(LEDG, LOW); // Gesto "1" -> LED verde
    } else if (strcmp(labels[max_index], "3") == 0) {
      digitalWrite(LEDB, LOW);  // Gesto "3" -> LED azul
    }

    TF_LITE_REPORT_ERROR(error_reporter, "Found %s (%d)", labels[max_index], max_score);
  }
}

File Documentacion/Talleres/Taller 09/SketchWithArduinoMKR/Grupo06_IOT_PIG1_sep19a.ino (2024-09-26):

#include "arduino_secrets.h"
#include "thingProperties.h"
#include <Arduino_MKRIoTCarrier.h>

MKRIoTCarrier carrier;

int moistPin = A5;

String relayState1 = "";
String relayState2 = "";

void setup() {
  // Initialize serial and wait for port to open:
  Serial.begin(9600);
  // Defined in thingProperties.h
  initProperties();
  
  ArduinoCloud.begin(ArduinoIoTPreferredConnection);
  
  CARRIER_CASE = true;
  carrier.begin();
  
  setDebugMessageLevel(4);   //Get Cloud Info/errors , 0 (only errors) up to 4
  ArduinoCloud.printDebugInfo();
  
  while (ArduinoCloud.connected() != 1) {
    ArduinoCloud.update();
    carrier.display.setTextSize(3);
    carrier.display.setCursor(20, 70);
    carrier.display.println("Waiting For");
    carrier.display.setCursor(5, 110);
    carrier.display.println("Connection...");
    delay(500);
  }
}

void loop() {
  ArduinoCloud.update();
 
  if (rele_1) {
    carrier.Relay1.open();
    relayState1 = "ON";
  } else {
    carrier.Relay1.close();
    relayState1 = "OFF";
  }
 
  if (rele_2) {
    carrier.Relay2.open();
    relayState2 = "ON";
  } else {
    carrier.Relay2.close();
    relayState2 = "OFF";
  }
  
  if (carrier.Light.colorAvailable()) {
    int none; // not gonna be used
    carrier.Light.readColor(none, none, none, luz);
  }
  
  temperatura = carrier.Env.readTemperature();
  humedad = carrier.Env.readHumidity();
 
  int rawMoistValue = analogRead(moistPin);
  humedadValor = map(rawMoistValue, 0, 1023, 100, 0);
}

void onHumedadChange() {
  // Do something when humedad changes
  Serial.print("Humedad changed to: ");
  Serial.println(humedad);
}

void onTemperaturaChange() {
  // Do something when temperatura changes
  Serial.print("Temperatura changed to: ");
  Serial.println(temperatura);
}

void onHumedadValorChange() {
  // Do something when humedadValor changes
  Serial.print("HumedadValor changed to: ");
  Serial.println(humedadValor);
}

void onLuzChange() {
  // Do something when luz changes
  Serial.print("Luz changed to: ");
  Serial.println(luz);
}

void onRgbColorChange() {
  // Do something when rgbColor changes
  uint8_t r, g, b;
  rgbColor.getValue().getRGB(r, g, b);
  if (rgbColor.getSwitch()) {
    carrier.leds.fill(carrier.leds.Color(g, r, b), 0, 5);
    carrier.leds.show();
  } else {
    carrier.leds.fill(0, 0, 5);
    carrier.leds.show();
  }
}

void onActualizacionPantallaChange() {
  // Do something when actualizacionPantalla changes
  carrier.display.fillScreen(ST77XX_WHITE);
  carrier.display.setTextColor(ST77XX_RED);
  carrier.display.setTextSize(2);

  carrier.display.setCursor(20, 30);
  carrier.display.print("Temperatura: ");
  carrier.display.print(temperatura);
  carrier.display.print(" C");

  carrier.display.setCursor(20, 50);
  carrier.display.print("Humedad: ");
  carrier.display.print(humedad);
  carrier.display.print(" %");

  carrier.display.setTextColor(ST77XX_ORANGE);
  carrier.display.setCursor(20, 70);
  carrier.display.print("Luz: ");
  carrier.display.print(luz);

  carrier.display.setTextColor(ST77XX_BLUE);
  carrier.display.setCursor(20, 90);
  carrier.display.print("HumedadValor: ");
  carrier.display.print(humedadValor);
  carrier.display.print(" %");

  carrier.display.setTextColor(ST77XX_BLUE);
  carrier.display.setCursor(20, 120);
  carrier.display.print("R1: ");
  carrier.display.print(relayState1);

  carrier.display.print("R2: ");
  carrier.display.print(relayState2);

  actualizacionPantalla = false;
}

void onRele1Change() {
  // Do something when rele_1 changes
  if (rele_1) {
    carrier.Relay1.open();
    relayState1 = "ON";
  } else {
    carrier.Relay1.close();
    relayState1 = "OFF";
  }
}

void onRele2Change() {
  // Do something when rele_2 changes
  if (rele_2) {
    carrier.Relay2.open();
    relayState2 = "ON";
  } else {
    carrier.Relay2.close();
    relayState2 = "OFF";
  }
}
